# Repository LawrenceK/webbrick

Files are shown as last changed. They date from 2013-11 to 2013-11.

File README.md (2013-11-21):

webbrick
========

webbrick firmware - This will be the open sourced code for the webbrick. As part of the windup of
webbricksystems this code is being open souced under a 3 clause BSD licence, please see licence.txt.

You will need a copy of the FORED WIZC compiler.

You will need a copy of wizc (www.fored.co.uk) note this was built with V14.01 see readme in the PIXIE-diff folder.

You will need the netmedia sitelinker package for the siteplayer.
(http://netmedia.com/siteplayer/webserver/downloads.html)

The build environment also requires a number of unix tools, these can be accessed by installing the cygwin tool kit.
(http://www.cygwin.com/)

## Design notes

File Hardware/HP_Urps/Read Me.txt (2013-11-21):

PCB
PCB Layout in EasyPC V6.0 latest Version V12
http://www.numberone.com/easy_pc_v12.asp
epj file defines the Gerber output

Firmware
Firmware compiled using Oshonsoft PIC Basic IDE
http://www.oshonsoft.com/pic.html

Programmed using Microchip MPLab

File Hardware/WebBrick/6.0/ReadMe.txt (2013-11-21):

Part changes since 23rd April

Switch changes to OMRON device

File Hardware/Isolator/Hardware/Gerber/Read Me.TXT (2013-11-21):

Notes on pads for switches Sw1 and Sw2

Due to the limitations of the PCB CAD system, the pads are shown as an oval shape with 3 holes.  The pad should have a single slotted hole with the two outside holes denoting the limits of the slot.

Please arrange for the CNC router to complete the slots in these pads.

AS.

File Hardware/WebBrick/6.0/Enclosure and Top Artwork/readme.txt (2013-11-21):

.vcd visual cad

Visual Cad - Enclosure.vcd
Export - enclosure.plt
Export - Enclosure.dxf
Export via something - Enclosure.png
Export via something - Enclosure.EPS
Export via something - Enclosure.wmf
Export for freehand - Enclosure.FH10
Final result - Enclosure.doc

11 May 2007
6.4Enclosure supercedes Enclosure.vcd

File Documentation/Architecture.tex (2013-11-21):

\section{Architecture Description}
\index{Architecture Description}

\subsection{Hardware}
\index{Hardware Architecture}

The WebBrick V6 is based around the PIC 18F6x22 chip and a NetMedia SitePlayer \index{SitePlayer} to create 
both HTTP and UDP command channels. The base 8 digital outputs are buffered through a Open collector 
drivers that can handle 12V 500mA drive with reasonable protection.

Some provision is made for input protection from excessive voltage by a combination of a current limiting
resistor and the clamp on the PIC chip inputs, edge triggered inputs are de-bounced in software.

WebBrick uses several properties of the SitePlayer:

\begin{itemize}

\item

SitePlayer can send commands to the PIC ship from its own web interface.

\item

SitePlayer can send commands to the PIC chip received over HTTP and UDP.

\item

The WebBrick can get the SitePlayer to send a UDP packet, the contents of which are 
managed by the PIC chip.

\end{itemize}

\subsection{Software Architecture}
\index{Software Architecture}

The WebBrick is based around a configurable state machine, this is driven by a variety
of triggers. The triggers can be generated by digital inputs, analogue inputs, temperature sensors
and network command. These state machines are configured on what to do when they receive a trigger, this
can be as simple as switch an output on or may involve changing the current scene and sending a network
message to the home gateway.
Although there 
are direct output control commands, in general operation the user configures the inputs to perform 
{\em actions} on outputs.

{\em actions} can be activated by:

\begin{itemize}

\item

Physical input pins, for example taking digital input 0 low momentarily would set the actions configured for 
state engine 0 in motion.  There is a de-bounce time on these circuits.
\item

HTTP request. \index{HTTP GET}

\item

Analogue or temperature inputs above or below configured thresholds.

\item

UDP packet\index{UDP}
\item

Scheduled Event\index{Scheduled Event}

\end{itemize}

\subsection{WebBrick Indicator LEDs}
\index{Indicator LEDs}

	The WebBrick has three indicators, which can been seen through the top translucent window.  They are:
	
	\begin{itemize}
		\item{Red} This indicator shows that the power to the process control and web server chips is healthy.
		\item{Green} This indicator shows that the web server chip is seeing a network link
		\item{Blue} This is the WebBrick heartbeat, it blinks a lot, it has different blinks at start-up, but once
				a WebBrick is running it will settle to a 1 sec blink rate. \(see section below\)
	\end{itemize}

\subsection{WebBrick Start-Up}
\index{Start-up sequence}

When power is applied to the WebBrick, the SitePlayer chip and the PIC chip will start.

It is important that any WebBrick has deterministic behaviour, therefore there is a settling period
before the configuration details from the EEPROM are transferred to the SitePlayer and hence the outside world.

The sequence is:

\begin{itemize}
	\item Power applied to WebBrick
	\item Internal web server  boots
	\item PIC boots waits 1-2 seconds for web server to settle
	\item PIC starts to transfer configuration to web server, this takes about 3 seconds
	\item If the PIC contains an IP address definition, this is set into the web server.  
        	Just before this point the WebBrick will have the 
		default address of 10.100.100.100.
	\item Operational Status set to 'Normal Operation' Interrupts enabled
	\item One Wire Bus searched for temperature sensors
	\item At 30 seconds after power up the internal real time clock is read, it is checked once a minute thereafter.
	\item Schedules are evaluated to see if any actions need to be executed.  i.e. 
		if the WebBrick is started at 10 o'clock and there is a scheduled action at 9 o'clock 
		this action will be executed.  Therefore if a WebBrick was controlling a central heating
		system it would recover from a power failure and carry on where it left off.
\end{itemize}

\subsection{WebBrick Heartbeat}

A LED connected to the PIC chip is used as a Heartbeat to show that the system is working.
It switches on and off at approx 1 second intervals with an equal off and on time once the 
WebBrick has completed its startup.
This LED is driven from the main program loop in the PIC chip.

If it stops flashing then the software has encountered an error, this would be a very dire state and if you ever see it
you should let us know.  We've only ever seen this happen with very noisy power supplies. 

During start-up the Heartbeat will flash quickly.  If the factory reset \index{factory reset} button is held in
at power-up the Heartbeat will remain on for two seconds before starting the load defaults and normal start-up operations.

[Future functionality] If the web interface is logged in then the LED will flash 
faster spending more time on and less time off, if the web home page has its controls disabled it will flash
slower spending more time off than on. [Not yet implemented]

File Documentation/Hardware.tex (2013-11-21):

\section{Hardware Details}

Version 4.2 of the PCB uses the following parts list:

    \begin{description}
    \item [IC1] PIC18F452-I/P (see Gotchas for note on Silicon revision levels)
    \item [IC2] 7805 5V Reg
    \item [IC3] LM358 dual OP Amp, buffers and doubles PWM outputs to give 0-10V
    \item [IC4] 2803A output buffer for 12V 500mA outputs
    \item [Xtal] 20Mhz (could be 40Mhz later)
    \item [Pulse Transformer]
    \item [SitePlayer] See www.siteplayer.com for details
    \end{description}

The following connectors and connections are used:

  \index{Connections}

    \begin{description}
    \item [DIN] Push button inputs, note that the PIC's internal pull-ups are ENABLED
    \item [DOL] Digital Outputs TTL level
    \item [DOH] Digital Outputs 12V 500mA max
    \item [JP4] Rotary Encoder pin 1 'Up' or A, pin 2 'Down' or B.
    \item [JP1 1] Analogue Input 0-5V
    \item [JP1 2-5]  Monitor Input TTL Level     
    \item [JP1 7] One Wire Bus Data \(See Also OWB below\)
    \item [JP1 8] DMX Passthru out TTL Level \(needs MAX232 chip or direct connection to Milford Instruments board\)
    \item [X2 1] Gnd for Analogue output
    \item [X2 2,3] Analogue Outputs
    \item [OWB] One Wire Bus
    \item [V+] A useful source of +5V
    \end{description}

\begin{figure}[H]
\centering

\caption{WebBrick Connections}
\end{figure}

Note that since version 4.2 of the PCB, pull-ups for the rotary encoder are included.

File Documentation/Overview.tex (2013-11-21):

\section{Overview}
\index{Overview}

What is a WebBrick? It is a network connected control and automation product designed around the principle 
of 'local control - global intelligence'. This means that most of the time control is handled locally but a 
system as a whole can be made more intelligent through the use of some central control
(for example the WebBrick Gateway) that provides the global intelligence. i.e. Lights for a room are a local issue, 
but heating is more of an overall control issue. This also means that you are
not dependant on a single control system for the complete system, you can always switch on the lights 
in this room while someone is making changes to a global control system.

Control can be done through a WebBrick's web interface, through its physical inputs or using remote commands.

\begin{figure}[H]
\centering
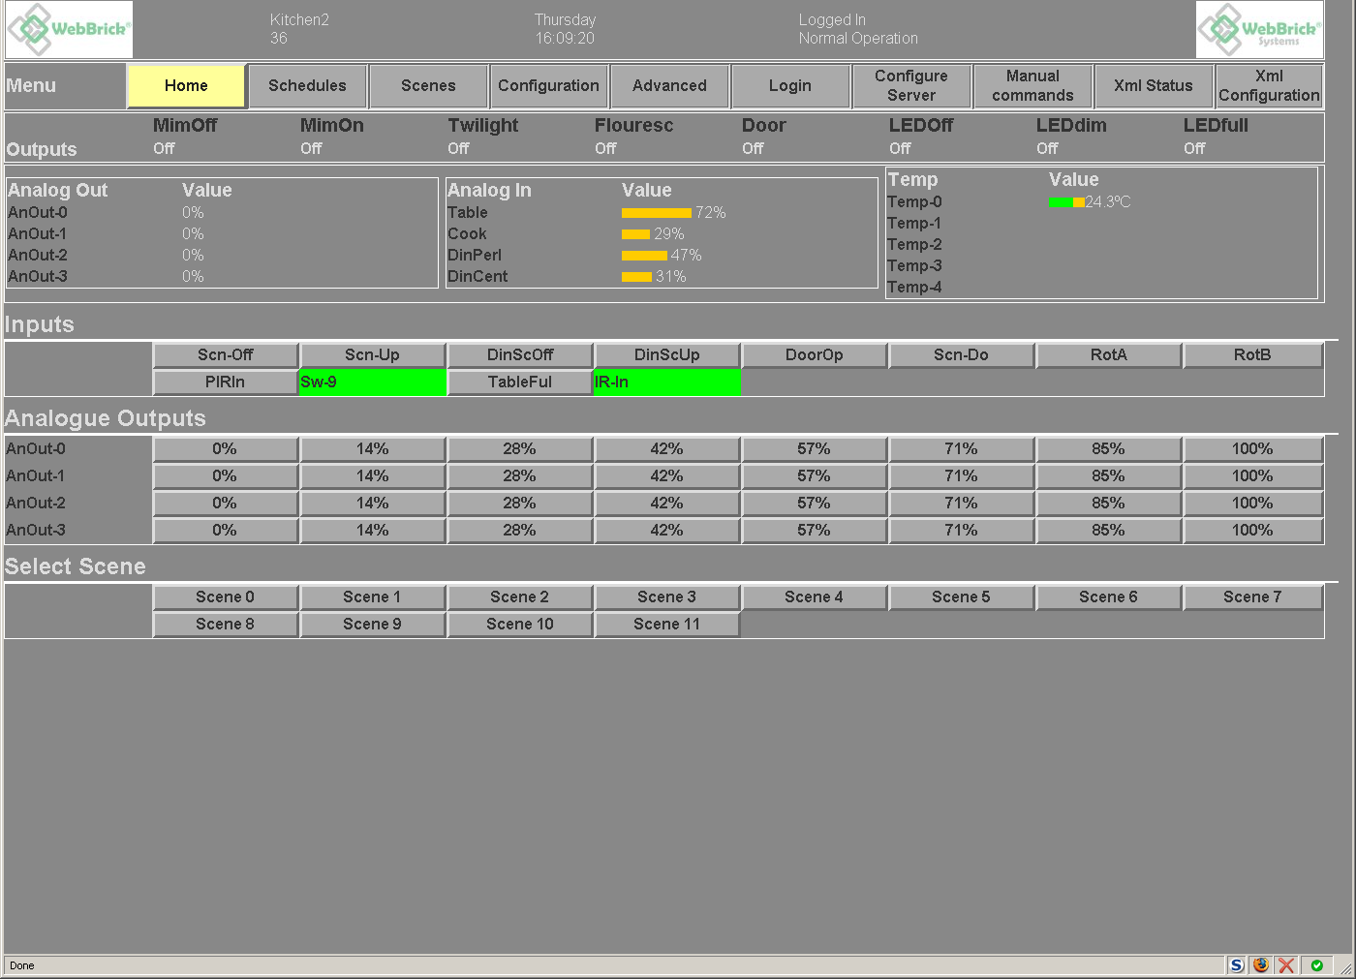
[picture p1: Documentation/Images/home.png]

\caption{Example of WebBrick Home Page}
\end{figure}
\subsection {History}

\index{History of WebBrick}

WebBrick started life as a bespoke project and in that incarnation there are 50-100 of them installed handling
tasks from building security to heating control, the largest setup uses 75+ WebBrick to manage a single house.
The latest incarnations (WebBrick6 and the WebBrick 7 Series) is a commercial project with added facilities.
The V6 WebBrick has an added IO board which provides screw terminals for all connections. It also has 4 Mains switching 
triacs and 2 Double pole changeover relays as well. We can also produce bespoke versions of the IO board
for specific uses.

\subsection {7 Series WebBrick}

The V6.4 WebBrick has the following connections:

\index{connections}

\begin{enumerate}

\item
8 Digital Outputs available as a combination of TTL and Open Collector drives.

In the default configuration 4 digital outputs are connected to mains triacs and can handle up to 500W 
per channel with a maximum of 1500W across all 4 channels. 2 of the Open collector outputs are connected to double pole 
changeover relays. 4 channels are available as TTL outputs.

The open collectors can sink to ground 3A, note that this was previously 500mA on the 6 Series

Digital Out 7 (TTL) can drive RC5 IR sequences to a suitable IR LED.

\item
8 Mimic outputs.  These are available at TTL and 12V levels are used to indicate the state of the WebBrick outputs.
The main functions of these mimics is to drive indicator LEDs found on push buttons. They are PWM modulated so that the
brightness can be modified for the on and off phases. The internal analogue and digital outputs can be configured to set 
the mimics to the on or off brightness(0..63) levels or they can be directly controlled from a system external to the WebBrick.

\item
12 Digital Trigger Inputs, TTL level - These can be treated as de-bounced push-buttons or toggle [MK] style inputs.  
The actual trigger point can be the rising edge, falling edge or both. When used in adjacent even/odd pairing Digital inputs will support 
rotary encoders.

All inputs have weak pullups so that switches can be connected with no further components involved.

Digital Input 11 can be configured to accept RC5 IR commands when connected to a suitable sensor.

\item
4 Analogue Outputs 0-10V. When the output level is changed, a new target value is set, these outputs 
adjust the output value over a time period (Fade Rate). Fade Rate is adjustable and can be as short as 200mS for full range 
change or as long as 50 Seconds.

\item
4 Analogue Inputs These are 0-5V input, high impedance - 47K, care must be taken not to exceed 5V on this pin, 
the web interface displays 0-100.

\item
One Wire Bus for up to 5 off Dallas DS18B20 temperature sensors.  On the 7 series the 5V supply and ground are specifically for temperature and humidity sensors.  The 5V supply is is specially decoupled and is limited to 10mA.  As a historical note this change was made to protect the WebBricks from shorts or excessive noise on sensors lines.

\item
RJ45 connection for 10Mb/s Ethernet.

\item
Serial output that can be configured for RS232, RS485 or DMX protocols.

\item
12V power connection

\end{enumerate}

\subsection {The Version 6.4 WebBrick}

The V6.4 WebBrick has the following connections:

\index{connections}

\begin{enumerate}

\item
8 Digital Outputs available as a combination of TTL and Open Collector drives, with an option for 8 more on bespoke 
developments. 
In the default configuration 4 digital outputs are connected to mains triacs and can handle up to 500W 
per channel with a maximum of 1500W across all 4 channels. 2 Of the Open collector outputs are connected to double pole 
changeover relays. 4 channels are available as TTL outputs.

\item
8 Mimic outputs.  These are available at TTL level are used to indicate the state of the WebBrick outputs.
The main functions of these mimics is to drive indicator LEDs found on push buttons. They are PWM modulated so that the
brightness can be modified for the on and off phases. The internal analogue and digital outputs can be configured to set 
the mimics to the on or off brightness(xx) levels or they can be directly controlled from a system external to the WebBrick.

\item
12 Digital Trigger Inputs, TTL level - These can be treated as de-bounced push-buttons or toggle [MK] style inputs.  
The actual trigger point can be the rising edge, falling edge or both. All inputs have weak pullups so that 
switches can be connected with no further components involved.

\item
4 Analogue Outputs 0-10V. When the output level is changed, a new target value is set, these outputs 
adjust the output value over a time period (Fade Rate). Fade Rate is adjustable and can be as short as 200mS for full range 
change or as long as 50 Seconds.

\item
4 Analogue Inputs This is a 0-5V input, high impedance, care must be taken not to exceed 5V on this pin, 
the web interface displays 0-100.

\item
One Wire Bus for up to 5 off Dallas DS18B20 temperature sensors.

\item
RJ45 connection for 10Mb/s Ethernet

\item
12V power connection

\end{enumerate}

Note that the Rotary Encoder connections from the pre 6.2 WebBrick have been incorporated into standard Digital Inputs, up to
6 rotary encoders can be supported.

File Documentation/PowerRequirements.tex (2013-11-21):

\section{Power Requirements}
\index{Power Requirements}

 This section deals with the power budget required to run a WebBrick.
 
 \subsection{Power Supply}
 \index{Power Supply}
 
    WebBricks should be run from a power supply that delivers 12.6V to 18V.  12.6V is a minimum to achieve a full 0-10V range on
    the analogue outputs.
    
    A quiescent WebBrick will consume 55-60mA at 12.6V, however the WebBrick in real use will be supplying power to a range of external items
    including:
 	
\begin{itemize}

\item{\bf LEDs} The WebBrick may drive up to 8 mimic LEDs, each consuming 5mA. {\it 40mA}

\item{\bf Relays} There are two relays, each using 30mA to hold the contacts closed. {\it 60mA}

\item{\bf Temperature Sensors} There may be up to 5 sensors, these are driven periodically. {\it 5mA peak}

\item{\bf Analogue Outputs} There are four buffered 0-10V outputs each capable of supplying 20mA. {\it 80mA}

\item{\bf General Output Drive} The digital outputs can each supply 5mA, although only four are presented as TTL.
if a rotary encoder is connected it will use 2mA.  Driving the triac and open collector gates requires 2mA each. {\it 40mA}

\end{itemize}

Total power budget, all outputs driven, all sensors connected 280mA.

\subsubsection{Back Feed}
\index{Back Feed}
 	
    Because the WebBrick consumes so little current, it is possible to inadvertently 
    power it through the coils of external relays connected to 
    the open collector outputs.  This only becomes an issue if one needs to fully power 
    down a WebBrick. To avoid this situation we suggest
    that the +ve side of relay coils are driven from the same power supply as drives the WebBricks.

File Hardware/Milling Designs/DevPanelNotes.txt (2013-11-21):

Notes for Milling Dev Panel
===========================

Holes -2.6 mm at 0.3mm increments.

Engraving -0.3 at 0.2mm increment

Home is at the very Left Hand Bottom Corner

Side Panel

Holes -1.9 mm at 0.3mm increments.

Home is where lines cross just on the inside of the screw columns

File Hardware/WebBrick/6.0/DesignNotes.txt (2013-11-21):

Use higher male connector.

Assembly

Download to SP on 192.168.1.250

Then Program PIC.

Make sure correct parts list to manufacturer.

Adjust position of screw holes in IO board, slightly too close together.

Factory test software. Test RTC.

Clock crytsla on bottom, case soldered. Add small cap as well.

Case drawings to subversion.

POE version.

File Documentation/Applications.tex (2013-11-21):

\section {Applications}

Here we provide some examples of use of the WebBrick. The great thing with the WebBrick is that a single device can
provide more than one activity. For example PIRs, can trigger video recording at all times. Can switch lights at night. 
Sound warning tones. In typical monitoring systems you need multiple devices because they do not interlink.

\subsection {Heating}

The notes in this section mostly consider that a WebBrick is taking the whole controller role.  Of course it's possible to
add extra global intelligence using a general purpose host computer, for example the WebBrick Gateway.

\subsubsection{Thresholds as set points}
\index{Thresholds}

	In the WeBrick architecture we use temperature sensors rather than thermostats.  We do this for a variety of reasons:
	
	\begin{itemize}
		\item{Controls} - there are no external controls for a temperature sensor.  This means that it can be sited
		where it both makes sense and is convenient.  For example under a kitchen worktop or directly bonded to a heated
		floor.
		\item{Accuracy and repeatability} - Old fashioned bi-metal strip thermostats close at one temperature and open at another.
		Adjusting the set-point is a mechanical operation.  Whereas the sensors we use have resolution to 0.1 deg C and an accuracy
		of 0.5 deg C.
		\item{Remote Control} - Using sensors to read the temperature means that the actions on thresholds are defined within the
		WebBrick.  Therefore the set points can be adjusted on a web page
	\end{itemize}

	With version 6.1 of the WebBrick it is now possible to control thresholds as an action.  Actions can be triggered from Digital Inputs
	and from Schedules.  We can also raise actions from multiple temperature sensors, so we can create zones and frost-stat functionality.
	
	Therefore if we build a heating control scheme using WebBricks we can schedule changes of set-points using thresholds.  We can also
	create {\em Boost} buttons that increase set-points.

\subsubsection{Modern Combi boiler, single Zone}

These generally have power applied all the time which is used to provide hot water and the central heating
is controlled by a mixture of a thermostat and timed events. In this case we would use scheduled events to
control the triacs and relays.  For example the output a triac feeding a relay that is controlled by one
of the temperature sensors using under and over thresholds. In effect the triac replaces the time switch
and the relay replaces the standard thermostat. The great benefits of this are:

	\begin{itemize}
		\item that the control can then be 
		overridden by local buttons for boost (e.g. Dwell 1 hour on boiler output)
		\item the use of a Home gateway system can use its calendar to switch heating off when home is empty. 
		\item a home gateway can access local weather feeds to adjust switch on times dependant on temperature forecasts.
		\item using the home gateway the home owner can control and make changes whilst away from the house, e.g. going home early.
	\end{itemize}

\subsubsection{Two zone heating system}
In this case we drive the boiler off a mains triac that is driven from a schedule entry. And drive two 
zone valves off the two relay outputs, these are triggered by high and low thresholds on two 
temperature sensors. Advantages are as for single Zone.

\subsubsection{Electric under floor heating}
These are great ways of heating floors for things like bathrooms but electricity is not the cheapest
heating source if over used.
So it would be nice for them to come on for timed periods and be able to boost at other times. 
In this case a single output can control the power to
the floor controller, this can be switched by timed events for getting up time and a push button to boost 
it at other times.

Note it is not always best to chain Triac based controllers so if the underfloor heating controller
uses a Triac we recommend using a Relay to power the floor from the WebBrick. Also underfloor heating 
can need power greater than the abilities of the onboard Triacs so an external relay is a good idea.

\subsubsection{Air conditioning}
Controlled by an external relay as the power consumption of these is higher than can be handled directly.
Control by a mix of time schedules and temperature thresholds.

\subsection{Outside lighting/Security Lighting}
This could be as simple as lighting that is timed to come on at dusk until dawn or it could be controlled
by PIR sensors that switch on all the lighting around a house. The PIR sensors may not necessarily be on the same 
WebBrick as the lights. For example on a big building there may be lights on all 4 sides of the building driven by 
different webBricks, on sensing movement on one side you may bring that side up to full brightness and all the other
sides to half brightness.

\subsection{Internal lighting}

\subsubsection{Night Lights}
Especially with the very young and very old it is great to have some low level lighting around a house at 
night, modern LEDs are very good for this drawing very little power. For one or two devices they can be 
switched directly from the digital outputs for heavier loads 3 in series with a resistor can be driven 
from a 12V supply and the open collector driver. If the power supply for a WebBrick is a sealed lead acid (SLA) battery
then this could also provide power for the LED lights so that they stay on during power cuts. With the low power
requirements the system could stay running off a 7 Amp Hour SLA battery for hours if not days.

Maplin (www.maplin.co.uk) 12V 7Ah battery (MG47B) £25, Charger (LL30H) £13.
TLC-direct (www.tlc-direct.co.uk) 12V 6AH battery £10+VAT

\subsubsection{Dimming lights}
For this: use dimmers that accept a 0-10V DC control voltage and wire these to the analogue outputs
from the WebBrick. For example the soundlab G018VA 4 channel dimmer can handle 4 channels of 5A each 
(Max 16A for the Unit).
(See also section on Outside World).

\subsection{Alarm Monitoring}
By connecting dry contacts from fire and burglar alarms to the WebBrick monitor inputs the WebBrick
in association can display the state of the alarm on a central display.The home gateway could then 
send SMS or email messages to alert the home owner. E.g. via www.textanywhere.com.

\subsubsection{Water sensors}
In the case of property in low lying areas water sensors could be installed in basements and under 
floor voids and configured to generate alarms.

\subsection{Household services}

\subsubsection{Water softener}
A sensor could be added to a water softener to detect low salt levels and alert the household through a central
display, especially useful when the device is installed in a basement where it is easily forgotten!

Capacitive sensors are particularly useful for sensing salt levels where the softener has GRP or plastic side walls.

\subsection{Home Cinema}
A home cinema setup can include more than just the audio and video equipment, you may 
also have (for example) roller screens and blackout curtains.

\subsection{Access control}

\subsubsection{Entry gates and doors}
With the use of RF remote systems connected to a WebbRick control of electric gates and garage doors can be handled
through a single system, the WebBrick. You can open gates and doors from the house before braving the elements to get 
access to your car and can then close them from the car as you leave the premises. When video is used as well you can 
open doors from work when your cleaner arrives as you will get a message when the door bell is pushed, you then check the 
camera system verify the identity and let release the front door.

\subsubsection{Camera systems}
A PIR trigger can be set up to start a camera system recording video images which are made available to you on a web interface.

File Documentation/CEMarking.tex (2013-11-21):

\section{CE Marking}

\index{CE Mark}

WebBrick WB10B60 is in conformity with the essential requirements of the directive 1999/5/EC. The product has been tested
 to the standard EN55022:1998 "EMC emmissions and immunity", using the limits described on EN55022 Class B CISPR22(B).

\subsubsection{General Description}

\subsubsection{Risk - High Temperatures}
\index{Risks ! High Temperatures}

The WebBrick has 4 triacs each rated at 2A with an overall rating of 6.3A.  If 6.3A of 240VAC is drawn through the WebBrick
the triacs will dissipate around 7W of heat.  There is sufficient heat sinking in the WebBrick to cope with this.  Internal temperatures
can rise to 85 Deg C.  It is important that the WebBrick is not housed in small totally enclosed areas.  Air circulation is best when the 
WebBrick is mounted in the vertical plane.

\subsubsection{Risk EMI}
\index{Risks ! EMI}

Since the WebBrick uses a number of microprocessors, it may be prone to electromagnetic emissions if it is not installed properly.  The current
standards are stringent and require that a typical installation radiates less that 2 nano watts of power in the RF range.

We recommend that CAT 5/5E/6/7 type cables are used and one core of each pair is connected to ground.

Further we suggest that you use a good quality clean 12V supply to the WebBrick to ensure that supply borne noise is radiated via the ground plane.

It is not a requirement to connect the mains ground to the electronic ground of a WebBrick.  However, please note that if you use the triacs for 
mains loads then the protective mains ground should be connected.  There is no internal connection between this protective ground and the 
electronic ground.

\subsubsection{Risk Software Failures}
\index{Risks ! Software}

The WebBrick contains about 40K assembler code, whilst this has been thoroughly tested, 
software errors cannot be ruled out.

\paragraph{WebBricks should not take the place of safety systems or override safety systems.}

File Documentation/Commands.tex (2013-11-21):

\section {Command Structure}
\index{command structure}

The WebBrick has a command interface that accepts command strings, these can be generated
by the Web interface and can also be sent to the WebBrick over the network. For network delivery
the commands can be sent using an HTTP URL with the command encoded in the parameters or a UDP transmission,
the HTTP use is preferable as you get an indication of whether the command was received at the WebBrick.

\subsection{General}
\index{Command Structure, General}
All commands start with a 2 character identifier, and are followed by any required parameters and terminated 
by a colon (':') character after the parameters, 
which means end-command. Each parameter to a command is terminated by a semi-colon (;). In this document 
items in \param{is a user parameter} 
and should be replaced with real world values. Items in [...] are optional parameters, therefore are not essential to replace. Generally the first character within the 2 character 
identifier identifies the command group and the second identifies the entity type. No extra blank spaces should
be inserted into the command as unexpected things may happen or the command be rejected.

These commands can be sent to the WebBrick in two ways:

\begin{enumerate}
	\item By encoding the parameters into 
	an HTTP URL and accessing that URL
	\item or by sending a UDP packet to the WebBrick with a 
	correct Siteplayer header on it for delivery to the PIC chip. 
\end{enumerate}

The embedded UI uses the 
HTTP URL approach and it is recommended that this approach is used for external systems. If you want
to use UDP packets look at the python code in wbUdp.py for details.

The HTTP URL to be used is http://\param{ip Address}/cfg.spi?com=\param{commandString}
Where \param{ip address} is the WebBricks IP address or host name.
and \param{commandString} is one of the command strings documented here. Note some commands will
need you logged in for them to be processed.

To make it easier to understand the command strings the first character is generally used as follows:

\subsubsection{command groups}
\begin{tabular}{l|p{12cm}}
1st Letter&Command Group\\
\hline
C&Configure\\
S&Set\\
N&Name\\
D&Digital\\
A&Analogue\\
I&Infra Red\\
T&Thresholds\\
\end{tabular}

And the second character generally identifies the target channel type, as follows:
\subsubsection{entity type}
\begin{tabular}{l|p{12cm}}
2nd Letter&entity type\\
\hline
D&Digital input\\
A&Analogue Output\\
I&Analogue input\\
O&Digital Output\\
T&Temperature\\
C&Scene\\
R&Serial comms or rotary encoder\\
\end{tabular}

\subsubsection{Trigger Configuration}
\index{Trigger!configuration sequence}
\index{Trigger sequence}
A lot of the commands take a sequence of parameters referred to as a Trigger sequence, this 
defines what is to happen when a trigger event occurs, for example a digital input or 
a temperature threshold being crossed. 

The sequence of parameters is:

\param{A\textbar{}D\textbar{}S\textbar{}T\textbar{}I}\param{targetChn}; \param{SetPointNr}; \param{actionType}; \param{DwellNr}; \param{UDPType}; \param{AssociatedValue} [; \param{OptValue}]:

Where:

\begin{tabular}{l|p{12cm}}
Parameter&Description\\
\hline
\param{A\textbar{}D\textbar{}S\textbar{}T\textbar{}I}&is a single character that identifies whether the target channel is an 
analogue output(A), a digital output (D), a Scene (S), a Temperature sensor (T), or Infra Red Send\\
\param{targetChn}&is the channel number or Scene being targeted\\
\param{actionType}&is one of the values from the Action table (range 0-15) In the case of a Scene this
is used as the action for all analogue channels that are not marked to be ignored and for digital 
channels marked for On in the scene configuration.\\
\param{DwellNr}&is a dwell number and is ignored if the actionType is not a dwell. Note for DT command dwell 
is passed in seconds and not as a dwell index.\\
\param{SetPointNr}&is a setpoint number and is ignored if the target channel is not analogue, Note a Scene is
not an analogue channel and the SetPoint is taken from the Scene.\\
\param{UDPDo}&identifies whether a UDP packet type is to be sent\\
\param{AssociatedValue}&is a number associated with the action.\\
\param{OptValue}&is an optional reserved value.\\
\end{tabular}

\subsubsection{Actions}
Each trigger can cause one of the following actions to be performed on an output channel.

\begin{tabular}{l|l|p{12cm}}
Nr&Action&Description\\
\hline

0&None&no action\\
1&Off&switch off\\
2&On&switch digital channels on or an analogue channel to a setpoint.\\
3&Momentary&Switch a channel on for a small time period circa 200mS.\\
4&Toggle&Turn an on channel off and an off channel on. For analogue channels if the current setting is greater than 0 it is deemed to be on.\\
5&Dwell Always&Always Switch a channel on for a configured time period, if lamp already on this will switch off after a time period.\\
6&Dwell-Cancel&If a channel is Off Switch the channel on for a configured time period. 
If the channel is already On then switch the channel Off immediately.\\
7&Next&Move a channel to its next higher state, for analogue channels this is to the next set point, for digital channels this is equivalent to a toggle. If the target is any Scene change the current scene at the web brick up by one.\\
8&Prev&Reverse of Next, Down Setpoint, Toggle, Previous Scene.\\
9&SetLowThreshold&Change the low threshold for one of the analogue input or temperature sensor\\
10&SetHighThreshold&Change the high threshold for one of the analogue input or temperature sensor\\
11&AdjustLowThreshold&Move the low threshold for one of the analogue input or temperature sensor\\
12&AdjustHighThreshold&Move the high threshold for one of the analogue input or temperature sensor\\
13&SendIR&Send a command over the Infra Red emitter, RC5 only, the target RC5 channel is the command code 
and associated value is the RC5 address.\\
14&Up&Take a channel up a step, generally used for analogue outputs.\\
15&Down&Take a channel down a step, generally used for analogue outputs.\\
16&Set Dmx&Set a DMX channel to a level.\\
17&Count&Sets the channel to count mode.\\
18&Dwell On&Switch a channel on for a configured time period if it is not already on.\\
19&Dwell Off&Switch a channel off after a configured time period.\\
\end{tabular}

Notes
\begin{itemize}
\item Toggle, On and Off actions all override a current Dwell command.
\item A Dwell command issued during a current Dwell period will reset the Dwell time.
\item A Dwell Cancel command issued during a current Dwell period will end the dwell. A Dwell Cancel issued 
outside a Dwell period will switch the output on for the Dwell time.
\item At the end of an analogue dwell the output will return to the level prior to the dwell, this 
is useful for setting lights
to a low level and bringing them high on some trigger, e.g. security PIR.
\item Channel numbers are zero based for the internal commands.
\item Scenes are in two banks, one bank of 8 and one bank of 4, when performing Next and Prev Scene the scene change 
stays within the bank that the trigger definition identifies by selecting one of the scenes within the chosen bank.
\item String parameters cannot contain any of the characters '\textless{}\textgreater{}\&
\item Analogue channels go up and down setpoints with Next/Prev and step the level the rotary step value with Up/Down \&
\item Some commands are meaningless with some outputs, where possible reasonable actions are chosen. i.e. for digital 
channels Next/Prev/Up/Down are treated as a toggle command\\
\end{itemize}

\subsection{Error Codes}
These may be displayed in the header of the webbpage and may appear in the xml status.

    \begin{tabular}{l|l}
    Value&Description\\
    \hline
    0&No Error.\\
	1&Bad Command.\\
	2&Bad Parameter.\\
	3&Not Logged In.\\
	4&Address Locked, attempt to change IP address on address locked webbrick.\\
	5&In Startup state.\\
	6&No Command yet issued, post startup state.\\
    \end{tabular}
	
\subsection{Command summary}

\subsubsection{Static configuration commands}

\begin{tabular}{l|p{12cm}}
Command&Function\\
\hline
ND&Name digital Input\\
NO&Name digital output\\
NI&Name analogue input\\
NA&Name analogue output\\
NT&Name temperature sensor\\
NN&Name node\\
CD&Configure digital input\\
CI&Configure analogue input\\
CT&Configure temperature input\\
CS&Configure set point\\
CW&Configure dwell\\
CR&Configure serial interface.\\
CE&Configure scheduled event\\
CC&Configure a scene\\
SN&Set node number\\
SF&Set fade rate\\
SM&Set mimic brightness levels for on and off signals, and fade rate\\
CM&Configure mimic channels for analogue and/or digital outputs\\
ST&Set Time\\
SD&Set Date\\
SR&Set rotary encoder step\\
SI&Set Internet address\\
SA&Set IP address with verified MAC address; the !WebBrick sets its IP address to the specified value only if its 48-bit MAC address matches that supplied.  This command can be used with UDP broadcasts to set IP addresses when several WebBricks on a network have the same initial IP address.\\
SP&Set password for indicated security level\\
SO&Set option on (1) or Off (0) (Use with care: currently deprecated, and not reflected in XML configuration)\\
IR&Enable infrared receive\\
IT&Enable infrared transmit\\
IA&Sets the RC5 Infrared address for receiving\\
% Private command.
%ZO&Security option setting (e.g. IP address locking)\\
\end{tabular}

\subsubsection{Dynamic status setting commands}

\begin{tabular}{l|p{12cm}}
Command&Function\\
\hline
DI&Trigger digital input\\
DO&Set digital output\\
DT&Invoke a trigger event action using the supplied parameters. The parameters are a full trigger definition as can
be attached a local event source, i.e. digital input, but are acted upon when received. Note dwell is passed in seconds and not as a dwell index.\\
DM&Set one or more mimic outputs to specified levels\\
DA&Requests web brick to send a small number of UDP attention packets within a few seconds (currently: one immediately, and one more within a second).  This is used for WebBrick discovery.  (cf. factory reset causes attention packets to be sent every few seconds for a minute.)\\
AA&Set analogue output to one of the setpoints or to an absolute level.\\
SC&Set scene\\
SS&Set operational state\\
TA&Modify dynamic threshold for analogue input\\
TT&Modify dynamic threshold for temperature sensor\\
\end{tabular}

\subsubsection{Miscellaneous WebBrick control commands}

\begin{tabular}{l|p{12cm}}
Command&Function\\
\hline
LG&Login to security level associated with password - also logout.\\
RT&Re scan 1-wire bus for new devices\\
RU&Refresh web user interface data\\
RS&Reboot Siteplayer, PIC chip delays a while and then rebuilds the UI data.\\
RB&Reboot PIC\\
RI&Set RS485 driver off, input mode\\
RO&Set RS485 driver on, output mode\\
RD&Send serial data\\
IS&Sends an RC5 infrared command (channel) over a configured infrared emitter\\
\end{tabular}

\subsection{Commands}

All command are listed here.

\subsubsection{AA - Analogue output control}
\index{Analogue output control}
\index{Analogue Output ! control sequence}
AA\param{chn};[S\param{nn}\textbar{}\param{nn}]  Set Analogue output setpoint or absolute

Set an analogue output to a specific level.
chn is the analogue output channel number. If the output value is S\param{nn} then \param{nn} is the setpoint,
otherwise \param{nn} is the output level as an absolute value of between 0-100\%. 

e.g.
AA1;S1:

\subsubsection{CC - Configure Scene}
\index{Configure Scene}
CC\param{nr};[NFI][NFI][NFI][NFI][NFI][NFI][NFI][NFI]; [I\textbar{}S\param{nn}]; [I\textbar{}S\param{nn}]; [I\textbar{}S\param{nn}]; [I\textbar{}S\param{nn}]:

Configure a scene. A scene consists of optional settings for all the digital and analogue channels. Any channel
may be marked as Ignore (do not change). Digital channels also be marked as On or Off, whilst analogue channels
can be given a set point. The first group [NFI] is for the digital channels and is repeated as many times 
as required to cover the digital channels where a change is required, i.e. if you only want to modify 
digital channels 0, 1, 2 then you only need list 3 entries. If you want to only affect channel 8 (or 16) then
you must send all the preceding ignore's (I). Similarly for the analogue channels where each later entry is
optional if you have already specified the required changes.

e.g.
CC0;NFNFNFNF;I;S1;S2;S3:
CC1;NF:
CC3;NF;S0;S1;S2;S3:

\subsubsection{CD - Configure Digital Input}
\index{Configure Digital Input}
CD\param{chn}; \param{A\textbar{}D\textbar{}S}\param{targetChn}; \param{sp}; \param{actionType}; \param{dwell}; \param{udpType}; \param{AssociatedValue} [; \param{OptValue} [; \param{Options}]]:

Configure one of the digital inputs.
chn is the digital input channel number from 0 to 7 (or more). Remaining parameters are a Trigger Sequence.
Options is a set of flags that controls the digital input event generation.

\index{Options, Digital Input}
\begin{tabular}{l|l|p{12cm}}
Bit&Value&Description\\
\hline
0&1&generate trigger event on rising edge, i.e. 0v to 5v transition.\\
1&2&generate trigger event on falling edge (Default) i.e. 5v to 0v transition, a normally open switch is pressed.\\
2&4&This input and the next is connected to a rotary encoder, when the rotary encoder is turned 'down' this trigger is actioned\\
3&8&\\
4&16&\\
5&32&\\
6&64&\\
7&128&\\
\end{tabular}

To create the option value add the required Value's from the above table together.
For example an option value of 3 (1+2) would set both rising and falling edge flags and this is useful if you have a latching switch of some sort, 
i.e. standard MK light switch.

e.g.
CD7;A1;2;2;0;1;1:
Configure Digital in 7 to target analogue output 1. setpoint 2, action On(2), dwell (0) ignored, UDP

\subsubsection{CE - Configure scheduled event}
\index{Configure scheduled event}
CE\param{chn}; \param{Days}; \param{hours}; \param{Min}; \param{A\textbar{}D\textbar{}S}\param{targetChn}; \param{sp}; \param{actionType}; \param{dwell}; \param{udpType}; \param{AssociatedValue}[; \param{OptValue}];

Configure scheduled event.
chn is event number, currently 16 scheduled events are catered for. Days is a set of day numbers 
from 0-6 to identify which days the event occurs on, e.g. "06" is Sunday and Saturday. hours (0-23) 
and min (0-59) identifies the time within the day when it occurs. 
The remaining parameters constitute a Trigger set as described else where,

e.g.
CE6;12345;12;30;A1;2;2;0;1;1:
Configure event 6, at 12:30 on Mon to Fri to target analogue output 1. setpoint 2, action On(2), dwell (0) ignored, UDP. 

\subsubsection{CI - Configure Analogue Input}
\index{Configure Analogue Input}
CI\param{chn}; \param{L\textbar{}H}; \param{Threshold}; \param{A\textbar{}D\textbar{}S}\param{targetChn}; \param{sp}; \param{actionType}; \param{dwell}; \param{udpType}; \param{AssociatedValue}[; \param{OptValue}];

Configure one of the analogue inputs.
L or H identify whether this is setting a High or Low threshold and Threshold is the analogue threshold
as a value from 0-100\%. The low level hardware is 0-5V but so as to avoid issues when some signal
conditioning is added the input is scaled.

e.g.
CI0;L;20;A1;2;2;0;1;1:

\subsubsection{CM - Configure Mimics}
\index{Configure Mimics}
CM\param{A\textbar{}D}\param{source}; \param{mimicChn}[...]:

Configure mimic channels for one or more analogue and/or digital outputs.

      A target indicates an analogue output number target for a which a mimic channel is specified

      D target indicates an digital output number target for a which a mimic channel is specified

      mimicChn indicates a mimic channel number that will be associated with the corresponding 
      analogue or digital output, to break the connection between a channel and a mimic use a mimic channel
      number of 15.

Pairs of outputs and corresponding mimic channels may be repeated for each association that is 
required to be specified. (Or, a separate command may be used for each.)

The default setting is that Digital outputs 0 to 7 are associated with mimic output 0-7. The off level and
on level can be reconfigured with the SM command.

e.g.
CMA0;0;A1;1;A2;2;A3;3:
target mimics 0 to 3 from analogue 0 to 3.

\subsubsection{CS - Configure Preset point}
\index{Configure Preset point}
CS\param{chn}; \param{val}

Configure one of the set points (Preset point) used for the analogue outputs.
chn is the setpoint number and val is the setpoint value in the range 0-100\%. The low level hardware 
generates 0-10V but this may be passed through some signal conditioning to suit the application.

\subsubsection{CT - Configure Temperature Sensor}
\index{Configure Temperature Sensor}
CT\param{chn}; \param{L\textbar{}H\textbar{}B}; \param{Threshold}; \param{A\textbar{}D}\param{targetChn}; \param{sp}; \param{actionType}; \param{dwell}; \param{udpType}; \param{AssociatedValue}[; \param{OptValue}];

Configure one of the temperature inputs.
L or H or B identify whether this is setting a High or Low or Both threshold(s) and Threshold is the temperature threshold
as a decimal temperature between -50 and +150 degrees Celsius

\subsubsection{CR - Configure Serial}
\index{Configure Serial}
CR\param{mode}; \param{baudIdx}:

The following modes exist:
\begin{tabular}{l|l|p{12cm}}
mode&Description\\
\hline
0&No mode change.\\
2&RS232.\\
4&RS485\\
3&DMX mode\\
\end{tabular}

The following baud rates exist:
\begin{tabular}{l|l|p{12cm}}
index&Speed\\
\hline
0&300\\
1&600\\
2&1200\\
3&2400\\
4&4800\\
5&9600\\
6&19200\\
7&38400\\
8&57600\\
9&115200\\
10&250000\\
11&9600\\
12&9600\\
13&9600\\
14&9600\\
15&9600\\
\end{tabular}

See commands RO, RI, RD

\subsubsection{CW - Configure Dwell}
\index{Configure Dwell}
CW{\it [0-3];DwellValue}:

There are 4 Dwell values that may be set, 0-3.
DwellValue is a number between 2 and 32767, it is measured in 'near seconds'.
Dwell is measured in more or less seconds.
Note that it is the transition between 1 and 0 that marks the end of a Dwell countdown, 
therefore a Dwell value of 10 really gives a Dwell of between 9 and 10 seconds, depending on
when it was started.
\index{Dwell!command sequence}

\subsubsection{DA - Do Attention}
\index{Attention}
DA

Request the WebBrick to send 1 or 2 attention packets, command is generally sent using UDP and broadcast
to all WebBricks on the network.

\subsubsection{DI - Trigger Digital input}
\index{Trigger Digital input}
DI\param{chn}

Trigger input, generates a trigger just as if digital input chn had been triggered.

\subsubsection{DM - Do Mimic}
\index{Do Mimic}
DM\param{mimicChn}; \param{mimicLevel}[; \param{mimicChn}; \param{mimicLevel}]

Set one or more mimic channels to a set level. The mimic channel and level can be repeated to send more than one
request in a single command. This overrides the values set by any recent output change targeted to the mimics
at the WebBricks. mimicLevel can be between 0 and 63.

\subsubsection{DO - Switch Digital output}
\index{Switch Digital output}
DO\param{chn};N\textbar{}F\textbar{}T\textbar{}D[; \param{dwell}]:

Set digital output. Sets the state of one of the digital outputs.
chn is the channel number to operate.

\begin{tabular}{l|p{12cm}}
Action&Description\\
\hline
N&On\\
F&Off\\
T&Toggle\\
D&Dwell\\
\end{tabular}

If Dwell is specified then this can either be a DwellNumber \param{0-7} or if greater than 7 is a dwell in seconds.  If you really want to issue a dwell you're much better
off considering the DT command, this gives you more control from the gateway since you need not worry if the dwell times have been reconfigured at the WebBrick.

\subsubsection{DT - Trigger from External}
\index{Trigger from External}
DT; \param{A\textbar{}D\textbar{}S}\param{targetChn}; \param{sp}; \param{actionType}; \param{dwell}; \param{udpType}; \param{associatedValue}; \param{optValue}[; \param{options}]]:

The packet contains trigger configuration which is actioned on receipt and not stored for later use. This
enables an external source to do what an internally generated event can do. 

{\em NOTES:}

\begin{tabular}{l|p{12cm}}
Parameter&Notes\\
\hline
dwell&This is set in seconds and not an index into the dwell table\\
udpType& this is either 0,None or 1,Send\\
associatedValue&If this is relevant to the action then this can be set\\
optValue&This is not used and should be left at 0\\
options&This is not used and should be left at 0\\
\end{tabular}

\subsubsection{FR - Factory Reset}
\index{Factory Reset}
FR  Configuration Factory reset.

FR1  Full Factory reset.

Perform a factory reset of the WebBrick, the base version only resets user configuration, the later version also resets 
all options and the IP address (Unless IP address locked at Factory).

\subsubsection{IA - InfraRed Address}
\index{InfraRed}
IA\param{address}:

Sets the RC5 infra red address to be recognised. The command values 1-8 are mapped to generating digital triggers, 
i.e. another soft key input.

\subsubsection{InfraRed On Off}
\index{InfraRed}
IR\param{N\textbar{}F}:

Switch on/off infra red reception, uses Digital input 11 and disables any other use for this connection.

\begin{tabular}{l|p{12cm}}
Action&Description\\
\hline
N&On\\
F&Off\\
\end{tabular}

\subsubsection{IS - InfraRed Send}
\index{InfraRed}
IS\param{address}; \param{channel}:

Sends the IR command using RC5 and the address (0-31) and channel (0-63) given. Allows a remote system
to send RC5 infra red commands.

\subsubsection{IT - InfraRed emitter}
\index{InfraRed}
IT\param{N\textbar{}F}:

Switch on/off infra red transmission. Uses DigOut 7 and disables any other use for this connection.

\begin{tabular}{l|p{12cm}}
Action&Description\\
\hline
N&On\\
F&Off\\
\end{tabular}

\subsubsection{LG - Login and Logout}
\index{Login}
LG; \param{password}  

Try to login to the WebBrick to enable the command interface. Up to 3 passwords may be set
Level 1 allows access to the Home page controls, its default is blank so the WebBrick
automatically enters this state.
Level 2 is for reconfiguration
Level 3 is full reconfiguration access for installers.
Note Login times out 5 minutes after the last valid configuration command (Level 3 is 1 Hour timeout). 

Entering an invalid password will logout the user interface.

\subsubsection{NA - Name Analogue Output}
\index{Name Analogue Output}
NA\param{chn}; \param{nameStr}:

Give a name to an analogue output, chn is the channel number from 0 to max analogue outputs-1.

\subsubsection{ND - Name Digital Input}
\index{Name Digital Input}
ND\param{chn}; \param{nameStr}:

Give a name to a digital input, chn is the channel number from 0 to max digital inputs-1.
The name string cannot contain any of the characters '\textless{}\textgreater{}\&

\subsubsection{NI - Name Analogue Input}
\index{Name Analogue Input}
NI\param{chn}; \param{nameStr}:

Give a name to an analogue input, chn is the channel number from 0 to max analogue inputs-1.
The name string cannot contain any of the characters '\textless{}\textgreater{}\&

\subsubsection{NN - Name Node}
\index{Name Node}
\index{NodeName}
NN\param{NodeName}:

Give a name to the WebBrick node.
NodeName is limited to 10 characters  
The name string cannot contain any of the characters '\textless{}\textgreater{}\&

\subsubsection{ND - Name Digital Output}
\index{Name Digital Output}
NO\param{chn}; \param{nameStr}:

Give a name to digital output, chn is the channel number from 0 to max digital outputs-1.
The name string cannot contain any of the characters '\textless{}\textgreater{}\&

\subsubsection{NT - Name Temperature sensor}
\index{Name Temperature sensor}
NT\param{chn}; \param{nameStr}:

Give a name to a temperature input, chn is the channel number from 0 to max temperature inputs-1.
The name string cannot contain any of the characters '\textless{}\textgreater{}\&

\subsubsection{RB - Reboot}
\index{Reboot}
RB  Reboot.

Hardware reboot/reset of the PIC chip and Siteplayer.

\subsubsection{RS - Reboot Siteplayer}
\index{Reboot}
RS  Reboot of Siteplayer.

Hardware reboot/reset of the Siteplayer.

\subsubsection{RT - Re scan 1 Wire}
\index{Re scan 1 Wire}
RT  Re scan 1 wire bus.

Scan the one wire bus for new sensors.

\subsubsection{RU - Refresh User Interface}
\index{Refresh User Interface}
RU  Refresh User Interface.

Resends all data from the PIC chip to the Siteplayer, for use if the PIC chip and Siteplayer are out of step.

\subsubsection{RI - RS485 driver off}
\index{RS485 driver off}
RI:
Set RS485 driver off, input mode

\subsubsection{RO - RS485 driver on}
\index{RS485 driver on}
RO:
Set RS485 driver on, output mode

\subsubsection{RD - Serial send data}
\index{Serial send data}
RD \param{databyte as Decimal ASCII}:
Send serial data, the databyte parameter can be repeated multiple times.

Example, send 'A' character - RD65:  

\subsubsection{SI - Set IP Address}
\index{IP Address}
Set Internet protocol address
SI\param{n}; \param{n}; \param{n}; \param{n}:

Where each \param{n} is an element of the IP address.

SA\param{m}; \param{m}; \param{m}; \param{m}; \param{m}; \param{m}; \param{n}; \param{n}; \param{n}; \param{n}:

Where each \param{m} is an element of the network MAC address.
Where each \param{n} is an element of the IP address.
This is to enable a bunch of WebBricks to be added to a network, identified and addresses set by a discovery process.

\subsubsection{SC - Set Scene}
\index{Set Scene}
SC\param{nr}:

Set the output channels to match a specific scene. The result is the equivalent of issuing On, Off or SetScene 
for any channel not marked as Ignore. NOTE there is a slight difference when a trigger is used to set a scene
in that instead of the ON action for digital channels marked as On and the analogue channels being sent 
the action from the trigger will be sent i.e. Dwell, some possible actions will not make sense.

\subsubsection{SD - Set Date}
\index{Date, Set}
SD\param{years}; \param{mon}; \param{date}  

Set Date for the WebBrick. Not currently implemented or used.
	
\subsubsection{SF - Set FadeRate}
\index{FadeRate, Set}
SF\param{rate}  Set Fade rate

Set the rate at which the analogue channels are adjusted to meet the desired output value. 
The smaller the number the quicker the analogue output channel swings.

With a setting of 1 the analogue will swing full range in approx 200mS, with a value of 255 the swing
full range will take circa 50 seconds.

\subsubsection{SM - Set Mimic}
\index{Mimic, Set}
SM\param{offLevel}; \param{onLevel}; \param{fadeRate}[;\param{0\textbar{}1}]:

Set Mimic high and low level and the fade rate between them. These high and low values are used
when connected as mimics for analogue and digital outputs, by use of an off level that is not quite off 
we have a seek light in the dark. onLevel and offLevel can be between 0 and 63. The fade rate controls the speed that the mimic shifts from one level to
the next, the next level could be selected by the DM command. The final optional parameter sets the mimic 
output to low voltage (approx 4V) or high voltage (approx 10.5V).

\subsubsection{SN - Set NodeNumber}
\index{NodeNumber, Set}
SN\param{NodeNumber}:

Set node number
NodeNumber should be between 1-254, 0 is reserved for 'new' WebBricks that will be configured by
a remote server before they go into production.
\index{NodeNumber}

\subsubsection{SO - Set options flag}
\index{Set options flag}
Set an option flag value, some are bit mapped and others just on/off.
SO\param{num}; \param{value}:

Options control some small bits of a WebBrick's operation.
Most options are not intended for general use and are undocumented.

\begin{tabular}{l|p{12cm}}
Option&Description\\
\hline
1&Manages UDP event transmission.\\
2&Manages Analogue input options.\\
3&Manages Analogue output options.\\
4&Manages Digital input options.\\
5&Manages Digital output options.\\
6&Manages Temperaure sensor options.\\
7&Manages Scene options.\\
\end{tabular}

UDP event transmission option.

\begin{tabular}{l|l|p{12cm}}
Bit&Value&Description\\
\hline
0&1&Enable sending temperature changes.\\
1&2&Enable analogue input changes.\\
2&4&Enable analogue output changes.\\
3&8&Enable Infra red reception UDP packets.\\
4&16&Enable RTC debug UDP packets.\\
5&32&Enable Digital output UDP packets.\\
\end{tabular}

Analogue input options.

\begin{tabular}{l|l|p{12cm}}
Bit&Value&Description\\
\hline
0&1&None.\\
\end{tabular}

Analogue output options.

\begin{tabular}{l|l|p{12cm}}
Bit&Value&Description\\
\hline
1&2&Update DMX channels with analogue output changes.\\
\end{tabular}

Digital input options.

\begin{tabular}{l|l|p{12cm}}
Bit&Value&Description\\
\hline
0&1&None.\\
\end{tabular}

Digital output options.

\begin{tabular}{l|l|p{12cm}}
Bit&Value&Description\\
\hline
0&1&None.\\
\end{tabular}

Temperature sensor options.

\begin{tabular}{l|l|p{12cm}}
Bit&Value&Description\\
\hline
0&1&None.\\
\end{tabular}

Scene options.

\begin{tabular}{l|l|p{12cm}}
Bit&Value&Description\\
\hline
0&1&Scenes setpoints target analogue outputs.\\
1&2&Scenes setpoints target DMX channels.\\
\end{tabular}

Note: scenes can target analogue outputs and/or dmx channels.

\subsubsection{SP - Set password}
\index{Set password}
Set a password.
SP\param{level}; \param{new password}:

level is the password level number 1-3. password is the new password to set. If the same password
is set at multiple levels then login using that password will set itself to the highest of the 
levels using that password string. If Level 1 password is blank the WebBrick will default to being
logged in at level 1 at start and after login timeout. This enables the Home page controls.

\subsubsection{SR - Rotary Encoder Step}
\index{Rotary Encoder Step}
Configure rotary encoder.
SR\param{chn};\param{Steps}:

Steps should be between 2-254, Analogue outputs are set in the raw range 0-1023, where 1023 is 5V, 
Steps controls how far the output is
indexed 'up' or 'down' for each step turn of the rotary encoder. 
The configuration value sets the step for all rotary encoders and chn should be 0. Older webbricks had dedicated pins
for rotary encoders and this only targetted analogue 0, Since 6.4 a rotary encoder may be connected to any even/odd pair of digital 
inputs and target any analogue output or what ever the trigger definition can target.
\index{Rotary Encoder!steps}

\subsubsection{SS - Set Operating Mode}
\index{Operating Mode, Set}
Set operational state
SS\param{ToD}:

ToD is a value between 0-255 that lets the WebBrick know a bit about its operating environment, 
the current recognised values are:

\begin{tabular}{l|p{12cm}}
Value&Description\\
\hline
0&This locks out any commands from the WebBrick holding any outputs at their current state (any Dwell in progress will complete).\\
1&Holiday state, digital inputs ignored.\\
2&This is normal operation.\\
\end{tabular}
\index{ToD}

\subsubsection{ST - Set Time}
\index{Time, Set}
ST\param{dd}; \param{hh}; \param{mm}  Set Time

Set the WebBrick clock. dd is day number from 0-6. hh and mm are the 24 hour time. The WebBrick will
send out starting packets until the clock is set.

\subsubsection{TA - Adjust Analogue Input Threshold}
\index{Adjust Analogue Input Threshold}
TA\param{chn}; \param{L\textbar{}H\textbar{}B}; \param{Threshold};

Configure the active threshold on one of the analogue inputs. This does not update the persistent configuration
only the active configuration.
L or H or B identify whether this is setting a High or Low or Both threshold and Threshold is the analogue threshold
as a value from 0-100\%. The low level hardware is 0-5V but so as to avoid issues when some signal
conditioning is added the input is scaled.

\subsubsection{TT - Adjust Temperature Sensor Threshold}
\index{Adjust Temperature Sensor Threshold}
TT\param{chn}; \param{l\textbar{}H\textbar{}B}; \param{Threshold};

Configure the active threshold on one of the temperature sensors. This does not update the persistent configuration
only the active configuration.
L or H or B identify whether this is setting a High or Low or Both threshold and Threshold is the temperature threshold
as a decimal temperature between -50 and +150 to 1 decimal place degrees Celsius. 
i.e. these are valid 50, 43.3, -43, -54.9. These are not valid 34.95, -43.12.

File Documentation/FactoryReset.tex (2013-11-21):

\subsection{Resetting a WebBrick to factory defaults}
\index{Factory Reset}

To perform a factory reset there is a small switch located internally above one of the 12 pin screw connectors, the top right one.
This resets the webrick to factory default, including the IP address. 
This should be pushed whilst the WebBrick is powered up (A credit card inserted horizontally above the connector should do well). 
Remove mains power to the device whilst doing this.

If you can connect to the webrick and login to it you can also go to Manual commands and enter FR and click Send.

You should see the HeartBeat LED flash very quickly, then after about 5 seconds settle to its normal blink rate.

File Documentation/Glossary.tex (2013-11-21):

\section{Glossary}
\index{Glossary}

\begin{tabular}{l|p{12cm}}
IP address&Internet Protocol Address, a 24 bit address used to identify a computer on the internet/intranet.
Normally displayed as 4 numbers separated by periods.\\
XML&\\
SMS&\\
XHTML&\\
HTML&\\
VOIP&\\

\end{tabular}

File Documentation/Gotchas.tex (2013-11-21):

\section{Gotchas, Futures}
\index{Gotchas}
\index{Futures}

Here we layout all the unimplemented features and current known bugs for versions 6.0 through 6.6 Releases of the firmware

\begin{description}

\item [Web Site] use http://community.webbricksystems.com/ for all WebBrick news.

\item [Split Scene Banks]

	On first power up, buttons that do a 'Next' from scene 8 onwards will actually do a next from scene 0
	until scene 8 is selected.  The simple workaround is to press any 'off' buttons just after WebBrick power up.

    This has been fixed in WebBrick firmware 6.6 onwards. 

\item[Analogue 0utputs Version 6.1 onwards]

From version 6.1 of the WebBrick we have included a diode to protect against reverse polarity at the supply rails. 
This effectively drops the internal 12v supply rail by 0.6V.  This means that for WebBricks that are supplied with 
12.0V or less, the top end of the analogue output drops to about 9.67V.  The simple solution is to ensure that the 
WebBrick are supplied with a little more than 12V.  12.6-18.0V is fine.  Note that 13.6-13.8V power supplies are 
particularly suitable for float charging sealed lead acid batteries.

\item[Configuring Digital Inputs]

In version 6.1 it is possible to configure things like a high threshold for a digital channel. 
This is a meaningless configuration. It does no harm, but conversely does nothing at all.

\item[udp Types]

  From 6.6 onwards there is only one UDP type for Digital Inputs, the 'Remote' and 'Alarm' types have been removed.

\end{description}

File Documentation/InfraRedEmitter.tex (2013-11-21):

\section{Infra Red Emitters}
\index{Infra Red Emitters}

\begin{figure}[H]
\centering
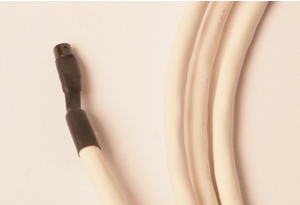
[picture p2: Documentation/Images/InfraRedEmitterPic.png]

\end{figure}

\subsection{WebBricks and Infra Red Emitters}

The webbrick can send RC5 infra red commands, this can be the result of a locally configured trigger or remotely 
on request from the WebBrick Gateway:

	\begin{itemize}
	  
	  \item{Cable:} Cat 5E cable is recommended for Infra Red connections. Webbrick Systems supply
	  		Infra Red Emitters with 2M Cat 5E pre-attached.
	  		
	  \item{Bus Length:}  We recommend a maximum bus length of 20M for an emitter.
	  			
	  \item{Unused cores:} We recommend that unused cores are connected to ground.  In particular the brown core
	  			should be connected to ground.
	  			
	\end{itemize}

\subsection{Connections}

The following connections should be made:

\begin{figure}[H]
\centering
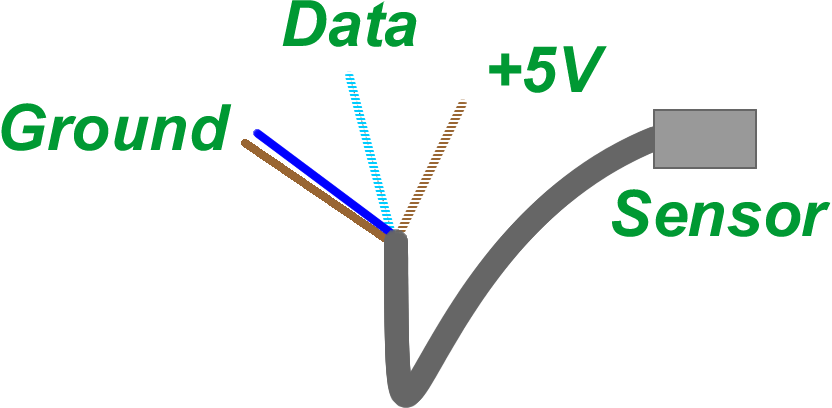
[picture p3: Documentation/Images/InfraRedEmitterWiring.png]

\end{figure}

	\begin{itemize}
	  
	  \item{Brown-White:} Connect to digital output 7, highest digital output.
	  		
	  \item{Brown:} Ground.
	  			
	\end{itemize}

If you wish to connect multiple emitters 2 can be connected in parallel to the single output, any more will require buffering.
    
\subsection{Configuration}

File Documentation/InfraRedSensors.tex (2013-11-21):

\section{Infra Red Sensor}
\index{Infra Red Sensor}

\begin{figure}[H]
\centering

\end{figure}

\subsection{WebBricks and Infra Red Sensors}

The webbrick can receive RC5 infra red signals, these signals can operate the webbrick directly and/or send events that a
WebBrick gateway can respond to. We also supply a simple 8 button remote control that actions sigital inputs 0 to 7. This can be used
for simple local control.

	\begin{itemize}
	  
	  \item{Cable:} Cat 5E cable is recommended for Infra Red sensor connections.  
                    Webbrick Systems supply
	  		Infra Red sensors with 2M Cat 5E pre-attached.
	  		
	  \item{Bus Length:}  We recommend a maximum cable length of 20M ??? for the sensor.
	  			
	  \item{Unused cores:} We recommend that unused cores are connected to ground.  In particular the brown core
	  			should be connected to ground.
	  			
	\end{itemize}

\subsection{Connections}

The following connections should be made:

\begin{figure}[H]
\centering

\end{figure}

	\begin{itemize}
	  
	  \item{Brown-White:} +5V
	  		
	  \item{Blue-White:} Data, this connects to digital input 11, the highest digital input.

	  \item{Blue:} Ground 

	  \item{Brown:} Ground, this core is not connected to the temperature sensor,
	  		grounding this core satisfies the EMC conditions of CE marking.
	  			
	\end{itemize}

Note that multiple Infra Red sensors cannot be connected.

\subsection{Configuration}

Login to the webbrick and access the advanced configuration page. The following page should appear.

\begin{figure}[H]
\centering
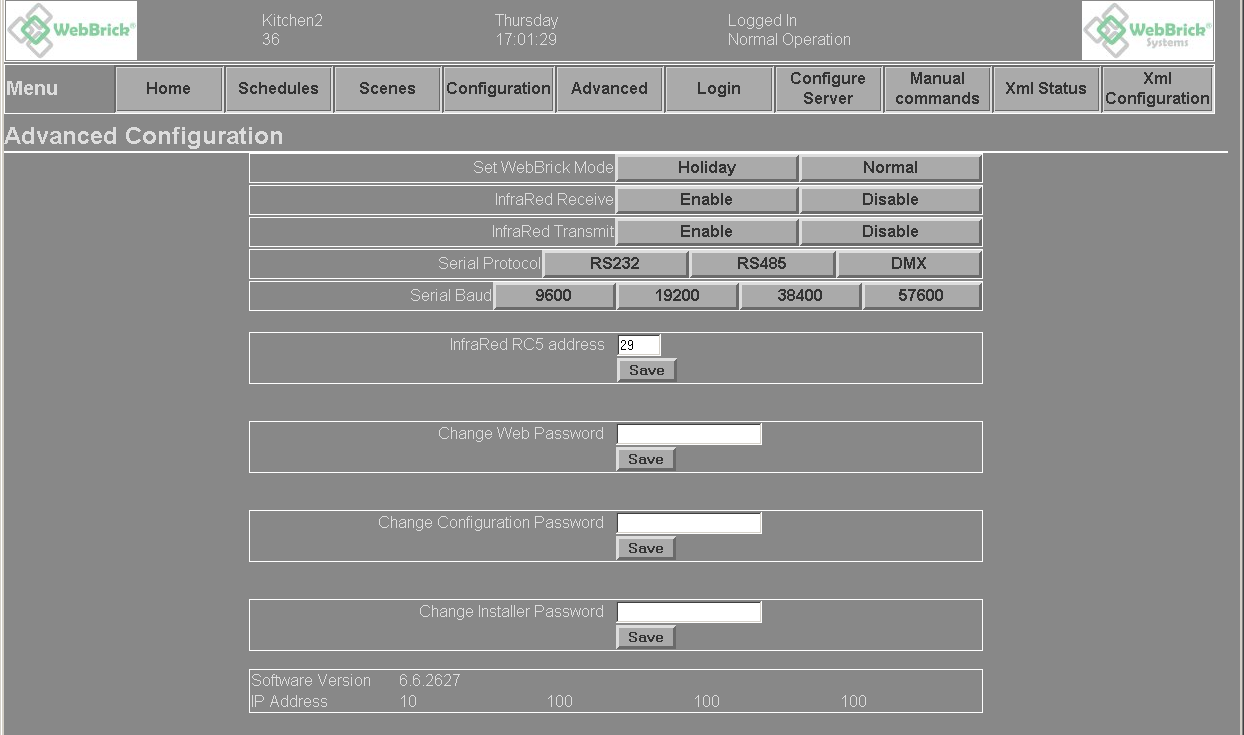
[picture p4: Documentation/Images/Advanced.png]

\end{figure}

Click on the Infra Red Receive Enable button. The webbrick will now map the RC5 commands 0-11 on address 29 to the 12 digital inputs. All other 
received RC5 IR commands are sent to the WebBrick Gateway for possible actions. Look in the WebBrick Gateway EventLog for events received.

If you have a different Infra Red controller that sends using a different address then the InfraRed RC5 address can be changed.

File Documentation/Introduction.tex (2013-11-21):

\section {Was is WebBrick?}

A WebBrick is a process control device with a network interface.  The process control is implemented by state engines that accept
triggers \index{trigger} from a variety of sources and control an output according to the state engine's configuration.

For example, an engine may accept a trigger from trigger input 0 and then hold digital output 7 high for 30 seconds.

This engine could also be triggered from at HTTP request via the embedded web site, or from a UDP packet.

The WebBrick has 8 trigger inputs, 1 analogue input, 1 temperature input, 1 rotary encoder input, 8 digital output and two analogue outputs.

\begin{figure}[H]
\centering

\end{figure}

\subsection{State engines}

\index{State engines}

    The state engines are what give the WebBrick its ability to do local control whilst allowing the interaction of global intelligence.  In essence one a Trigger is invoked it will carry out the actions specified until the actions are complete, or there is an intervention from another Trigger or remote command.
    
    \begin{figure}[H]
    \centering
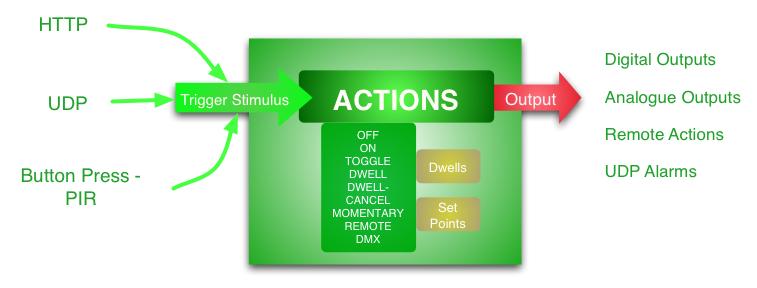
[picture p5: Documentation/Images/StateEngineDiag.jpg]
    
    \end{figure}
    
    More than one Trigger can action an output.  For example there might be conditions that say switch a light on, and some that turn it off.
    
\subsection{Using WebBrick}

    WebBricks can be valuable even in a non-networked environment.  This section shows how the WebBrick can be used:
    \begin{itemize}
    \item as a standalone device
    \item as part of a network with other WebBricks
    \item as part of a network with generic hosts providing some 'global intelligence'
    \end{itemize}
    
    In the following sections, some of the concepts of the WebBrick are introduced.  The full format of specific commands are documented
    later in this manual.

\subsubsection{As a standalone device}

\index{WebBrick as Standalone device}

Consider that you have an ensuite bathroom with dimmable halogen downlights, lights around a mirror, and a heated floor.

In this case the WebBrick would be temporarily connected to a PC to configure the state engines, the configuration might look like this:

\begin{description}
\item[Trigger 0]  This would be set to perform a \textbf {Dwell-Cancel} of 1 hour on the digital output connected to the heated floor.
\item[Trigger 1]  This would be set to perform a \textbf {Toggle} of the digital output connected to the mirror lights
\item[Trigger 2]  This would be set to perform a \textbf {Toggle to-from 25\% } of analogue output 0, which would control the halogen downlights
\item[RotStep]  This would be set to 8 so that a standard 16 indent rotary encoder could set analogue output 0 to 0-100\% in one rotation
\item[Temperature]  This would be set to perform a \textbf {Off} above 35degC ofthe digital output connected to the heated floor
\end{description}

Now the WebBrick can be taken to the location and connected:

\begin{description}
\item[Trigger 0 - Heated Floor]  To a push button with LED within the ensuite
\item[Trigger 1 - Mirror Lights] To a push button with LED within the ensuite
\item[Trigger 2 - Main Lights]  To a push button with LED within the bedroom (within reach of the bed)
\item[Digital Output 0 high] To a solid state relay (SSR) that powers the heated floor
\item[Digital Output 0 low] To the LED for the push button of Trigger 0
\item[Digital Output 1 high] To a SSR that powers the mirror lights
\item[Digital Output 1 low] To the LED for the push button of Trigger 1
\item[Rotary Encode]  To a rotary encoder within the ensuite
\item[Temperature]  To a Dallas 1821 'One Wire' temperature sensor that is bonded to the heated floor at a convienent point
\item[Analogue Output 0] To a 0-10V dimmer that controls the Halogen downlight. Also to the LED of push button within the bedroom
\end{description}

So what does this give the human users?  First they have convienent, safe low voltage controls for switching the lights and the heated floor.
Second from within the bedroom they have a way of switching the ensuite lighting either off from any level or, switching it on to a low level
enough to see by, but not to blind.  By adding a second push button in parallel with Trigger 0 they can both see and switch the state of the
heated floor within the ensuite.

Note that the \textbf{Dwell-Cancel} is used so that should the floor button be pressed, the floor will stay on for 1 hour, unless the button is pressed
again within the hour, in which case the 'dwell' will be cancelled and the heated floor switched off.  This is useful for people that might forget
to switch the floor off, and those that would like to switch the floor off as soon as they are done to save energy.

The configuration of the temperature sensor is used to provide a safety cut-out should the temperature of the heated floor get too high.

\subsubsection{More than one WebBrick on a network}

\index{Multiple WebBricks on a network}

Consider our bedroom and ensuite example from above and add the idea that we have another WebBrick in the kitchen and that the two are networked together.
imagine that the kitchen has a heated floor and that the people might like to control the floor from the bedroom.  They might like to do this so that the
floor is warm before they get to the kitchen.

The kitchen WebBrick would have a similar configuration, with a push button creating a \textbf{Dwell-Cancel} for 1 hour.  It would also use a second trigger
as a \textbf{Dwell} for the same digital output channel.  This second trigger would not be connected to any push button.

Using a push button connected to the ensuite WebBrick say Trigger 3, Trigger 3 would be configured to send a \textbf{remote UDP} command to the \textbf{Dwell}
trigger of the kitchen WebBrick.  Pressing this button would ensure that no matter what the current state of the kitchen heated floor, it would start a dwell of 1 hour.

The dwell created by the remote command can be cancelled with the local push button in the kitchen.

\subsubsection{Using the WebBricks with 'global intelligence'}

Lets take our ensuite/bedroom/kitchen example a little further.  Consider that a computer was available that could support a web server
and the PHP and Python langauges. In practice this means most commonly used systems, from linux on an X-Box to Windows 2003 Server on a PC.

Some sample XML configured web-sites and a series of {\em Public Domain} functions and examples are available in both PHP and Python.  These allow for configuration, operation and monitoring of WebBricks.

The host could use a combination of these functions to find out what was going on at the WebBrick and to send commands to them.

For example, regularly scheduled jobs could be used to switch the heated floor on before the occupants wake up.  Note that for the occupants
this is a convience, and all the physical push button controls still work and can always be used to override the remote commands.

Using simple web browsers, extra interfaces can be created that allow users to control their floors and lights.  By using SMS services from TextAnywhere we can extend the controls to the mobile phones that our users carry about.

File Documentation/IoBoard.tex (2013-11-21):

\section{IO Board}
\index{IO Board}
The V6 webbrick comes with an IO board that provides screw terminal access to all connections other than the 
network cable. It also provides 4 switched mains outputs and 2 double pole changeover relay outputs.

Layout diagram In here.

\subsection{Mains Switching}
\index{Mains Switching}
The mains outputs are digital channels 1 to 4 and can each switch up to 500W, with a maximum of 1500W for the four channels.
There is a 6.3 Amp fuse in the unit that will blow if you excede this loading. These are zero voltage switched and intended 
for simple on off actions. To handle dimming use the analogue outputs connected to external dimmers.

\subsection{Relays}
\index{Relays}
Digital channels 4 and 5 are connected to relays that provide a double pole changeover capability and are rated for 4A at 230V. 

\em{6 Series} Due to internal spacing these should not be used for low voltage applications if the mains switching capability is 
used on the Triacs.

\em{7 Series} The relays are now organised so that relay 5 is a double pole changeover and relay 4 is presented as single pole changeover.  
Internally the connections for relay 4 are paralleled.  This gives a current rating of 4A at 230V for relay 5 and 8A at 230V for relay 4.

The arrangement of the live side protective ground has been changed so that low voltages can be used on the relays whilst mains is present on the triacs. 

\subsection{Connections}
\index{Connections}

The IO board has a total of 6 connectors on it, 2 are 9 way and 4 are 12 way. The 9 way connectors are used for the 
mains outputs and the 12 way for inputs and low voltage outputs.

\begin{figure}[H]
\centering

\caption{WebBrick IO connectors}
\end{figure}

\begin{tabular}{l|p{5cm}}
Connector X1&Relay connections\\
\hline
Pin 1&Mains Triac 0\\
Pin 2&Mains Triac 1\\
Pin 3&Mains Triac 2\\
Pin 4&Mains Triac 3\\
Pin 5&Mains In\\
Pin 6&Relay1 NO1\\
Pin 7&Relay1 C1\\
Pin 8&Relay1 NC1\\
Pin 9&Mains Earth\\
\end{tabular}

\begin{tabular}{l|p{5cm}}
Connector X2&Triac/Mains and more Relay connections\\
\hline
Pin 1&Relay1 NO2\\
Pin 2&Relay1 C2\\
Pin 3&Relay1 NC2\\
Pin 4&Relay2 NO1\\
Pin 5&Relay2 C1\\
Pin 6&Relay2 NC1\\
Pin 7&Relay2 NO2\\
Pin 8&Relay2 C2\\
Pin 9&Relay2 NC2\\
\end{tabular}

\begin{tabular}{l|p{5cm}}
Connector U1&\\
\hline
Pin 1&0V-Digital Ground\\
Pin 2&0V-Digital Ground\\
Pin 3&0V-Digital Ground\\
Pin 4&0V-Digital Ground\\
Pin 5&Digital In 7\\
Pin 6&Digital In 6\\
Pin 7&Digital In 5\\
Pin 8&Digital In 4\\
Pin 9&Digital In 3\\
Pin 10&Digital In 2\\
Pin 11&Digital In 1\\
Pin 12&Digital In 0\\
\end{tabular}

\begin{tabular}{l|p{5cm}}
Connector U2&\\
\hline
Pin 1&Analogue In 0\\
Pin 2&Analogue In 1\\
Pin 3&Analogue In 2\\
Pin 4&Analogue In 3\\
Pin 5&Digital Input 8 - may be labelled Digital Monitor 1\\
Pin 6&Digital Input 9 - may be labelled Digital Monitor 2\\
Pin 7&Digital Input 10 - may be labelled Digital Monitor 3\\
Pin 8&Digital Input 11 - may be labelled Digital Monitor 4\& IR In\\
Pin 9&0V-Digital Ground\\
Pin 10&1 Wire data bus\\
Pin 11&1 Wire 5V Supply\\
Pin 12&0V-Digital Ground\\
\end{tabular}

\begin{tabular}{l|p{5cm}}
Connector U3&\\
\hline
Pin 1&Open Collector Digital 0\\
Pin 2&Open Collector Digital 1\\
Pin 3&Open Collector Digital 2\\
Pin 4&Open Collector Digital 3\\
Pin 5&Special Connection A\\
Pin 6&Special Connection B\\
Pin 7&0V-Digital Ground\\
Pin 8&12V Supply In\\
Pin 9&Digital 4\\
Pin 10&Digital 5\\
Pin 11&Digital 6\\
Pin 12&Digital 7 \& IR Out\\
\end{tabular}

\begin{tabular}{l|p{5cm}}
Connector U4&\\
\hline
Pin 1&Mimic 0\\
Pin 2&Mimic 1\\
Pin 3&Mimic 2\\
Pin 4&Mimic 3\\
Pin 5&Mimic 4\\
Pin 6&Mimic 5\\
Pin 7&Mimic 6\\
Pin 8&Mimic 7\\
Pin 9&Analogue Out 0\\
Pin 10&Analogue Out 1\\
Pin 11&Analogue Out 2\\
Pin 12&Analogue Out 3\\
\end{tabular}

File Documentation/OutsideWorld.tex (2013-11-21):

\section {Interfacing to the outside world}
\index {Interfacing to the outside world}

Here we deal with the basic principles of getting the WebBrick to control and listen to the outside world.

\subsection {Basics}

The WebBrick treats the Digital Inputs as push to make inputs.  There is a software option that can allow
the use on off switches.

To action, the push button should ground the input, pullups are enabled at the PIC chip.  
In out test applications we use CAT5e cable and have runs of up to 100m between the WebBrick 
and the switches, use a twisted pair for each input to reduce noise pickup.  We have seen 
pickup cause problems, in our case we grounded unused cores which cured the issues.

The outputs at Digital Output Low (DOL) are TTL and should be treated as such, they have enough current 
sourcing to drive two LEDs and a Solid State Relay.  In our test applications we drive 
one LED and an SSR simultaneously.

The outputs at Digital Output High (DOH) are open collector capable of sinking 500mA, this means 
the device being switched is connected to a supply rail and the outputs go low on activation to 
switch on the device. Do not use more than 12v as the supply to the device.

The monitor inputs have no pullups are very sensitive, so if not connected to anything or 
connected to a source that does not actively drive high or low tie down to 0V with a 4.7K resistor. 
Valid input range is 0-5V

The analogue outputs are buffered and provide a 0-10V output good enough to drive a pair of LEDs. 
The User interface is
calibrated as 0-100\% so 10\% corresponds to 1V unless some other signal conditioning is inserted.
Do NOT try to drive an LED and an opto isolator at the same time, the forward drop on the LED's will 
be different and the results not much fun (you could use separate resistors to drive each).

\subsection{Cabling}
\index{Cabling}

The webBrick has been designed to use standard CAT 5 networking or structured cabling. CAT 5 cable has consists of 
4 pairs of wires in a single sheath.
These are colour coded with the first colour being the main colour and the later being just narrow stripes:

    \begin{itemize}
			\item Brown with White and White with Brown. 
			\item Green with White and White with Green. 
			\item Orange with White and White with Orange. 
			\item Blue with White and White with Blue. 
    \end{itemize}

To reduce any possible interference the pairs should be used properly with a pair for each 
input or output. Even when multiple inputs are run on the same cable do not use a single ground wire and multiple
input wires, use a ground wire for each input wire. Similarly for outputs.

\subsection{Digital Inputs}

	\subsubsection{Digital Input Characteristics}
	\index{Digital Input Characteristics}
	
		Before looking at the components that can be connected to a WebBrick is useful to look at the timing and voltage characteristics
		of the Digital inputs:
		
		    \begin{figure}[H]
		    \centering
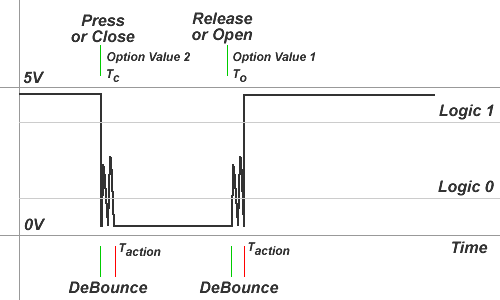
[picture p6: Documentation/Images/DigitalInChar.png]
		    
		    \end{figure}
		    
		The diagram shows an example of a simple pushbutton connected between a Digital Input and WebBrick Ground.
		
		Whilst the button is open, the voltage on the Digital Input will measure near 5V (typically 4.9). When the button
		is pressed this will fall to zero or near zero (anything below 0.6V is considered zero).
		
		Note that in the diagram we have represented some switch bounce. \index{Digital Input DeBounce} The WebBrick has internal
		debouncing of around 20mS.
		
		Because the WebBrick is designed to be used with a range of input devices, it has an option that sets when the state engine
		get triggered:
		
			\begin{description}
				\item[{\bf Rising Edge}] Option is set to 1
				\item[{\bf Falling Edge}] Option is set to 2 - this is the default behaviour
				\item[{\bf Both Edges}] Option is set to 3
			\end{description}
		
		    \begin{figure}[H]
		    \centering
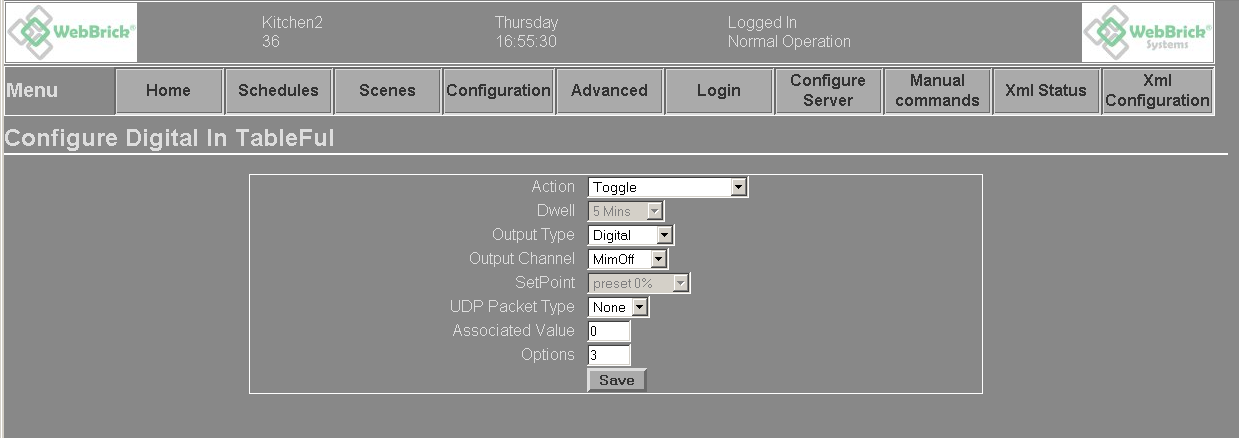
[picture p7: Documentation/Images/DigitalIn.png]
		    
		    \end{figure}

	\subsubsection{Switches}
	For real use, we've found that push buttons with integral LEDs not only look good, but can be very practical.

	A background glow is helpful for locating the button in the dark.

	We either use a 10K resistor to provide a 'background' glow for the 'Off' condition and a 330ohm or 1k resistor 
	from the corresponding digital output to confirm the 'On' condition.

	{\it Note} \index{using 'MK' style switches} It is quite possible to use simple toggle switches with the WebBrick.  However it
	is likely that you'll want to trigger the state engine on both the 'close' and 'open' action.  In this case the option value should
	be set to '3'.  See the section on Digital Input Characteristics for more detail.

	\subsubsection{PIR Passive Infra Red sensors}
	\index{PIR Passive Infra Red sensors}
	These typically have a dry contact that closes for a period of time on detection of movement and can be
	connected to a WebBrick input.

	\subsubsection{Light sensor}
	\index{Light sensor}
	These can also be connected to a digital input unless you have a type that provides a voltage dependant on
	the light level then it should be connected to an analogue input.

	\subsubsection{Security switches}
	\index{Security switches}
	Magnetic reed relays for door and window detection. These are typically used for burglar alarms but can just as easily be
	used to connect to WebBricks.

	\subsection{Digital Outputs}

	\subsubsection{Driving LEDs}
	\index{LEDs ! Driving}

	LEDs are now affordable for just about every kind of use and available in all sorts of colours and power.  
	Therefore its worth a section here describing how they can be used with the WebBrick.

	For simple indication purposes a 300R resistor in series with the TTL level digital outputs will give 
	sufficient current for a standard 3/5mm LED.  There is still sufficient drive to operate solid state 
	relays. \index{SSRs}

	\subsection{Open Collector Outputs}
	\index{Open Collector Outputs}
	
		These can sink up 500mA on a channel with a limit of 800mA across all 8 outputs at any one time.

		We have also found that modern high brightness white LEDs make very good night lighting that can be switched from
		a WebBrick using the Open collector driver.

	\subsubsection{Solid state relays}

	We've been using the Crydom EZ240D5 solid state relays to great effect.  These can be connected directly to 
	the Digital outputs with no other components.

	\subsection{Analogue Inputs}

		These can be used to interface anything that provides a 0-5V output or can be set to produce a 0-5V input. 
		You could also connect an ordinary potentiometer to this input. You should not exceed 5V but higher voltages 
		could be reduced using a two resistor potential divider.

	\subsection{Analogue Outputs}

	\subsubsection{Dimmers}
	\index{Dimmers}

	Any dimmer that accepts a 0-10V control signal can be connected to the analogue outputs.

	We have used the Velleman K8003 kits now replaced by the K8064.

	CPC have some 4 channel dimmers.
	\begin{verbatim}http://cpc.farnell.com/jsp/endecaSearch/partDetail.jsp?SKU=DP26289&N=411\end{verbatim}
	\begin{verbatim}http://cpc.farnell.com/jsp/endecaSearch/partDetail.jsp?SKU=DP27530&N=411\end{verbatim}

	\subsection{Mains Outputs}
	\index{Mains Outputs}

		These are zero voltage switched triacs and can handle loads up to 500W, with a total of 1500W across all 4. 
		They should be able to drive all types of load. Note that there is an internal 6.3A fuse. \index{Internal Fuse}

	\subsection{Relay Outputs}
	\index{Relay Outputs}
	
		These are double pole changeover relays. Particularly useful for curtain motors and other drapery controls. 

	\subsection{Rotary encoder}
	\index{Rotary encoder}

		This is a 3 wire device with a common connection and two signal wires. It is connected to an even/odd pair
of digital inputs with the even trigger definition controlling the action when turned one way and the odd trigger 
defintion the action when turned the other way, i.e. up/down. The target is typically one of the analogue output 
or next/prev scene. It is possible to configure some weird actions like one way is brighter and the other way is off.

	\subsection{Using Temperature Sensors}
	\subsection{Temperature Sensors}

	Here we deal with the basic principles of using the temperature sensors.

	\subsubsection{Hardware}

	The temperature sensors are accessed using the DALLAS one wire interface protocol with the master
	functionality handled by the PIC chip. The Webbrick6 supports up to 5 DS18B20 temperature sensors. 
	These sensors have a 64 bit address that 
	can be used to uniquely identify them and they can read to a resolution below 0.1 degrees C.

	\subsubsection{Software}

	Every second, an attempt is made to read the temperature from one of the sensors and update 
	the status and values. At start up and on command (RT manual command) the bus will be scanned for new devices. 
	When a new sensor is found it is read to see whether it has been tagged previously, if it 
	is untagged or the tag corresponds to a currently active sensor then a new tag number is 
	generated and stored within the sensor. When a web brick is switched on these tags 
	keep the sensors in the same order within the temperature table. The values are all 
	available in the status XML. [NOTE this will change now we have room to store the device
	addresses in the WebBrick]

	When a successful reading is taken it is recorded. Temperature sensor 1 will be tested 
	against the Low and High trigger threshold. If the value is outside these values then 
	the relevant triggers are processed, these are identical to the digital input trigger configuration.

	% COMMENTED OUT
	%\subsection {Practical Application}

	%In the real world, where you measure the temperature and where you action the results are 
	%often not the same place.

	%This is easy to achieve if you have two WebBricks.  You can arrange for one WebBrick to 
	%be near where you need to 
	%measure temperature and the second, say, in a boiler room.

	%The first WebBrick would be configured to trigger a Digital Input channel that was itself configured to generate 
	%a remote command.  This remote command would be directed at the second WebBrick.  The second WebBrick would then 
	%control the boiler.

	%This allows for a network of WebBricks that could all send commands to the 'Boiler WebBrick'.  This would then 
	%give a fine degree of control since each WebBrick could have its 'Context' changed to control behaviour, so 
	%individual zones could be configured by time to suppress requests to the Boiler WebBrick.  For 'vacation' 
	%mode, the Boiler WebBrick could have its 'Context' set to 'Commands Disabled' so that it would turn off 
	%the Boiler and not action any requests from the other WebBricks.

	\subsubsection{Installing}
	So as to get sensors to display in your desired order in the list of temperatures. You should connect them one at a time
	with the first sensor getting tagged to display in 1st row and each subsequent being in subsequent rows.
	After connecting a sensor issue manual command RT and wait for each it to register before adding the next sensor.

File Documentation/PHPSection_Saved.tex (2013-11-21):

\section{WebBrick and PHP}

\subsection{Introduction}

PHP is a web application langauge that allows you to mix business logic and user interface logic in a single file, this file
is processed on a web server to mix fixed and variable parts of the user interface. http://www.php.net

For the WebBrick we provide a number of PHP resources, these fall into the following catergories:

\begin{tabular}{l|p{12cm}}
    \hline
	Libraries&These allow the user to create programs that interact with WebBricks
				using routines that have been fully tested and debugged.  This allows
				the programmer to get on with building the user interface they desire rather
				than getting bogged down in the details of network protocols.\\
    \hline
	Example Code&This allows people to quickly build on some of the ideas we already had and
				implemented.\\
\end{tabular}

\subsection{Libraries}

\subsubsection{wb.php basic comms libray}
\index{wb.php}

This php module provides basic communication with the WebBrick and is mainly intended to be a building block.

To use this library use the following in your code:

\begin{verbatim} include("../API/wb.php") ;\end{verbatim}

From this point you can use this module to interact with WebBricks, for example
if you wanted to switch on a particular output channel you might use
somethine like

wbSendCmd( '10.100.100.100', 'DO3;N' )

\subsubsection{wb6.php the WebBrick 6 library}
\index{wb6.php}

This module provides basic commands that can be sent to a WebBrick.

To import this library use the following in your code:

\begin{verbatim} include("../API/wb6.php") ;\end{verbatim}

From this point you can use this module to interact with WebBricks, for example
if you wanted to switch on a particular output channel you might use
somethine like

wb6DigOn( '10.100.100.100', 3 )

\subsubsection{Functions implemented by wb6}

\begin{tabular}{l|p{12cm}}
    function&Description\\
    \hline
    \hline
    wb6Trigger(\param{adrs}, \param{chn})&Generate a digital trigger on a digital input\\
        \param{adrs}&is the Ip address/Dns Name of the WebBrick being targetted.\\
        \param{chn}&is the channel on the webBrick being targetted\\
        \hline
    wb6DigOn(\param{adrs}, \param{chn})&Set a digital On\\
        \param{adrs}&is the Ip address/Dns Name of the WebBrick being targetted.\\
        \param{chn}&is the channel on the webBrick being targetted\\
        \hline
    wb6DigOff(\param{adrs}, \param{chn})&Set a digital Off\\
        \param{adrs}&is the Ip address/Dns Name of the WebBrick being targetted.\\
        \param{chn}&is the channel on the webBrick being targetted\\
        \hline
    wb6DigToggle(\param{adrs},\param{chn})&Toggle a digital Off\\
        \param{adrs}&is the Ip address/Dns Name of the WebBrick being targetted.\\
        \param{chn}&is the channel on the webBrick being targetted\\
        \hline
    wb6DigDwell(\param{adrs},\param{chn},\param{DwellNr})&Set a digital channel on for Dwell Time\\
        \param{adrs}&is the Ip address/Dns Name of the WebBrick being targetted.\\
        \param{chn}&is the channel on the webBrick being targetted\\
        \param{DwellNr}&is the dwell number\\
        \hline
    wb6SetPoint(\param{adrs},\param{chn},\param{sp})&Set an analogue channel to preset sp.\\
        \param{adrs}&is the Ip address/Dns Name of the WebBrick being targetted.\\
        \param{chn}&is the channel on the webBrick being targetted\\
        \param{sp}&is the preset number\\
        \hline
    wb6AnOutValue(\param{adrs},\param{chn},\param{val})&Set an analogue channel to a specific per-cent level.\\
        \param{adrs}&is the Ip address/Dns Name of the WebBrick being targetted.\\
        \param{chn}&is the channel on the webBrick being targetted\\
        \param{val}&is a value 0-100 where 100 if 10V output\\
        \hline
    getStatusXml(\param{adrs})&Retrive the Xml blob that describes the current status of the addressed WebBrick\\
        \param{adrs}&is the Ip address/Dns Name of the WebBrick being targetted.\\
        \hline
    getConfigXml(\param{adrs})&Retrive the Xml blob that describes the current configuration of the addressed WebBrick\\
        \param{adrs}&is the Ip address/Dns Name of the WebBrick being targetted.\\
        \hline
\end{tabular}

\subsubsection{wb6Status.php}
\index{wb6Status.php}

This class retrieves a copy of the current WebBrick Status that can then be asked for specific details. Note
the object reads and caches the values, so you get a current snapshot. To get updated values use the load method.
There is no point retrieveing tha values at more a 1 second interval and it is recommended that you do as much as possible
with a single retrieved snapshot.

\begin{tabular}{l|p{12cm}}
    call&Description\\
    \hline
    wbStatus()&Construct a wbStatus object.\\
        \hline
    load(\param{adrs})&load a wbStatus object with a status snapshot.\\
        \param{adrs}&is the Ip address/Dns Name of the WebBrick from which the status should be retrieved.\\
        \hline
    getOneWireBus = getOneWireBus(\param{chn})&return current status of the one wire bus.\\
        \param{result}&Bit map showing which temperature sensors are available.\\
        \hline
    tempVal = getTemp(\param{chn})&return current setting of an analogue output channel.\\
        \param{chn}&the temperature sensor number.\\
        \param{result}&temperature.\\
        \hline
    digOutState = digOutState(\param{chn})&return current temperature.\\
        \param{chn}&the analogue output channel number.\\
        \param{result}&0-100 where 100 is an output of 10V\\
        \hline    
    anOutVal = getAnOut(\param{chn})&return current setting of an analogue output channel.\\
        \param{chn}&the analogue output channel number.\\
        \param{result}&0-100 where 100 is an output of 10V\\
        \hline
    anInVal = getAnIn(\param{chn})&return current level of an analogue input channel.\\
        \param{chn}&the analogue input channel number.\\
        \param{result}&0-100 where 100 is an input of 5V\\
        \hline
    digInState = getDigIn(\param{chn})&return current status of a digital input or monitor input (channels 8-11).\\
        \param{chn}&the digital input channel number.\\
        \param{result}&One of True or False for On or Off.\\
        \hline
    digOutState = getDigOut(\param{chn})&return current status of a digital output.\\
        \param{chn}&the digital output channel number.\\
        \param{result}&One of True or False for On or Off.\\
        \hline
    monitorInState = getMonitor(\param{chn})&return current status of a monitor input.\\
        \param{chn}&the monitor channel number.\\
        \param{result}&One of True or False for On or Off.\\
        \hline
    error = getCmdError()&return result of last command to webbrick.\\
        \param{result}&0 was no error.\\
        \hline
    state = getOperationalState()&return operational state of webBrick.\\
        \param{result}&See comnmand section for values.\\
        \hline
    state = getLoginState()&return login level at webBrick.\\
        \param{result}&0-3.\\
        \hline
    date = getWbDate()&return current date at webBrick.\\
        \param{result}&The date as a formatted string, not yet implemented at webbrick.\\
        \hline
    getTime = getTime()&return current time at webBrick.\\
        \param{result}&The time as a formatted string.\\
        \hline
    getDay = getDay()&return current day at webBrick.\\
        \param{result}&The day as a number 0-6 for Sunday through to Saturday.\\
        \hline
\end{tabular}

\subsubsection{wb6Cfg.php}
\index{wb6Cfg.php}
This class retrieves a copy of the current WebBrick configuration that can then be asked for specific details.

\begin{tabular}{l|p{12cm}}
    function&Description\\
    \hline
    wbConfig()&Construct a wbConfig object\\
        \hline
    load(\param{adrs})&load a wbCfg object\\
        \param{adrs}&is the Ip address/Dns Name of the WebBrick from which the configuration should be retrieved.\\
        \hline
    NodeName = getNodeName()&Retrive node name\\
        \param{result}&is the node name.\\
        \hline
    NodeNumber = getNodeNumber()&Retrive node number\\
        \param{result}&is the node number.\\
        \hline
    fadeRate = getFadeRate()&Retrive fade rate\\
        \param{result}&is the fade rate.\\
        \hline
    ipAddress = getIpAddress()&Retrive IP address\\
        \param{result}&is the IP address.\\
        \hline
    macAddress = getMacAddress()&Retrive ethernet MAC address\\
        \param{result}&is the ethernet MAC address.\\
        \hline
    rotaryStep = getRotary( chan )&Retrieve rotary step value\\
        \param{chan}&rotary channel number.\\
        \param{result}&is the step value.\\
        \hline
    dwell = getDwell( idx )&Retrieve dwell value\\
        \param{idx}&dwell number.\\
        \param{result}&dwell in seconds.\\
        \hline
    dwellStr = getDwellStr( idx )&Retrieve dwell value\\
        \param{idx}&dwell number.\\
        \param{result}&dwell as a display string.\\
        \hline
    sp = getSetPoint( idx )&Retrieve set point value\\
        \param{idx}&set point number.\\
        \param{result}&setpoint 0-100\%.\\
        \hline
    nameStr = getDigOutName( chan )&Retrieve name for digital output\\
        \param{chan}&output number.\\
        \param{result}&name string.\\
        \hline
    nameStr = getMonitorName( chan )&Retrieve name for monitor input\\
        \param{chan}&monitor number.\\
        \param{result}&name string.\\
        \hline
    nameStr = getAnalogueOutName( chan )&Retrieve name for analogue output\\
        \param{chan}&analogue number.\\
        \param{result}&name string.\\
        \hline
    array = getDigInTrigger( chan )&Retrieve values for digital trigger\\
        \param{chan}&digital in number.\\
        \param{result}&associative array.\\
        \hline
    array = getTempTriggerLow( chan )&Retrieve values for low temperature trigger\\
        \param{chan}&temperature number.\\
        \param{result}&associative array.\\
        \hline
    array = getTempTriggerHigh( chan )&Retrieve values for high temperature trigger\\
        \param{chan}&temperature number.\\
        \param{result}&associative array.\\
        \hline
    array = getAnalogueTriggerLow( chan )&Retrieve values for low analogue trigger\\
        \param{chan}&analogue in number.\\
        \param{result}&associative array.\\
        \hline
    array = getAnalogueTriggerHigh( chan )&Retrieve values for high analogue trigger\\
        \param{chan}&analogue in number.\\
        \param{result}&associative array.\\
        \hline
    array = getScheduledEvent( chan )&Retrieve values for a scheduled event trigger\\
        \param{chan}&analogue in number.\\
        \param{result}&associative array.\\
        \hline
    array = getScene( chan )&Retrieve values for a scene\\
        \param{chan}&scene number.\\
        \param{result}&associative array.\\
        \hline
\end{tabular}

Trigger results are returned as an asociative array with some of the following parameters in it, refer to commands 
section for details on these values.

\begin{tabular}{l|p{12cm}}
    attribute name&Description\\
    \hline
    Name&channel name\\
    Value&threshold value\\
    Hours&scheduled time\\
    Minutes&scheduled time\\
    Days&scheduled days\\
    actionNr&action type number\\
    action&action type string\\
    dwell&dwell number\\
    UDPRemNr&UDP packet type number\\
    UDPRem&UDP packet type string\\
    RemNode&target remote node.\\
    typeNr&channel type number\\
    type&channel type string\\
    setPoint&setpoint number\\
    pairChn&target channel number\\
\end{tabular}

Scene results are returned as an asociative array with the following parameters in it.

\begin{tabular}{l|p{12cm}}
    attribute name&Description\\
    \hline
    Digital\param{nn}&Ignore|On|Off\\
    Analogue\param{nn}&Ignore|SetPoint\param{mm}\\
\end{tabular}
where \param{nn} is a channel number and \param{mm} is a setpoint number.

\subsection{PHP Examples}

There is a PHP example that you can modify to produce your own central user interface.  

\subsubsection{PanelLib.php}
\index{PanelLib.php}

This provides a library of code for a user interface panel that is capable of displaying details from one or more 
webBricks and issuing commands to them. This uses an Xml file standard.xml to define a user interface that consists 
of a number of columns that contain status information and/or commands.

The xml file has a top level element called status with a single attribute cols that specifies the number of columns on the
display. There are then a set of elements called item. Each item has a Type element and typically a channel number and an
IP address to identify the webbrick and the data to access from it. Each entry may also contain a Trig element that is used to
specify a command to be issued.

item Type may be one of:

\begin{tabular}{l|p{12cm}}
    type&Description\\
    \hline
    Header&generates a text of Cols width.\\
    Temp&displays a temperature.\\
    inAnalogue&displays an analogue input value.\\
    Analogue&displays an analogue output.\\
    Switch&displays a digital output state.\\
    Monitor&displays a monitor state.\\
\end{tabular}

\subsubsection{standard.php}
\index{standard.php}

This is the start page for the standard panel.

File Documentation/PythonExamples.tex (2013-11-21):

\subsection{Python Examples}

There are some Python examples that you can use to generate the UDP packets that WebBricks will respond to.  
Please note that in most cases you will need at least version 2.0 of Python for these programs.  This is 
because earlier versions did not like sending broadcast packets on all platforms. If you are an Apple Mac 
user you'll need OSX and Python 2.2 or 2.3, note that 2.3 is bundled with the Panther release of OSX, and 
very nice it is too.

\begin{description}

\item[DigitalOut.py]
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

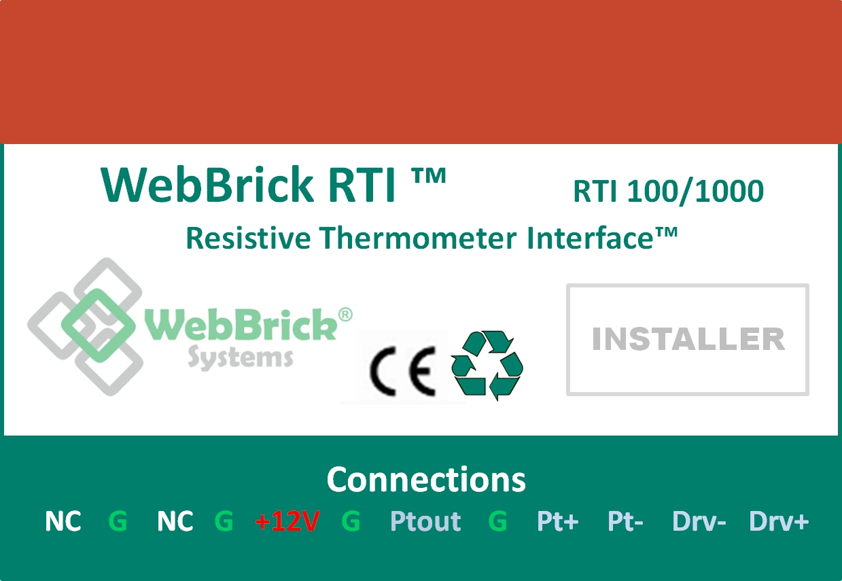
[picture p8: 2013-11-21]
Hardware/RTI/Docs/HSE Label2.jpg

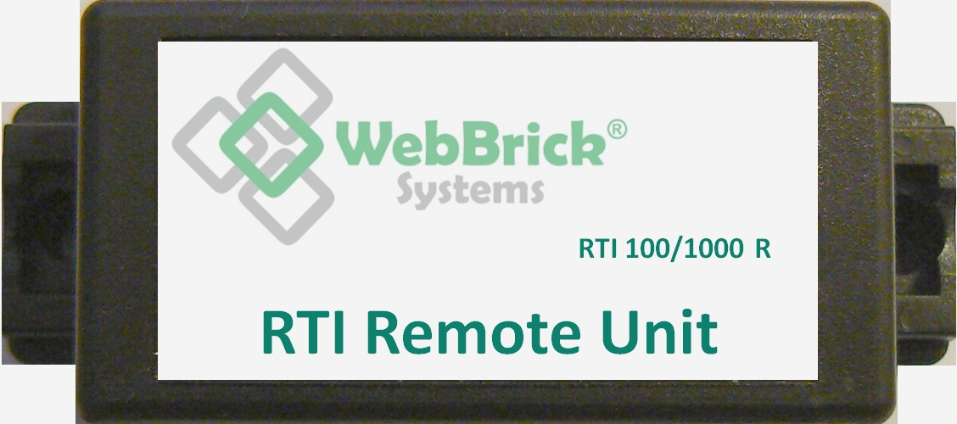
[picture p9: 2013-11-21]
Hardware/RTI/Docs/RULabelPicture.jpg

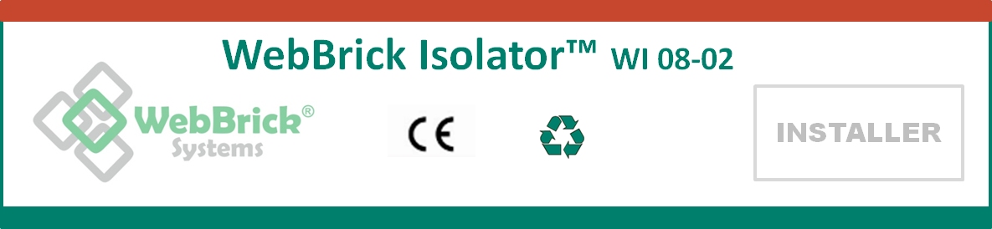
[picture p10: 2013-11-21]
Hardware/Isolator/Docs/Label.jpg

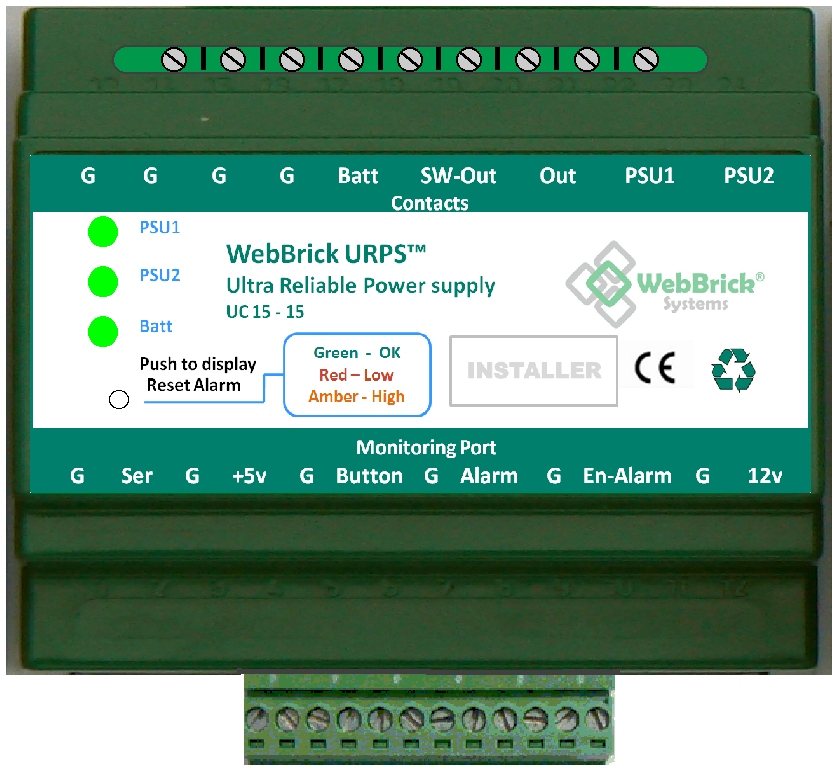
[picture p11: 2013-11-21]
Hardware/HP_Urps/Docs/URPSNewLabel.jpg

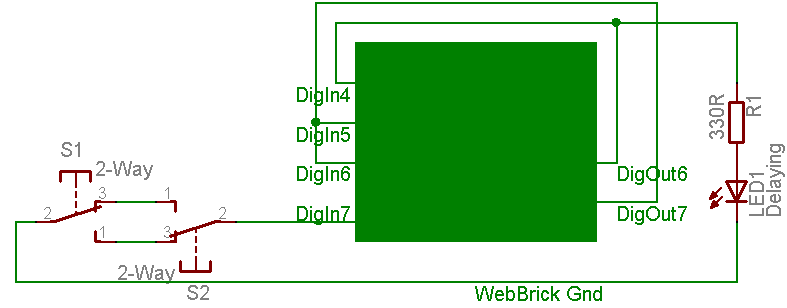
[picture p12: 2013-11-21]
Hardware/Webbrick Interfaces/Example CCT Diagrams/Inputs/ConventionalOn-Off.png

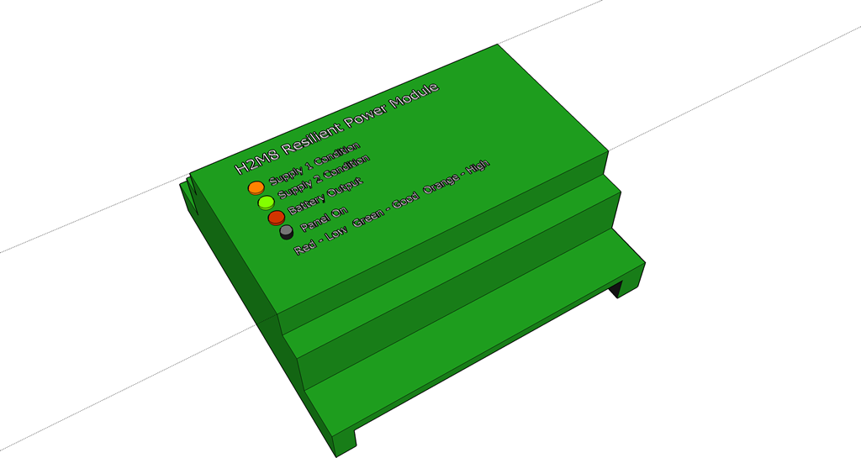
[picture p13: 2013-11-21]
Hardware/PowerSupply/Resilient.png

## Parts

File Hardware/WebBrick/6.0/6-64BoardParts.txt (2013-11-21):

Partlist

Exported from WebBrick6-0-64.sch at 02/05/2007 16:23:42 

EAGLE Version 4.13 Copyright (c) 1988-2004 CadSoft

Part     Value          Device                Package             Library         Sheet

C1       22pF           C-EUC1206             C1206               rcl             1
C2       22pF           C-EUC1206             C1206               rcl             1
C3       10nF           C-EUC1206             C1206               rcl             1
C4       100pF          C-EUC1206             C1206               rcl             1
C5       10nF           C-EUC1206             C1206               rcl             1
C6       100pF          C-EUC1206             C1206               rcl             1
C7       100uf          CPOL-EUF              PANASONIC_F         rcl             1
C8       1uf            CPOL-EUA/3216-18W     A/3216-18W          rcl             1
C9       1uf            CPOL-EUA/3216-18W     A/3216-18W          rcl             1
C10      1uF            CPOL-EUA/3216-18W     A/3216-18W          rcl             1
C11      1uF            CPOL-EUA/3216-18W     A/3216-18W          rcl             1
C12      1F             CP-SUPERCAPHORIZONTAL SUPERCAP-HORIZONTAL cap-master      1
C13      100uf          CPOL-EUF              PANASONIC_F         rcl             1
C14      10nF           C-EUC1206             C1206               rcl             1
C15      10nF           C-EUC1206             C1206               rcl             1
C16      10nF           C-EUC1206             C1206               rcl             1
C17      10nF           C-EUC1206K            C1206K              rcl             1
C18      10nF           C-EUC1206K            C1206K              rcl             1
C19      10nF           C-EUC1206K            C1206K              rcl             1
C20      10nF           C-EUC1206K            C1206K              rcl             1
C21      10uF - Low ESR C-EUC3216             C3216               rcl             1
D1       40V            SCHOTTKY-DIODE        SOD123              diode           1
D2       40V            SCHOTTKY-DIODE        SOD123              diode           1
DC-IN    Leave          PINHD-1X2             1X02                pinhead         1
HB       Blue           LEDSMT1206            1206                led             1
IC1      MC3403D        MC34004D              SO14                linear          1
IC2                     ULN2803ASO18W         SO18W               uln-udn         1
IC3      PFC8563        PFC8563SO8            SO8                 micro-philips   1
IC5      18F6622        PIC18F6720-I/PT       TQFP64-10X10        pic18fxx20-fxx8 1
ICSP     90 Degree Long PINHD-1X6             1X06                pinhead         1
L1       100uH          L-EUL5650M            L5650M              rcl             1
LINK     Green          LEDSMT1206            1206                led             1
PWR      Red            LEDSMT1206            1206                led             1
Q1       10MHz          CRYTALHC49U-V         HC49U-V             crystal         1
Q3       32.768 Khz     CRYTALTC26V           TC26V               crystal         1
R1       1K             R-EU_R1206            R1206               rcl             1
R2       10K            R-EU_M1206            M1206               rcl             1
R3       10K            R-EU_M1206            M1206               rcl             1
R4       10K            R-EU_M1206            M1206               rcl             1
R5       10K            R-EU_M1206            M1206               rcl             1
R6       10K            R-EU_M1206            M1206               rcl             1
R7       10K            R-EU_M1206            M1206               rcl             1
R8       10K            R-EU_M1206            M1206               rcl             1
R9       1K             R-EU_R1206            R1206               rcl             1
R10      10K            R-EU_M1206            M1206               rcl             1
R12      10K            R-EU_M1206            M1206               rcl             1
R13      10K            R-EU_M1206            M1206               rcl             1
R14      10K            R-EU_M1206            M1206               rcl             1
R15      10K            R-EU_M1206            M1206               rcl             1
R16      1K             R-EU_M1206            M1206               rcl             1
R17      10k            R-EU_M1206            M1206               rcl             1
R18      10K            R-EU_M1206            M1206               rcl             1
R19      1K             R-EU_R1206            R1206               rcl             1
R20      4K7            R-EU_R1206            R1206               rcl             1
R21      4K7            R-EU_R1206            R1206               rcl             1
R22      1K             R-EU_R1206            R1206               rcl             1
S1                      31-XX                 B3F-31XX            switch-omron    1
SR2      USART2-Leave   PINHD-1X2             1X02                pinhead         1
SV1      2x20 Long Pin  MA20-2                MA20-2              con-lstb        1
SV2      2x20 Long Pin  MA20-2                MA20-2              con-lstb        1
U$1      2off 1x9 PH    SP                    SITEPLAYER          siteplayer      1
U$2      PCA EPJ9372    PULSETRANSFORMER      PULSETRANSFORMER    PulseTrans      1
U$3      LM2674-5       LM2674-5              SO08                LM2674          1

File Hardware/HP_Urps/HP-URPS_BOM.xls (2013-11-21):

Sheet: HiPowerURPS c
Bill of Materials
High Power URPS
2008-08-05
 |  |  |  |  |  |  |  |  |  |  |  |  |  |  |  | Import | Import
Reference | Quant | Type | Package | Manufacturer | Mfr. Part No | Value | Supplier | Supplier No. | Data | Sourced By | Comments | Catalogue | Extended | Catalogue | Extended | Catalogue | Extended
 |  |  |  |  |  |  |  |  |  |  |  | Price Lo Q | price Lo Q | Price 10 off | price 10 off
C1 | 1 | Tant | Case A 10V | AVX | TPSA106K010R1800 | 10u | Farnell | 1135105 (http://uk.farnell.com/jsp/Passive+Components/Capacitors/AVX/TPSA106K010R1800/displayProduct.jsp?sku=1135105) |  |  |  | 0.200 | 0.20 | 0.182 | 0.18 |  | 0.00
C2, C3, C4, C6, C7, C8, C15, C16, C17, C18, C19 | 11 | MLC | 0603 | Kemet | C0603C104K5RAC | 0.1u | Farnell | 1288255 (http://uk.farnell.com/jsp/Passive+Components/Capacitors/KEMET/C0603C104K5RAC/displayProduct.jsp?sku=1288255) |  |  |  | 0.013 | 0.14 | 0.013 | 0.14 |  | 0.00
C5 | 1 | Tant | Case D 35V | AVX | TPSD476K016R0080 | 47uF | Farnell | 1135205 (http://uk.farnell.com/jsp/Passive+Components/Capacitors/AVX/TPSD476K016R0080/displayProduct.jsp?sku=1135205) |  |  |  | 0.740 | 0.74 | 0.680 | 0.68 |  | 0.00
C9, C10, C11, C12, C13, C14, | 6 | MLC | 0805 |  |  | 0.1u
R1 | 1 | Wire Wound | 6W | Welwyn | RWM 6X22 18R 5% AM250 E1 | 18R | Farnell | 1109311 (http://uk.farnell.com/jsp/Passive+Components/Resistors,+Thermistors+&+Potentiometers/VISHAY+SFERNICE/RWM+6X22+18R+5++AM250+E1/displayProduct.jsp?sku=1109311) |  |  |  | 0.540 | 0.54 | 0.540 | 0.54 |  | 0.00
R2, R3, R4, R5 | 4 | 0.10% | 0603 | Welwyn | PCF0603R 24K3BI.T1 | 24.3k | Farnell | 1160377 (http://uk.farnell.com/jsp/Passive+Components/Resistors,+Thermistors+&+Potentiometers/WELWYN/PCF0603R+24K3BI.T1/displayProduct.jsp?sku=1160377) |  |  |  | 0.430 | 1.72 | 0.340 | 1.36 |  | 0.00
R6 | 1 | 1% | 0603 | Multicomp | MC 0.063W 0603 1% 22K | 22k | Farnell | 9330828 (http://uk.farnell.com/jsp/Passive+Components/Resistors,+Thermistors+&+Potentiometers/MULTICOMP/MC+0.063W+0603+1++22K/displayProduct.jsp?sku=9330828) |  |  |  | 0.021 | 0.02 | 0.021 | 0.02 |  | 0.00
R7, R8, R9, R10, R16, R17, R33 | 7 | 1% | 0603 | Multicomp | MC 0.063W 0603 1% 330R | 330R | Farnell | 9331018 (http://uk.farnell.com/jsp/Passive+Components/Resistors,+Thermistors+&+Potentiometers/MULTICOMP/MC+0.063W+0603+1++330R/displayProduct.jsp?sku=9331018) |  |  |  | 0.021 | 0.15 | 0.021 | 0.15 |  | 0.00
R11, R14, R15, R24 | 4 | 0.10% | 0603 | Welwyn | PCF0603R-4K87BT1 | 4k87 | Farnell | 1353176 (http://uk.farnell.com/jsp/Passive+Components/Resistors,+Thermistors+&+Potentiometers/WELWYN/PCF0603R-4K87BT1/displayProduct.jsp?sku=1353176) |  |  |  | 0.430 | 1.72 | 0.340 | 1.36 |  | 0.00
R12, R22, R29. R32, R41 | 5 | 1% | 0603 | Multocomp | MC 0.063W 0603 1% 47K | 47k | Farnell | 9331255 (http://uk.farnell.com/jsp/Passive+Components/Resistors,+Thermistors+&+Potentiometers/MULTICOMP/MC+0.063W+0603+1++47K/displayProduct.jsp?sku=9331255) |  |  |  | 0.045 | 0.22 | 0.034 | 0.17 |  | 0.00
R13 | 1 | 1% | 1206 | Phycomp | 232272466808 | 6.8R | Farnell | 9236627 (http://uk.farnell.com/jsp/Passive+Components/Resistors,+Thermistors+&+Potentiometers/PHYCOMP/232272466808/displayProduct.jsp?sku=9236627) |  |  |  | 0.023 | 0.02 | 0.023 | 0.02 |  | 0.00
R18, R20, R23, | 3 | 1% | 0603 | Multicomp | MC 0.063W 0603 1% 390R | 390R | Farnell | 9331131 (http://uk.farnell.com/jsp/Passive+Components/Resistors,+Thermistors+&+Potentiometers/MULTICOMP/MC+0.063W+0603+1++390R/displayProduct.jsp?sku=9331131) |  |  |  | 0.021 | 0.06 | 0.021 | 0.06 |  | 0.00
R19, R21 | 2 | 1% | 0603 | Phycomp[ | 232270464702 | 4k7 | Farnell | 9238565 (http://uk.farnell.com/jsp/Passive+Components/Resistors,+Thermistors+&+Potentiometers/PHYCOMP/232270464702/displayProduct.jsp?sku=9238565) |  |  |  |  |  |  |  |  | 0.00
R30, R31 | 2 | 1% | 0603 | Muticomp | MC 0.063W 0603 1% 10K | 10k | Farnell | 9330399 (http://uk.farnell.com/jsp/Passive+Components/Resistors,+Thermistors+&+Potentiometers/MULTICOMP/MC+0.063W+0603+1++10K/displayProduct.jsp?sku=9330399) |  |  |  | 0.021 | 0.04 | 0.021 | 0.04 |  | 0.00
R43 | 1 | 1% | 0603 | Multicomp | MC 0.063W 0603 1% 100K | 100k | Farnell | 9330402 (http://uk.farnell.com/jsp/Passive+Components/Resistors,+Thermistors+&+Potentiometers/MULTICOMP/MC+0.063W+0603+1++100K/displayProduct.jsp?sku=9330402) |  |  |  | 0.021 | 0.02 | 0.021 | 0.02 |  | 0.00
IC1 | 1 | Microcontroller | SOIC 20W | Microchip | PIC16F690-I/SO |  | Farnell | 1292261 (http://uk.farnell.com/jsp/Semiconductors/Microprocessors+/+Microcontrollers+&+peripherals/MICROCHIP/PIC16F690-I/SO/displayProduct.jsp?sku=1292261) |  |  |  | 1.310 | 1.31 | 0.990 | 0.99 |  | 0.00
IC2 | 1 | Vreg | SOT223 | TI | UA78M05CDCYG3 | 5V | Farnell | 1236598 (http://uk.farnell.com/jsp/Semiconductors/power+control/TEXAS+INSTRUMENTS/UA78M05CDCYG3/displayProduct.jsp?sku=1236598) |  |  |  | 0.280 | 0.28 | 0.185 | 0.18 |  | 0.00
IC3 | 1 | RS232 | SOIC16N | TI | MAX3232CD |  | Farnell | 1470457 (http://uk.farnell.com/jsp/Semiconductors/Drivers+&+Receivers/TEXAS+INSTRUMENTS/MAX3232CD/displayProduct.jsp?sku=1470457) |  |  |  | 0.830 | 0.83 | 0.660 | 0.66 | 0.660 | 0.66
Bz1 | 1 | Buzzer | Unbranded | Projects Ulimited | ABI-009-RC | 4-8V | Farnell | 1022397 (http://uk.farnell.com/jsp/Electrical/Transducers/UNBRANDED/ABI-009-RC/displayProduct.jsp?sku=1022397) |  |  |  | 1.120 | 1.120 | 0.910 | 0.910 | 0.910 | 0.91
D1 | 1 | V Ref | SOT23 | TI | LM4040C25IDBZTG4 | 2.5V | Farnell | 1053839 (http://uk.farnell.com/jsp/Semiconductors/Diodes/TEXAS+INSTRUMENTS/LM4040C25IDBZTG4/displayProduct.jsp?sku=1053839) | Data (http://www.datasheets.org.uk/search.php?q=lm4040) |  |  | 0.320 | 0.32 | 0.220 | 0.22 | 0.220 | 0.22
D2, D3 | 2 | Diode | Dpak | Vishay | 12CWQ03FNTRPBF |  | Farnell | 1298441 (http://uk.farnell.com/jsp/Semiconductors/Diodes/VISHAY-FORMERLY+INTERNATIONAL+RECTIFIER/12CWQ03FNTRPBF/displayProduct.jsp?sku=1298441) |  |  |  | 1.580 | 3.16 | 1.580 | 3.16 | 1.580 | 3.16
D4, D5 | 2 | Schottky | DO220 | Vishay | 20L15TPBF | 20A | Farnell | 8647852 (http://uk.farnell.com/jsp/Semiconductors/Diodes/VISHAY-FORMERLY+INTERNATIONAL+RECTIFIER/20L15TPBF/displayProduct.jsp?sku=8647852) |  |  |  | 3.300 | 6.60 | 2.010 | 4.02 | 2.010 | 4.02
Reg1 | 1 | Module | IL Series DIL |  | IE0512D | 12V | Farnell | 8727708 (http://uk.farnell.com/jsp/Electrical/Power+Supplies+&+Converters/XP+POWER/IE0512D/displayProduct.jsp?sku=8727708) |  |  |  | 3.030 | 3.03 | 2.850 | 2.85 | 2.850 | 2.85
FS1, FS2 | 1 | Fuse Holder | FK1 | Pudenz | 178.6764.0001. |  | Farnell | 310487 (http://uk.farnell.com/jsp/Electrical/Fuse+Holders+&+Accessories/PUDENZ/178.6764.0001./displayProduct.jsp?sku=310487) |  |  |  | 0.540 | 0.540 | 0.510 | 0.51 | 0.510 | 0.51
FS1B | 1 | Fuse | FK1 | Littlefuse | 0297030.WXN | 30A | Farnell | 9943900 (http://uk.farnell.com/jsp/Electrical/Fuses+&+Circuit+Breakers/LITTELFUSE/0297030.WXN/displayProduct.jsp?sku=9943900) |  |  | Not fitted During assembly | 0.410 | 0.410 | 0.270 | 0.27 | 0.270 | 0.27
FS2B | 1 | Fuse | FK1 | Pudenz | 168.6785.5157. | 15A | Farnell | 308341 (http://uk.farnell.com/jsp/Electrical/Fuses+&+Circuit+Breakers/PUDENZ/168.6785.5157./displayProduct.jsp?sku=308341) |  |  | Not fitted During assembly | 0.410 | 0.410 | 0.270 | 0.27 | 0.270 | 0.27
 |  |  |  |  |  |  | Farnell
T1, T2, T4 | 3 | MOSFET | TO220 | Fairchild | FDP8860 |  | Farnell | 1324804 (http://uk.farnell.com/jsp/Semiconductors/Transistors/FAIRCHILD+SEMICONDUCTOR/FDP8860/displayProduct.jsp?sku=1324804) |  |  |  | 2.210 | 6.63 | 1.630 | 4.89 | 1.630 | 4.89
T3, T10 | 2 | MOSFET | SOT223 | Fairchild | NDT2955 | 2.5A | Farnell | 9846271 (http://uk.farnell.com/jsp/Semiconductors/Transistors/FAIRCHILD+SEMICONDUCTOR/NDT2955/displayProduct.jsp?sku=9846271) |  |  |  | 0.450 | 0.90 | 0.450 | 0.90 | 0.450 | 0.90
T6 | 1 | MOSFET | SOT23 | Vishay | 2N7002 |  | Farnell | 1021754 (http://uk.farnell.com/jsp/Semiconductors/Transistors/VISHAY+SILICONIX/2N7002/displayProduct.jsp?sku=1021754) |  |  |  | 0.087 | 0.09 | 0.610 | 0.61 | 0.610 | 0.61
T9 | 1 | PNP | SOT23 | Philips | BC857 |  | Farnell | 1081244 (http://uk.farnell.com/jsp/Semiconductors/Transistors/PHILIPS/BC857/displayProduct.jsp?sku=1081244) | Data (http://www.datasheetarchive.com/pdf/832298.pdf) |  |  | 0.030 | 0.03 | 0.030 | 0.03 | 0.030 | 0.03
TH1 | 1 | Thermostat | DO220 | Airpax | 67L070 | 70°C | Farnell | 1524711 (http://uk.farnell.com/jsp/Industrial+Controls+&+Automation/Thermal+Sensing+&+Thermostats/AIRPAX/67L070/displayProduct.jsp?sku=1524711) |  |  |  | 4.240 | 4.24 | 4.240 | 4.24 | 4.240 | 4.24
Conn1 | 1 | Connector |  | Camden | CTB93HD/12 | 12 Pin | Camden |  | Data |  |  | 0.430 | 0.43 | 0.430 | 0.43 | 0.430 | 0.43
Conn2A, Conn2B, Conn2C | 3 | Connector | 3Way screw | Camden | CTB0118/3 | 3 Pin | Farnell | 3882603 (http://uk.farnell.com/jsp/Connectors/Multipole/CAMDEN+ELECTRONICS/CTB0118/3/displayProduct.jsp?sku=3882603) |  |  |  | 0.430 | 1.29 | 0.430 | 1.29 | 0.430 | 1.29
Conn3 | 1 | Connector | 8way Socket | FCI | 76341-308LF | 8Way | Farnell | 1098038 (http://uk.farnell.com/jsp/Connectors/PCB/FCI/76341-308LF/displayProduct.jsp?sku=1098038) |  |  |  | 0.890 | 0.89 | 0.890 | 0.89 | 0.890 | 0.89
Conn4 | 1 | Connector | 6way header | Harwin | M20-9990645 | 6Way | Farnell | 1022254 (http://uk.farnell.com/jsp/Connectors/Multipole/HARWIN/M20-9990645/displayProduct.jsp?sku=1022254) |  |  |  | 0.280 | 0.28 | 0.280 | 0.28 | 0.280 | 0.28
OC1, OC2, OC3, | 3 | OptoCoupler | SO4 | Avago | HCPL-181-00BE |  | Farnell | 1244527 (http://uk.farnell.com/jsp/Optoelectronics/Optocouplers/AVAGO+TECHNOLOGIES/HCPL-181-00BE/displayProduct.jsp?sku=1244527) |  |  |  | 0.270 | 0.81 | 0.270 | 0.81 | 0.270 | 0.81
HS1 | 1 | Heatsink | 50mm | ABL | PPC50P | 5°C/W | ABL | PPC50P (http://www.heatsinksonline.co.uk/Products/BoardMounting/page14.htm) |  |  |  | 2.000 | 2.00 | 2.000 | 2.00 | 2.000 | 2.00
PCB | 1 | Double sided |  |  |  |  | PCB Train |  |  |  | 2Oz Copper | 45.000 | 45.00 | 16.000 | 16.00 | 16.000 | 16.00
 |  |  |  |  |  |  |  |  |  |  |  |  | 86.20 |  | 51.17 |  | 45.24

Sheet: Display
Bill of Materials
H2M8
Display Board
Part | Quantity | Type | Package | Manufacturer | Manufacturer Part No | Value | Supplier | Supplier No | Data | Sourced By | Comments | Catalogue | Extended | Newbury | Digikey
Ref. |  |  |  |  |  |  |  |  |  |  |  | Price | price | Electronics
D1, D2, D3 | 3 | Bi colour LED | 5mm | Avago | HLMP-4000 | Red/Green | Farnell | 1003244 (http://uk.farnell.com/jsp/Optoelectronics/LEDs/AVAGO+TECHNOLOGIES/HLMP-4000/displayProduct.jsp?sku=1003244) |  |  |  | 0.23 | 0.69
Sw1 | 1 | Switch | 6mm | Tyco | 9-1437565-3 |  | Farnell | 3801275 (http://uk.farnell.com/jsp/Electrical/Switches+&+Accessories/TYCO+ELECTRONICS/9-1437565-3/displayProduct.jsp?sku=3801275) |  |  |  | 0.08 | 0.08
Conn1 | 1 | 90° pin-H | 0.1" | Tyco | 826947-8 |  | Farnell | 1248174 (http://uk.farnell.com/jsp/Connectors/Multipole/TYCO+ELECTRONICS/826947-8/displayProduct.jsp?sku=1248174) |  |  |  | 0.25 | 0.25
PCB | 1 |  |  | PCB Train |  |  |  |  |  |  |  | 4.44 | 4.44
 |  |  |  |  |  |  |  |  |  |  | Total |  | 5.46

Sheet: Assembly
Quantity | Type | Package | Manufacturer | Manufacturer Part No |  | Supplier | Supplier No | Data |  |  | Extended
 |  |  |  |  |  |  |  |  |  | Price ea. | price
1 | Assembly | Controller |  |  |  |  |  |  |  | 51.19 | 51.19
1 | Assembly | Display |  |  |  |  |  |  |  | 5.46 | 5.46
1 | Case |  | OKW | B6503115 |  |  |  |  |  | 7.00 | 7.00
 |  |  |  |  |  |  |  |  | URPS Controller Total Parts Cost |  | 63.65
Full Assembly
0.5 | Din Rail | 500mm |  |  |  | Farnell | 103727 |  |  | 2.24 | 1.12
Power Supplies
2 |  |  |  | QS10.121 | Option | Pulse 15A |  |  |  | 133.88 | 267.76 | 332.53 | 15A Option
2 |  |  |  | P30-15 | Option | Watt Power |  |  |  | 28.13 | 56.26 | 121.03 | 1.75A Option
Not including assembly. Assembly to be done in house on first batches

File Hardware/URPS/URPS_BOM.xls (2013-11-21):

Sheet: Main
Bill of Materials
H2M8
Ultra Reliable Power Supply - Controller
07/0707
Part | Quantity | Type | Package | Manufacturer | Manufacturer Part No | Value | Supplier | Supplier No | Data | Sourced By | Comments | Catalogue | Extended | Catalogue | Extended | Newbury | Digikey
Ref. |  |  |  |  |  |  |  |  |  |  |  | Price Lo Q | price Lo Q | Price 10 off | price 10 off | Electronics
Bz1 | 1 | Buzzer | 13.8mm | Projects Ulimited | AI-175. | 3-16V | Farnell | 5002989 (http://uk.farnell.com/jsp/Electrical/Transducers/PROJECTS+UNLIMITED/AI-175./displayProduct.jsp?sku=5002989) |  |  |  | 1.020 | 1.020 | 0.410 | 0.410
C1 | 1 | Tantalum | Case A | AVX | TPSA106K010R1800 | 10uF | Farnell | 1135105 (http://uk.farnell.com/jsp/Passive+Components/Capacitors/AVX/TPSA106K010R1800/displayProduct.jsp?sku=1135105) |  |  |  | 0.200 | 0.200 | 0.182 | 0.182
C2, C3, C4, C5, C6, C7 | 6 | Ceramic Capacitor | 0805 | AVX | U0805R104KCT | 0.1uF | Farnell | 9406387 (http://uk.farnell.com/jsp/Passive+Components/Capacitors/MULTICOMP/U0805R104KCT/displayProduct.jsp?sku=9406387) |  |  |  | 0.045 | 0.270 | 0.045 | 0.270
D1 | 1 | V Ref | SOT23 | TI | LM4040C25IDBZTG4 | 2.5V | Farnell | 1053839 (http://uk.farnell.com/jsp/Semiconductors/Diodes/TEXAS+INSTRUMENTS/LM4040C25IDBZTG4/displayProduct.jsp?sku=1053839) | Data (http://www.datasheetarchive.com/search.php?q=LM4040&sType=part&ExactDS=Starts) |  |  | 0.300 | 0.300 | 0.210 | 0.210
D2, D3 | 2 | Diode | DO-201AD | On | 1N5401RL | 3A | Farnell | 9556125 (http://uk.farnell.com/jsp/Semiconductors/Diodes/ON+SEMICONDUCTOR/1N5401RL/displayProduct.jsp?sku=9556125) |  |  |  | 0.111 | 0.222 | 0.064 | 0.128
D4 | 1 | Diode | SOT23 | On | BAS16TT1G |  | Farnell | 1150367 (http://uk.farnell.com/jsp/Semiconductors/Diodes/ON+SEMICONDUCTOR/BAS16TT1G/displayProduct.jsp?sku=1150367) |  |  |  | 0.020 | 0.020 | 0.020 | 0.020
D5 | 1 | Diode | Dpak | Vishay | 12CWQ03FNTRPBF |  | Farnell | 1298441 (http://uk.farnell.com/jsp/Semiconductors/Diodes/VISHAY-FORMERLY+INTERNATIONAL+RECTIFIER/12CWQ03FNTRPBF/displayProduct.jsp?sku=1298441) | Data (http://www.datasheetarchive.com/search.php?q=12CWQ03&sType=part&ExactDS=Starts) |  |  | 1.580 | 1.580 | 1.580 | 1.580
IC1 | 1 | Microcontroller | SOIC 20W | Microchip | PIC16F687-I/SS |  | Farnell | 1103402 (http://uk.farnell.com/jsp/Semiconductors/Microprocessors+/+Microcontrollers+&+peripherals/MICROCHIP/PIC16F687-I/SS/displayProduct.jsp?sku=1103402) |  |  |  | 1.310 | 1.310 | 0.990 | 0.990
IC2 | 1 | V Reg | SOT223 | TI | UA78M05CDCYG3 | 5V | Farnell | 1236598 (http://uk.farnell.com/jsp/Semiconductors/power+control/TEXAS+INSTRUMENTS/UA78M05CDCYG3/displayProduct.jsp?sku=1236598) |  |  |  | 0.270 | 0.270 | 0.176 | 0.176
T1, T4 | 2 | MOSFET | DPAK | IR | SUD50P04-15 | 15mOhm | Farnell | 9551549 (http://uk.farnell.com/jsp/Semiconductors/Transistors/VISHAY+SILICONIX/SUD50P04-15/displayProduct.jsp?sku=9551549) | Data (http://www.datasheetarchive.com/search.php?q=SUD50P04-15&sType=part&ExactDS=Starts) |  |  | 1.460 | 2.920 | 0.880 | 1.760
T2, T5, T6 | 3 | MOSFET | SOT23 | Vishay | 2N7002 |  | Farnell | 1021754 (http://uk.farnell.com/jsp/Semiconductors/Transistors/VISHAY+SILICONIX/2N7002/displayProduct.jsp?sku=1021754) |  |  |  | 0.087 | 0.261 | 0.610 | 1.830
T3 | 1 | MOSFET | SOT223 | Fairchild | NDT2955 | 2.5A | Farnell | 9846271 (http://uk.farnell.com/jsp/Semiconductors/Transistors/FAIRCHILD+SEMICONDUCTOR/NDT2955/displayProduct.jsp?sku=9846271) |  |  |  | 0.450 | 0.450 | 0.450 | 0.450
R1 | 1 | Resistor | Axial | Multicomp | MF50 47R | 47R | Farnell | 9340653 (http://uk.farnell.com/jsp/Passive+Components/Resistors,+Thermistors+&+Potentiometers/MULTICOMP/MF50+47R/displayProduct.jsp?sku=9340653) |  |  |  | 0.023 | 0.023 | 0.023 | 0.023
R2, R3, R4, R5 | 4 | Resistor | 0805 | Welwyn | PCF0603R-20KBI. | 20k | Farnell | 1160374 (http://uk.farnell.com/jsp/Passive+Components/Resistors,+Thermistors+&+Potentiometers/WELWYN/PCF0603R+20KBI.T1/displayProduct.jsp?sku=1160374) |  |  |  | 0.440 | 1.760 | 0.340 | 1.360
R6 | 1 | Resistor | 0805 | Phycomp | 232270260223 | 22k | Farnell | 9233547 (http://uk.farnell.com/jsp/Passive+Components/Resistors,+Thermistors+&+Potentiometers/PHYCOMP/232270260223/displayProduct.jsp?sku=9233547) |  |  |  | 0.048 | 0.048 | 0.048 | 0.048
R7, R8, R9, R10, R16, R17, | 6 | Resistor | 0805 | Phycomp | 232270260331 | 330R | Farnell | 9233318 (http://uk.farnell.com/jsp/Passive+Components/Resistors,+Thermistors+&+Potentiometers/PHYCOMP/232270260331/displayProduct.jsp?sku=9233318) |  |  |  | 0.048 | 0.288 | 0.048 | 0.288
R11, R14, R15, R24 | 4 | Resistor | 0805 | Welwyn |  | 10k | Farnell | 1160203 (http://uk.farnell.com/jsp/Passive+Components/Resistors,+Thermistors+&+Potentiometers/WELWYN/PCF0805R+10KBI.T1/displayProduct.jsp?sku=1160203) |  |  |  | 0.450 | 1.800 | 0.450 | 1.800
R12, R13, R18, R20, R21 ,R22 R23, R29, R32 | 9 | Resistor | 0805 | Phycomp | 232270260473 | 47k | Farnell | 9233580 (http://uk.farnell.com/jsp/Passive+Components/Resistors,+Thermistors+&+Potentiometers/PHYCOMP/232270260473/displayProduct.jsp?sku=9233580) |  |  |  | 0.048 | 0.432 | 0.048 | 0.432
R19 | 1 | Resistor | 0805 | Phycomp | 232270260333 | 33k | Farnell | 9233563 (http://uk.farnell.com/jsp/Passive+Components/Resistors,+Thermistors+&+Potentiometers/PHYCOMP/232270260333/displayProduct.jsp?sku=9233563) |  |  |  | 0.048 | 0.048 | 0.048 | 0.048
R25, R26, R27, R28 | 4 | Resistor | 0806 | Tyco | RN73C2A93K1BTG | 93.1k | Farnell | 1141015 (http://uk.farnell.com/jsp/Passive+Components/Resistors,+Thermistors+&+Potentiometers/TYCO+ELECTRONICS/RN73C2A93K1BTG/displayProduct.jsp?sku=1141015) |  |  |  | 0.880 | 3.520 | 0.680 | 2.720
R30, R31, R33 | 3 | Resistor | 0805 | Phycomp | 232270260103 | 10k | Farnell | 9233504 (http://uk.farnell.com/jsp/Passive+Components/Resistors,+Thermistors+&+Potentiometers/PHYCOMP/232270260103/displayProduct.jsp?sku=9233504) |  |  |  | 0.048 | 0.144 | 0.048 | 0.144
Conn1 | 1 | Connector | 12way signal | Camden | CTB93HD/12 | 12way | Camden (http://www.camdenelec.com/) | CTB93HD/12 | Data |  |  | 0.460 | 0.460 | 0.460 | 0.460
Conn1A | 1 | Mating Connector | 12way signal | Camden | CTB92HD/12 | 12way | Camden (http://www.camdenelec.com/) | CTB92HD/12 | Data |  | Not fitted at PCB assembly | 1.060 | 1.060 | 1.060 | 1.060
Conn2 | 1 | Connector | 9Way power | Camden | CTB9358/9 | 9Way | Camden (http://www.camdenelec.com/) | CTB9358/9 | Data (http://www.camdenelec.com/pdf/CTB9208-CTB9358.pdf) |  |  | 0.230 | 0.230 | 0.230 | 0.230
Conn2A | 1 | Mating Connector | 9Way power | Camden | CTB9208/9 | 9Way | Camden (http://www.camdenelec.com/) | CTB9208/9 | Data (http://www.camdenelec.com/pdf/CTB9208-CTB9358.pdf) |  | Not fitted at PCB assembly | 0.650 | 0.650 | 0.650 | 0.600
Conn3 | 1 | Connector | 8way Socket | FCI | 76341-308LF | 8Way | Farnell | 1098038 (http://uk.farnell.com/jsp/Connectors/PCB/FCI/76341-308LF/displayProduct.jsp?sku=1098038) |  |  |  | 0.890 | 0.890 | 0.890 | 0.890
Conn4 | 1 | Connector | 6way header | Harwin | M20-9990645 | 6Way | Farnell | 1022254 (http://uk.farnell.com/jsp/Connectors/Multipole/HARWIN/M20-9990645/displayProduct.jsp?sku=1022254) |  |  |  | 0.280 | 0.280 | 0.280 | 0.280
F1 | 1 | Fuse Holder | SHK20L | Multicomp | MCHTC-15M | 20 x 5mm | Farnell | 146123 (http://uk.farnell.com/jsp/Electrical/Fuse+Holders+&+Accessories/MULTICOMP/MCHTC-15M/displayProduct.jsp?sku=146123) |  |  |  | 0.10 | 0.103 | 0.1 | 0.100
Fuse for above | 1 | Fuse | 20mm | Schurter | 0034.5627.11 | 10A Slow | Farnell | 4448182 (http://uk.farnell.com/jsp/Electrical/Fuses+&+Circuit+Breakers/SCHURTER/0034.5627.11/displayProduct.jsp?sku=4448182) |  |  |  | 0.29 | 0.290 | 0.29 | 0.290
PCB | 1 | PCB |  |  |  |  | PCB Train |  |  |  |  | 37.500 | 37.500 | 13.500 | 13.500
 |  |  |  |  |  |  |  |  |  |  |  | Total/ PCB | 58.349 |  | 32.279
 |  |  |  |  |  |  |  |  |  | Newbury Electronics Quote for components |  |  | 0.000
 |  |  |  |  |  |  |  |  |  | Set-up Tooling
 |  |  |  |  |  |  |  | Not including Case, Label |  |  | Total Electronic components +assy | 200 Batch | 0.000 |  |  | 0.00 | Each

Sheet: Display
Bill of Materials
H2M8
Display Board
Part | Quantity | Type | Package | Manufacturer | Manufacturer Part No | Value | Supplier | Supplier No | Data | Sourced By | Comments | Catalogue | Extended | Newbury | Digikey
Ref. |  |  |  |  |  |  |  |  |  |  |  | Price | price | Electronics
D1, D2, D3 | 3 | Bi colour LED | 5mm | Avago | HLMP-4000 | Red/Green | Farnell | 1003244 (http://uk.farnell.com/jsp/Optoelectronics/LEDs/AVAGO+TECHNOLOGIES/HLMP-4000/displayProduct.jsp?sku=1003244) |  |  |  | 0.23 | 0.69
Sw1 | 1 | Switch | 6mm | Tyco | 9-1437565-3 |  | Farnell | 3801275 (http://uk.farnell.com/jsp/Electrical/Switches+&+Accessories/TYCO+ELECTRONICS/9-1437565-3/displayProduct.jsp?sku=3801275) |  |  |  | 0.08 | 0.08
Conn1 | 1 | 90° pin-H | 0.1" | Tyco | 826947-8 |  | Farnell | 1248174 (http://uk.farnell.com/jsp/Connectors/Multipole/TYCO+ELECTRONICS/826947-8/displayProduct.jsp?sku=1248174) |  |  |  | 0.25 | 0.25
PCB | 1 |  |  | PCB Train |  |  |  |  |  |  | 9 off 10 days |  | 5.55
 |  |  |  |  |  |  |  |  |  |  | Total |  | 6.57

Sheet: Sheet3
Part | Quantity | Type | Package | Manufacturer | Manufacturer Part No | Value | Supplier | Supplier No | Data | Sourced By | Comments | Catalogue | Extended
Ref. |  |  |  |  |  |  |  |  |  |  |  | Price | price
Screws | 2 |  |  |  |  |  |  |  |  |  |  |  | 0.00
Case | 1

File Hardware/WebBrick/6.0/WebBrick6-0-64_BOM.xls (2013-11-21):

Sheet: Sheet1
Bill of Materials
H2M8
WebBrick6-64 (Processor Board)
Original NE Quote ref. |  | E2401
09/05/2007-3
Part | Quantity | Type | Package | Manufacturer | Manufacturer Part No | Value | Supplier | Supplier No | Sourced By | Comments | Catalogue | Extended | Newbury | Digikey
Ref. |  |  |  |  |  |  |  |  |  |  | 200 Price | price | Electronics
C1, C2 | 2 | Capacitor | 1206 | Generic |  | 22pF |  |  | Newbury Electronics | 25 V working Min. |  |  | 0.1050
C3, C5, C14, C15, C16, C17, C18, C19, C20 | 9 | Capacitor | 1206 | Generic |  | 10nF |  |  | Newbury Electronics | 25 V working Min. |  |  | 0.0130
C4, C6 | 2 | Capacitor | 1206 | Generic |  | 100pF |  |  | Newbury Electronics | 25 V working Min. |  |  | 0.0429
C7, C13 | 2 | Capacitor | Case H | Multicomp | MCESL50V107M8X10.5 | 100uF | Farnell | 9265775 | Newbury Electronics | 50V working |  | 0.00 | 0.4030
C8, C9, C10, C11 | 4 | Capacitor | 1206 | Generic |  | 1uF |  |  | Newbury Electronics | 25 V working Min. |  |  | 0.0286
C12 | 1 | Capacitor | Supercap Horizontal | Panasonic | EECS5R5H105 | 1F | Farnell | 9697497 | H2M8 | Mounted underneath | 2.46 | 2.46
C21 | 1 | Capacitor | Case A | AVX | TPSA106K010R1800 | 10uF | Farnell | 1135105 | H2M8 | Low ESR Tant. | 0.16 | 0.16
R1, R9, R16, R19, R22 | 5 | Resistor | 1206 | Generic |  | 1K |  |  | Newbury Electronics |  |  |  | 0.0000
R2, R3, R4, R5, R6, R7, R8, R10, R12 ,R13, R14, R14, R17, R18 | 14 | Resistor | 1206 | Generic |  | 10K |  |  | Newbury Electronics |  |  |  | 0.0000
R20, R21 | 2 | Resistor | 1206 | Generic |  | 4K7 |  |  | Newbury Electronics |  |  |  | 0.0000
D1 | 1 | Diode | SOD123 | On Semi | MBR0540T1G |  | Farnell | 9556923 | Newbury Electronics |  |  | 0.00 | ?
D2 | 1 | Diode | SOD123 | On Semi | MMSD4148T1G |  | Farnell | 9556079 (http://uk.farnell.com/jsp/Semiconductors/Diodes/FAIRCHILD+SEMICONDUCTOR/MMSD914/displayProduct.jsp?sku=4545310) | Newbury Electronics |  |  | 0.00 | ?
IC1 | 1 | IC | SO14 | On Semi. | MC3403D |  | Farnell | 9664408 | H2M8 |  | 0.31 | 0.31 | 0.4030
IC2 | 1 | IC | SO18W | Toshiba | ULN2803AFWG |  | Farnell | 1042086 | H2M8 |  | 0.26 | 0.26 | 0.3380 | 0.25
IC3 | 1 | IC | SO8 | Philips | PFC8563 |  | Farnell | 8906130 | H2M8 |  | 0.95 | 0.95 | 1.2350
U$3 | 1 | IC | SO08 | Nat Semi | LM2674-5 |  | Farnell | 9489754 | H2M8 |  | 1.57 | 1.57 | 2.0410 | 1.53
IC5 | 1 | IC | TQFP64 | MicroChip | 18F6722 |  | Farnell | 8752966 | H2M8 | 8752966 | 4.38 | 4.38 | 6.9680 | 3.93
L1 | 1 | Inductor | L5650M | Panasonic | ELL6RH101M | 100uH | Farnell | 1198604 | H2M8 |  | 0.83 | 0.83 | 1.3130
HB | 1 | LED | 1206 | Generic |  | Blue | Farnell | 8529957 | Newbury Electronics | Std. brightness |  |  | 0.3900
LINK | 1 | LED | 1206 | Generic |  | Green | Farnell | 8530033 | Newbury Electronics | Std. brightness |  |  | 0.0780
PWR | 1 | LED | 1206 | Generic |  | Red | Farnell | 8530025 | Newbury Electronics | Std. brightness |  |  | 0.1580
Q1 | 1 | Crystal | HC49/4H | CMAC | LF A143G | 10MHz | Farnell | 9713328 | Newbury Electronics |  |  | 0.00 | 0.2340
Q3 | 1 | Crystal | TC26V | CMAC | LF A103C | 32.768kHz | Farnell | 9712887 | Newbury Electronics | Bottom mount |  | 0.00 | 0.0299
SV1, SV2 | 2 | Connector | Pin Header |  | FTHD-20-R 185/130/030 | 2x20 | Toby |  | Newbury Electronics |  |  |  | ?
U$1 | 2 | Connector | Pin Headers |  | FTHS-09-R-085/035/025 | 2 separate 9x1 Pin headers | Toby |  | Newbury Electronics | This connector consists of two 9 pin headers |  |  | ?
U$2 | 1 | Connector | Pulse transformer/connector |  | EPJ9372A |  | PCA |  | H2M8 |  | 1.44 | 1.44
ICSP | 1 | Connector | Pin | Right Angle | TSW-106-08-G-S--RA | ICSP | PCA |  | Newbury Electronics | 12.25 OA length 8.2mm mating length |  |  | ?
S1 | 1 | Switch |  | Omron | B3F-3100 |  | Farnell | 959704 | H2M8 | Bottom mount | 0.42 | 0.42
 | 1 | Siteplayer |  |  |  |  |  |  | Not fitted at assembly | Fitted by H2M8
 | 1 | PCB |  |  |  |  | PCB Train @ NE |  | From PCB order by H2M8 | PCB Train @ NE
SR2 |  | Connector | Omit |  |  | Omit |  |  |  | Omit |  | 0.00
DC-IN |  | Connector | Omit |  |  | Omit |  |  |  | Omit |  | 0.00
 |  |  |  |  |  |  |  |  |  |  | Total/ PCB | 12.78
 |  |  |  |  |  |  |  |  |  |  | 200 PCBs | 2556.00
 |  |  |  |  |  |  |  |  | Newbury Electronics Quote for components |  | 18.25 | 3650.00
 |  |  |  |  |  |  |  |  | Set-up Tooling |  |  | 145.00
 |  |  |  |  |  |  |  | Not including Case, Label |  | Total Electronic components +assy | 200 Batch | 6351.00 | 31.75 | Each

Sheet: Sheet2
Bill of Materials |  |  |  |  |  | For H2M8 use only
H2M8
WebBrick6-64 (Processor Board)
Original NE Quote ref. |  |  | E2401
09/05/2007-3
Part | Order Status | Quantity | Type | Package | Manufacturer | Manufacturer Part No | Value | Supplier | Stock No | Sourced By | Comments | Catalogue | Extended | Newbury | Digikey
Ref. |  |  |  |  |  |  |  |  |  |  |  | 200 Price | price | Electronics
C12 |  | 1 | Capacitor | Supercap Horizontal | Panasonic | EECS5R5H105 | 1F | Farnell | 9697497 | H2M8 | Mounted underneath | 2.46 | 2.46
C21 |  | 1 | Capacitor | Case A | AVX | TPSA106K010R1800 | 10uF | Farnell | 1135105 | H2M8 | Low ESR Tant. | 0.16 | 0.16
IC1 |  | 1 | IC | SO14 | On Semi. | MC3403D |  | Farnell | 9664408 | H2M8 |  | 0.31 | 0.31 | 0.4030
IC2 |  | 1 | IC | SO18W | Toshiba | ULN2803AFWG |  | Farnell | 1042086 | H2M8 |  | 0.26 | 0.26 | 0.3380 | 0.25
IC3 |  | 1 | IC | SO8 | Philips | PFC8563 |  | Farnell | 8906130 | H2M8 |  | 0.95 | 0.95 | 1.2350
U$3 |  | 1 | IC | SO08 | Nat Semi | LM2674-5 |  | Farnell | 9489754 | H2M8 |  | 1.57 | 1.57 | 2.0410 | 1.53
IC5 |  | 1 | IC | TQFP64 | MicroChip | 18F6722 |  | Farnell | 8752966 | H2M8 | 8752966 | 4.38 | 4.38 | 6.9680 | 3.93
L1 |  | 1 | Inductor | L5650M | Panasonic | ELL6RH101M | 100uH | Farnell | 1198604 | H2M8 |  | 0.83 | 0.83 | 1.3130
U$2 | Ordered by JG | 1 | Connector | Pulse transformer/connector |  | EPJ9372A |  | PCA |  | H2M8 |  | 1.28 | 1.28
S1 |  | 1 | Switch |  | Omron | B3F-3100 |  | Farnell | 959704 | H2M8 | Bottom mount | 0.42 | 0.42
 | 100 ordered by JG | 1 | Siteplayer |  |  |  |  |  |  | Not fitted at assembly | Fitted by H2M8
 | 200 ordered by JG | 1 | PCB |  |  |  |  | PCB Train @ NE |  | From PCB order by H2M8 | PCB Train @ NE
SR2 |  |  | Connector | Omit |  |  | Omit |  |  |  | Omit |  | 0.00
DC-IN |  |  | Connector | Omit |  |  | Omit |  |  |  | Omit |  | 0.00
 |  |  |  |  |  |  |  |  |  |  |  | Total/ PCB | 12.62
 |  |  |  |  |  |  |  |  |  |  |  | 200 PCBs | 2524.00

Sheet: Sheet3
 |  |  |  | Connectors | Total Quant of | Complete | Total Quant | £ | loose less | Loose Inc | Cost /WB
 | per100 | Each | 250 Box | per WB | Conns Req | Boxes | In boxes | Boxed cost | Handling | 10% handling
CTB92HD/12 | 106.16 | 1.062 | 265.40 | 4 | 800 | 4 | 1000 | 1061.60 | 849.28 | 934.208 | 4.2464
CTB93HD/12 | 46 | 0.460 | 115.00 | 4 | 800 | 4 | 1000 | 460.00 | 368.00 | 404.8 | 1.84
CTB9208/9 | 65.025 | 0.650 | 162.56 | 2 | 400 | 2 | 500 | 325.13 | 260.10 | 286.11 | 1.3005
CTB9308/9 | 22.56 | 0.226 | 56.40 | 2 | 400 | 2 | 500 | 112.80 | 90.24 | 99.264 | 0.4512
 |  |  |  |  |  |  |  | 1959.52 | 1567.62 | 1724.382 | 7.8381
WB Batch size | 200 |  |  |  |  |  |  |  | Difference | 235.14
Purchase Batch size |  | 250.000

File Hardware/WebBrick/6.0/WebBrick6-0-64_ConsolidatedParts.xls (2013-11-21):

Type | Manufacturer |  | Value | Quantity | Supplier | Part Nr | 100+ Cost | Cost | Comment | Alternate
pcb | NE |  |  | 1
Assembly | NE |  |  | 1
Resistor | Generic |  | 1K | 5 | Farnell | 3457497 | £0.01 | £0.05
 | Generic |  | 10K | 14 | Farnell | 3457618 | £0.01 | £0.14
 | Generic |  | 4K7 | 2 | Farnell | 3457576 | £0.02 | £0.04
Capacitor | Generic |  | 22pF | 2 | Farnell | 3449208 | £0.03 | £0.06
 | Generic |  | 10nf | 9 | Farnell | 3449336 | £0.03 | £0.27
 | Generic |  | 100pf | 2
 | Generic |  | 1uF | 4 | Farnell | 9227873 | £0.06 | £0.24
 | MultiComp | MCESL50V107M8X10.5 | 100uF/25V | 2 | Farnell | 9265775 | £0.35 | £0.70
 | Panasonic | EECS5R5H105 | 1F | 1 | Farnell | 9697497 | £2.46 | £2.46
 | AVX | TPSA106K010R1800 | 10uF | 1 | Farnell | 1135105 | £0.16 | £0.16 | LOW ESR
Diode | Zetex | ZLLS400 |  | 2 | Farnell | 9525661 | £0.14 | £0.28
Connector |  |  | 6 Pin | 1 | Farnell | 1022264 | £0.24 | £0.24 | ICSP
 |  |  | 2*20 | 2 |  |  |  |  | Provide interboard gap of 13.5 to 14mm. Approx 5m above standard socket on IO board
 |  |  | 9 way | 2 | Farnell |  |  |  | Standard PIN header
LED | Generic |  | blue | 1 | Farnell | 8529957 | £0.37 | £0.37
 | Generic |  | Red | 1 | Farnell | 8530025 | £0.06 | £0.06
 | Generic |  | Green | 1 | Farnell | 8530033 | £0.06 | £0.06
Inductor | Panasonic | L5650M | 100uH | 1 | Farnell | 1198604 | £0.80 | £0.80
Xtal | CMAC | LF A143G | 10Mhz | 1 | Farnell | 9713328 | £0.30 | £0.30
 | CMAC | LF A103C | 32.768Khz | 1 | Farnell | 9712887 | £0.28 | £0.28
IC | Microchip | PIC18F6627 |  | 1 | Farnell | 8752974 | £4.03 | £4.03 | Any of 6722, 6627 6622
 | ON Semi. | MC3403DG |  | 1 | Farnell | 9664408 | £0.30 | £0.30 | OpAmp
 | Toshiba | ULN2803AFW |  | 1 | Farnell | 1042086 | £0.25 | £0.25 | O/C
 | Philips | PCF8563 |  | 1 | Farnell | 8906130 | £0.92 | £0.92 | RTC
 | Nat Semi | LM2674M-5.0 |  | 1 | Farnell | 9489754 | £1.46 | £1.46 | PS
Misc |  |  | Siteplayer | 1 | NetMedia |  | £18.00 | £18.00 | h2m8 to fit
 |  |  | PulseTrans | 1 | PCA EPJ9372A |  |  |  | Free issue
 |  |  | ResetSwitch | 1 | Farnell | 959704 | £0.42 | £0.42 | Or 959704,959716,3096038,3096040,3096051
 |  |  |  |  |  |  |  | £0.00
 |  |  |  |  |  |  |  | £31.89
 |  |  |  | 65

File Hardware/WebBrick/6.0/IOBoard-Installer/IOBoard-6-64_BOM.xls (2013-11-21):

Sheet: Sheet1
Bill of Materials
H2M8
I/O Board
Original NE Quote ref | E2400
17/05/2007-1
Part Ref. | Quant | Type | Package | Manufacturer | Manufacturer Part No | Value | Supplier | Supplier No | Sourced By | Comments | Catalogue 200 price | Extended Price | Newbury Electronics | Digikey | Rapid | CPC | Newark
R1, R2, R3, R4, R5, R6, R7, R8, R9, R10, R11, R12, R13, R14, R15, R16, R17, R18, R19, R20, R29, R30, R31, R32 | 24 | Resistor | 1206 | Generic |  | 330R |  |  | Newbury Electronics |  | 0.00 | 0.00 | 0.0000
R23, R37,R38 | 3 | Resistor | 1206 | Generic |  | 10K |  |  | Newbury Electronics |  | 0.00 | 0.00 | 0.0000
R24 | 1 | Resistor | 1206 | Generic |  | 100R |  |  | Newbury Electronics |  | 0.00 | 0.00 | 0.0000
R25, R26, R27, R28, R33, R34, R35, R36, R39, R40 | 10 | Resistor | 1206 | Generic |  | 47K |  |  | Newbury Electronics |  | 0.00 | 0.00 | 0.0000
C1, C2, C3, C4, C5, C6, C7, C8, C11, C12, C13, C14, C15, C16, C17, C18, C19, C20, C21, C22, C23, C24, C25, C26, C27, C28, C29, C30, C31, C32, C33, C34 | 32 | Capacitor | 1206 | Generic |  | 1nF |  |  | Newbury Electronics | 25V working Min. | 0.00 | 0.00 | 0.0065
C9, C10 | 2 | Capacitor | 1206 | Generic |  | 10nF |  |  | Newbury Electronics | 25V working Min. | 0.00 | 0.00 | 0.0156
C37, C39. C40, C41, C42, C43 | 6 | Capacitor | 1206 | Generic |  | 100nF |  |  | Newbury Electronics | 25V working Min. | 0.00 | 0.00 | 0.0065
C38 | 1 | Capacitor | 3216 | AVX | TPSA106K010R1800 | 10uF | Farnell | 1135105 | H2M8 | Low Esr | 0.16 | 0.16
D1 | 1 | Diode | DO214AC | Multicomp | S1A |  | Farnell | 7277920 | Newbury Electronics |  |  | 0.00 | ?
D2 | 1 | Diode | SOD123 | On Semi | MBR0540T1G |  | Farnell | 9556923 | Newbury Electronics |  |  | 0.00 | ?
DRV1, DRV2, DRV3, DRV4 | 4 | OptoCoupler | DIL06 | Fairchild | MOC3043 |  | Farnell | 1021371 | Newbury Electronics |  |  | 0.00 | 0.3510 | 0.33
IC1 | 1 | IC | SOICW | Allegro | A2982SLW-T |  | Digikey | 620-1033-ND | H2M8 |  | 0.89 | 0.89 | 1.1570 | 0.61 |  |  | $1.41
IC2 | 1 | IC | SO08 | Analog Devices | ADM485JRZ |  | Farnell | 9426264 | H2M8 |  | 0.65 | 0.65 | 1.7290
IC3 | 1 | IC | TSSOP16 | Texas | MAX3221CPWE4 |  | Farnell | 1053614 | H2M8 |  | 0.43 | 0.43 | 1.7810
K1, K2 | 2 | Relay | G2R2 | IMO | SRRHN-2CN-SL-12VDC |  | Farnell | 1094016 | H2M8 |  | 1.90 | 3.80 | 3.5880
Q1 | 1 | Transistor | SOT223 | Zetex | FZT690B |  | Farnell | 9525203 | Newbury Electronics |  |  | 0.00 | 0.7020
T1, T2 | 2 | Transistor | SOT23 | Philips | BCW60B |  | Farnell | 1081266 | Newbury Electronics |  |  | 0.00 | 0.0390
 |  |  |  |  |  |  |  |  |  |  |  | 0.00
U$3, U$4, U$5, U$6 | 4 | Triac | TO220AV | ST Micro. | BTA08-600CWRG |  | Farnell | 1057270 | Newbury Electronics |  |  | 0.00 | 0.8190
SV1, SV2 | 2 | Connector | MA20-2 | Toby | 309AE-40-SGBSKA3 | 2x20 | Samtec | 7992033 | Newbury Electronics |  |  | 0.00 | ? |  |  | 1.07
U$1, U$2, u$7, u$8 | 4 | Connector | MC123.5PITCH | Camden | CTB93HD/12 | Male | Camden | CTB93HD/12 | H2M8 | 3.5mm Horizontal | 0.43 | 1.72 | 0.7774
X1, X2 | 2 | Connector | 9-G-5,08 | Camden | CTB9358/9 | Male | Camden | CTB9358/9 | H2M8 | 5.08mm Horizontal | 0.23 | 0.45 | 0.3120
F1 | 1 | Fuse Holder | SHK20L | Multicomp | MCHTC-15M |  | Farnell | 146123 | Newbury Electronics |  |  | 0.00 | 0.0884
HS1 | 1 | Heatsink |  | ABL | PPC50 Black Anodised |  | ABL |  | H2M8 | 50mm Clipon heatsink | 2.00 | 2.00
To be fitted after PCB assembly
F2 | 1 | Fuse | 20 x 5mm | Generic | 6.3A 20mm Slow-Blow | 6.3 Amp Slow Blow |  |  | Newbury Electronics | Can be fitted to holder before soldering if method allows |  | 0.00 | 0.0520
 | 4 | Connector |  | Camden | CTB92HD/12 | Female | Camden | CTB92HD/12 | H2M8 | Mating connectors for U$1 etc. | 1.06 | 4.25
 | 2 | Connector |  | Camden | CTB9208/9 | Female | Camden | CTB9208/9 | H2M8 | Mating Connectors for X1,X2 | 0.65 | 1.30
 |  |  |  |  |  |  |  |  |  |  | Total/PCB | 15.65
 |  |  |  |  |  |  |  |  |  |  | 200 PCBs | 3129.62
 |  |  |  |  |  |  |  |  | Newbury Electronics Quote for components |  | 28.92 | 5784.00
 |  |  |  |  |  |  |  |  | Set-up Tooling |  |  | 145.00
 |  |  |  |  |  |  |  | Not including Case Label |  | Total Electronic components + assy. | 200 Batch | 9058.62 | 45.29 | Each

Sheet: Sheet2
Bill of Materials
H2M8
I/O Board
Original NE Quote ref |  | E2400 |  | For H2M8 use only
09/05/2007-3
Part Ref. | Order Status | Quant | Type | Package | Manufacturer | Manufacturer Part No | Value | Supplier | Supplier No | Sourced By | Comments | Catalogue 200 price | Extended Price | Newbury Electronics | Digikey | Rapid | CPC | Newark
C38 |  | 1 | Capacitor | 3216 | AVX | TPSA106K010R1800 | 10uF | Farnell | 1135105 | H2M8 | Low Esr | 0.16 | 0.16
IC1 | In stock | 1 | IC | SOICW | Allegro | A2982SLW-T |  | Digikey | 620-1033-ND | H2M8 |  | 0.89 | 0.89 | 1.1570 | 0.61 |  |  | $1.41
IC2 |  | 1 | IC | SO08 | Analog Devices | ADM485JRZ |  | Farnell | 9426264 | H2M8 |  | 0.65 | 0.65 | 1.7290
IC3 |  | 1 | IC | TSSOP16 | Texas | MAX3221CPWE4 |  | Farnell | 1053614 | H2M8 |  | 0.43 | 0.43 | 1.7810
K1, K2 |  | 2 | Relay | G2R2 | IMO | SRRHN-2CN-SL-12VDC |  | Farnell | 1094016 | H2M8 |  | 1.90 | 3.80 | 3.5880
U$1, U$2, u$7, u$8 |  | 4 | Connector | MC123.5PITCH | Camden | CTB93HD/12 | Male | Camden | CTB93HD/12 | H2M8 | 3.5mm Horizontal | 0.43 | 1.72 | 0.7774
X1, X2 |  | 2 | Connector | 9-G-5,08 | Camden | CTB9358/9 | Male | Camden | CTB9358/9 | H2M8 | 5.08mm Horizontal | 0.23 | 0.45 | 0.3120
HS1 | 2007-06-06 | 1 | Heatsink |  | ABL | PPC50 Black Anodised |  | ABL |  | H2M8 | 50mm Clipon heatsink | 1.33 | 1.33
To be fitted after PCB assembly
 |  | 4 | Connector |  | Camden | CTB92HD/12 | Female | Camden | CTB92HD/12 | H2M8 | Mating connectors for U$1 etc. | 1.06 | 4.25
 |  | 2 | Connector |  | Camden | CTB9208/9 | Female | Camden | CTB9208/9 | H2M8 | Mating Connectors for X1,X2 | 0.65 | 1.30
 |  |  |  |  |  |  |  |  |  |  |  | Total/PCB | 14.98
 |  |  |  |  |  |  |  |  |  |  |  | 200 PCBs | 2995.62

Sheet: Sheet3
WebBrick Top level BoM
Order Status | Quant | Type | Manufacturer | Manufacturer Part No | Supplier | Supplier No | Sourced By | Comments | Catalogue 200 price | Extended Price
 | 1 | I/O PCB |  |  |  |  |  |  | 45.29 | 9058.00
 | 1 | Processor PCB |  |  |  |  |  |  | 31.76 | 6352.00
2007-06-22 | 1 | Enclosure |  |  |  |  |  |  | 17.35 | 3470.00
100 in stock | 1 | Siteplayer |  |  |  |  |  |  | 10.00 | 2000.00
Graphics | 1 | Label |  |  |  |  |  |  | 3.00 | 600.00
 |  | Screws |  |  |  |  |  |  |  | 0.00
 |  |  |  |  |  |  |  | Total | 107.40 | 21480.00

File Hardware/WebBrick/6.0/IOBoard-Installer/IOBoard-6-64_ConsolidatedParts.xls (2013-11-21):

Type | Package | Manufacturer | PartNr | Value | Quantity | Supplier | Farnell Part Nr | 100+ Price |  | Comment | CPC | Digikey | Rapid | RS
PCB |  |  |  |  | 1 | NE
Resistors | 1206 | Generic |  | 100 | 1 |  |  | £0.02 | £0.02
 | 1206 | Generic |  | 330 | 24 |  |  | £0.02 | £0.48
 | 1206 | Generic |  | 10K | 3 |  |  | £0.02 | £0.06
 | 1206 | Generic |  | 47K | 10 |  |  | £0.02 | £0.20
 |  |  |  |  |  |  |  |  | £0.00
Capacitor | 1206 | Generic |  | 10nf | 2 |  |  | £0.03 | £0.06
 | 1206 | Generic |  | 1nf | 32 |  |  | £0.06 | £1.92
 | 1206 | Generic |  | 100nf | 6 |  |  | £0.03 | £0.18
 | 3216 | AVX | TPSA106K010R1800 | 10uf | 1 |  | 1135105 | £0.16 | £0.16 | Low ESR
 |  |  |  |  |  |  |  |  | £0.00
OptoTriac |  |  | MOC3042 |  | 4 | Farnell | 1021368 | £0.35 | £1.40 | Low stock |  | 0.33
 |  |  |  |  |  |  |  |  | £0.00
Triac |  |  |  |  | 4 | Farnell | 1057270 | £0.63 | £2.52
 |  |  |  |  |  |  |  |  | £0.00
Diode |  | Zetex | ZLLS400 |  | 1 | Farnell | 9525661 | £0.14 | £0.14
Diode |  | Multicomp | S1A |  | 1 | Farnell | 7277920 | £0.05 | £0.05
 |  |  |  |  |  |  |  |  | £0.00
IC |  | Allegro | A2982SLW-T |  | 1 | Farnell | 1329620 | £0.89 | £0.89 | Awaiting delivery |  | 0.61
IC | SO08 | Analog Devices | ADM485JRZ |  | 1 | Farnell | 9426264 | £0.65 | £0.65 |  |  | 0.48
IC | TSSOP16 | Texaas | MAX3221CPWE4 |  | 1 | Farnell | 1053614 | £0.43 | £0.43 | MAX3221CPWR |  | 0.43
 |  |  |  |  |  |  |  |  | £0.00
Transistor | SOT223 | Zetex | FZT690B |  | 1 | Farnell | 9525203 |  | £0.00
Transistor | SOT23 | Philips | BCW60B |  | 2 | Farnell | 1081266 |  | £0.00
 |  |  |  |  |  |  |  |  | £0.00
 |  |  |  |  |  |  |  |  | £0.00
 |  |  |  |  |  |  |  |  | £0.00
Connector |  | Harwin | 2*20 |  | 2 | Farnell | 7992033 | £2.11 | £4.22 | Pin header | 1.07
 |  | Camden | 9 RA Way pcb |  | 2 | Camden |  | £0.50 | £1.00 | Horizontal
 |  | Camden | 9 screwdown |  | 2 |  |  | £0.65 | £1.30
 |  | Camden | 12 RA way pcb |  | 4 | Camden |  | £1.50 | £6.00 | 3.5mm Horizontal
 |  | Camden | 12 screwdown |  | 4 |  |  | £1.06 | £4.24
 |  |  |  |  |  |  |  |  | £0.00
Fuse Holder |  |  |  |  | 1 | Farnell | 146123 | £0.07 | £0.07 | What about 976120
Fuse |  |  |  | 6.3T | 1
Relay |  | IMO | SRRHN-2CN-SL-12VDC |  | 2 | Farnell | 1094016 | £1.90 | £3.80
HeatSink |  |  |  |  | 1 |  |  | £2.00 | £2.00 | h2m8 supply
 |  |  |  |  |  |  |  |  | £0.00
 |  |  |  |  | 113 |  |  |  | £31.79

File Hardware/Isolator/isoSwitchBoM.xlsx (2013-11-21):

WebBrick 7.0
BoM
Ref | Qty | Value | Name | Description | Package | Mrf Pt No | Supplier | Supplier Pt No. | Price Each | Price per | Price
 |  |  |  |  |  |  |  |  | Lo Q | unit | 200 off
C1 | 1 | 0.1uF | 1206CAP |  | 1206
Conn1 | 1 | PIN | CTB9358- |  | TH |  | Camden | 3704853 (http://uk.farnell.com/3704853/connectors/product.us0?sku=phoenix-contact-1843648)
Conn1A |  |  |  |  |  |  |  | 5088999 (http://uk.farnell.com/5088999/connectors/product.us0?sku=phoenix-contact-mc-1-5-6-st-3-5)
Conn2 | 1 | PIN |  |  |  |  |  | 3705274 (http://uk.farnell.com/3705274/connectors/product.us0?sku=phoenix-contact-1755749)
Conn2A |  |  |  |  |  |  |  | 3705547 (http://uk.farnell.com/3705547/connectors/product.us0?sku=phoenix-contact-1792760)
Conn3 | 1 | PIN | CTB93HD- |  | TH |  | Camden | 3705286 (http://uk.farnell.com/3705286/connectors/product.us0?sku=phoenix-contact-1755752)
onn3A |  |  |  |  |  |  |  | 3705559 (http://uk.farnell.com/3705559/connectors/product.us0?sku=phoenix-contact-1792773)
FS1 | 1 |  | 20mmFuse Holder |  | DSC |  |  | 146123 (http://uk.farnell.com/jsp/Electrical/Fuse+Holders+&+Accessories/MULTICOMP/MCHTC-15M/displayProduct.jsp?sku=146123) | 0.11 | 0.108
FS2 | 1 |  | 20mm 8A fuse |  |  |  |  |  |  | 0
FS3 | 1 |  | Plastic cover
Neo | 3 |  | 4mm neon |  |  |  |  | 1139245 (http://uk.farnell.com/1139245/optoelectronics/product.us0?sku=multicomp-mc08020000) | 0.11 | 0.336
LED1 | 2 | Green | 5mm led |  | 5mm |  |  | 1003214 (http://uk.farnell.com/1003214/optoelectronics/product.us0?sku=avago-technologies-hlmp-3507) | 0.09 | 0.18
RL1, RL2 | 6 |  | Relay |  | DSC |  |  | 1094016 (http://uk.farnell.com/jsp/Electrical/Relays+&+Solenoids/IMO/SRRHN-2CN-SL-12VDC/displayProduct.jsp?sku=1094016) | 2.43 | 14.58
Cons Unit | 1 |  |  |  |  |  | Screwfix | 46968 (http://www.screwfix.com/prods/46968/Electrical/Consumer-Units/Wylex-Consumer-Units/Wylex-2W-63A-DP-Isolator-Sw-Consumer-Unit) | 11.23 | 11.23
R1 | 1 |  |  |  |  |  |  |  |  | 0
Sw1, Sw2 | 2 |  | 10A Mains Switch |  |  |  |  | 140626 (http://uk.farnell.com/140626/electrical-circuit-protection/product.us0?sku=arcolectric-switches-c1710hoaab) | 1.43 | 2.86
Sw3 | 1 |  | LV Toggle Switch |  |  |  |  | 9473378 (http://uk.farnell.com/9473378/electrical-circuit-protection/product.us0?sku=multicomp-1ms1t1b5m1qe) | 0.80 | 0.8
Screws |  |  |  |  |  |  |  |  |  | 0
PCB | 1 |  |  |  |  |  |  |  | 21.00 | 21
 |  |  |  |  |  |  |  |  | 37.20 | 51.094

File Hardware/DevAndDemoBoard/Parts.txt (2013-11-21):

Partlist

Exported from WebBrick6-0-64.sch at 23/01/2006 17:06:51 

EAGLE Version 4.13 Copyright (c) 1988-2004 CadSoft

Part     Value           Device            Package          Library                 Sheet

C1       22pF            C-EUC1206         C1206            rcl                     1
C2       22pF            C-EUC1206         C1206            rcl                     1
C3       0.01uF          C-EUC1206         C1206            rcl                     1
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

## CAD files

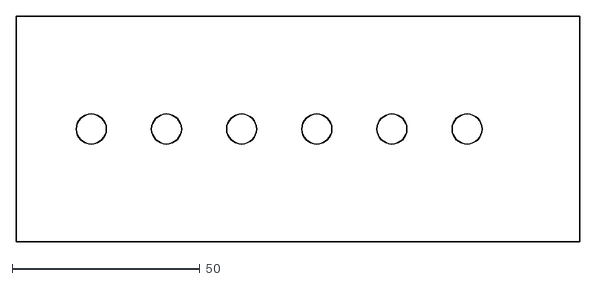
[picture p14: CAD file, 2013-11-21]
Hardware/Milling Designs/19Front.dxf
150.0 x 60.0

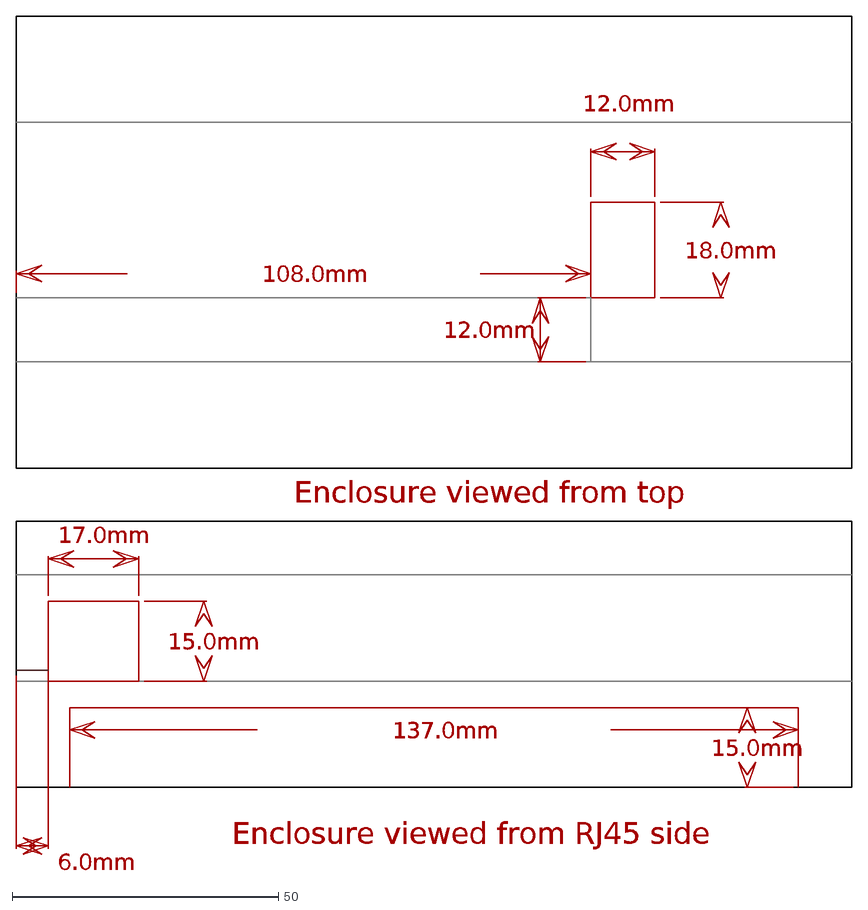
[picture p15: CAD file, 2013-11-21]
Hardware/WebBrick/6.0/Enclosure and Top Artwork/Enclosure.dxf
15.0mm
137.0mm
6.0mm
17.0mm
Enclosure viewed from RJ45 side
12.0mm
18.0mm
108.0mm
Enclosure viewed from top

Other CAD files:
Hardware/Milling Designs/19Front.dwg
Hardware/PowerSupply/Resilient.skp
Hardware/SwitchPlates/Hamilton.skp
Hardware/SwitchPlates/HamiltonSingle.skp
Hardware/SwitchPlates/TouchSwitch/FrontPlate.skp
Hardware/SwitchPlates/TouchSwitch/RoughSketch.skp
Hardware/WebBrick/6.0/Enclosure and Top Artwork/6.4 Enclosure.skp

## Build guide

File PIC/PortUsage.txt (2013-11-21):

Webbrick 6/18F6722 family

AH some updates
LPK notes added 23/4/2007. A4 is still free.

Port A
------
0 | Analogue In 0
1 | Analogue In 1
2 | Analogue In 2
3 | Analogue In 3
4 | NU
5 | Digital In 8 (Monitor)
6 | XTAL
7 | XTAL

Port B
------
Digital inputs 0-7

Port C
------
0 | Unused?
1 | An Out/PWM 1
2 | An Out/PWM 0
3 | I2C - RTC
4 | I2C - RTC
5 | 12V mimic enable.
6 | EUSART 1 Rx - Siteplayer
7 | EUSART 1 Tx - Siteplayer

Port D
------
Digital outputs 0-7
0-3 | Triacs + OC?
4-7 | 2 Relays + Digital Logic Out

Port E
------
Mimics 0-7

Port F
------
0 | Digital In 9 (Monitor)
1 | Digital In 10 (Monitor)
2 | Digital In 11 (Monitor)
3 | Dallas 1 Wire
4 | Unused - was resrved for 1 Wire FET driver.
5 | Heartbeat
6 | (xRotary) ---  RS232/RS485 selection
7 | (xRotary) ---  RS485 TX Enable

Port G
------
0 | An Out/PWM 2
1 | EUSART 2 Tx
2 | EUSART 2 Rx
3 | An Out/PWM 3
4 | Factory Reset Button
5 | MCLR - programming control PIN.

=========================================================================================================
					WebBrick 5/18F4525 family
=========================================================================================================

PORT A
------
0 | 4.7K Analogue 0 input.
1 | Digital In 8 (Monitor)
2 | Digital In 9 (Monitor)
3 | Digital In 10 (Monitor)
4 | Digital In 11 (Monitor)
5 | Edge
6 | XTal
7 | XTal

PORT B
------
Digital inputs 0-7

PORT C
------
0 | ICD, unused
1 | An Out/PWM 1
2 | An Out/PWM 0
3 | unused
4 | 4.7K pullup Rotary encoder
5 | 4.7K pullup Rotary encoder
6 | EUSART 1 Rx - Siteplayer
7 | EUSART 1 Tx - Siteplayer

PORT D
------
Digital outputs 0-7

PORT E
------
0 | Dallas 1 Wire
1 | DMX out ???
2 | Heartbeat

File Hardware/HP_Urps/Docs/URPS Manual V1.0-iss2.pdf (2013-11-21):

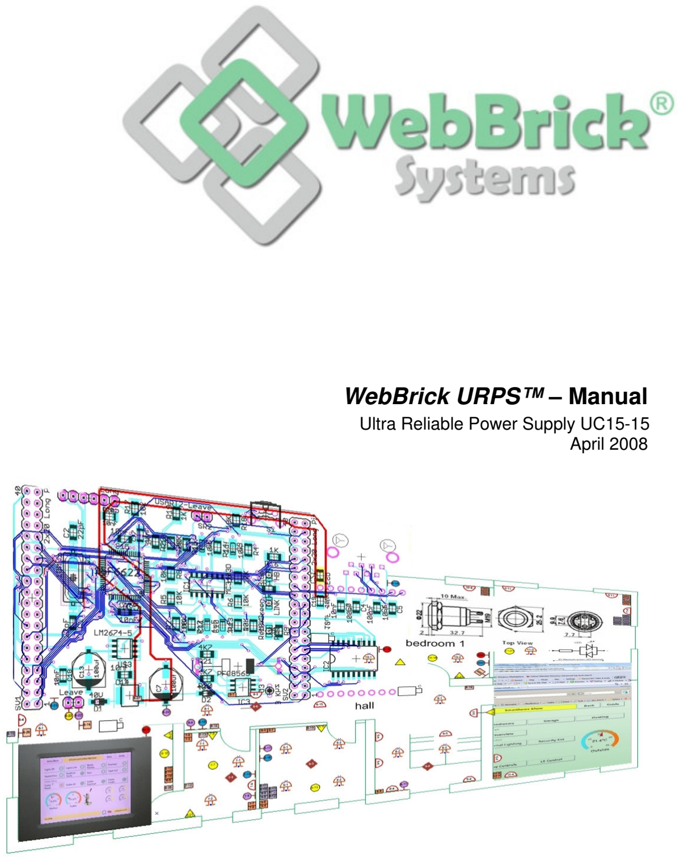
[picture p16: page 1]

## WebBrick URPS™ – Manual

### Ultra Reliable Power Supply UC15-15 April 2008

### Features

| Multiple redundant power supply; Two mains power supplies plus one battery
| Battery charge management to protect against over-discharge, for maintenance of performance, and over-charge, for safety
| Load shedding output, for extending battery discharge time to essential services
| Status and alarm communication via serial port to WebBrick Controller™ or WebBrick Gateway™
| Charge voltage adjustment indication for precision setting of float voltage
| Visual alarm indication on all power inputs
| Visual “heart-beat” indication during normal operation
| Audible alarm when urgent attention is required, battery <11V or mains supplies under- volts
| Low quiescent current
| Press button to enable display for power saving and alarm cancelling
| 105mm wide DIN rail housing with rising clamp connectors

### Background

In a home automation system where continuous uninterrupted operation of the local control is a must, to prevent brown-outs and maintain a certain level of service during mains power-outage, a battery back-up system is essential. User information about the power supply condition is available directly from the front panel or by remote monitoring through the WebBrick Controller™ and WebBrick Gateway™. This information allows the user to take appropriate action which may be overlooked in a dumb system. Battery maintenance is also a crucial factor and to this end, the WebBrick URPS™ will prevent abuse of the battery by switching charge and discharge current to prevent damaging voltage excursions. Ultra reliability is provided by combining the input from two AC mains to DC power supplies and one rechargeable battery. The WebBrick URPS is a device custom-designed for use in an environment that requires little maintenance and will give the user confidence and peace of mind.

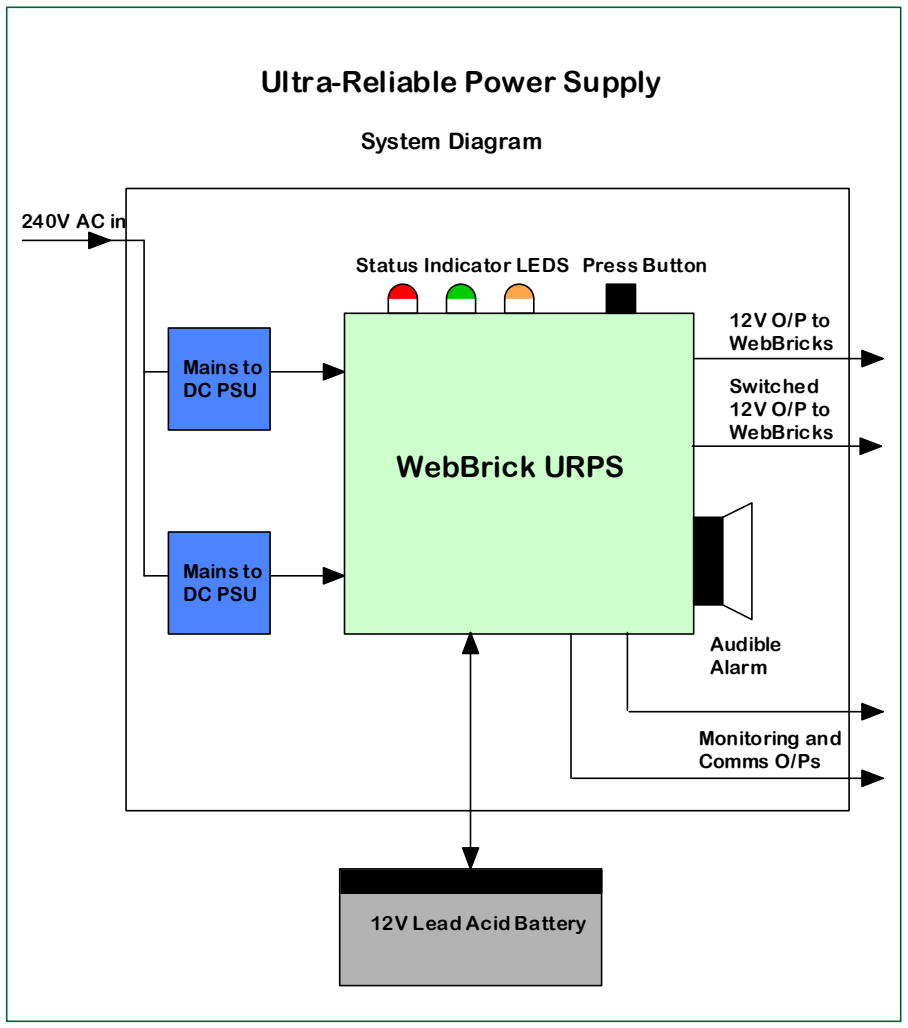
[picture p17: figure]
Mains to DC PSU; WebBrick URPS; 12V Lead Acid Battery; Status Indicator LEDS Press Button; Audible Alarm; 12V O/P to WebBricks; Ultra-Reliable Power Supply; System Diagram; Monitoring and Comms O/Ps; Switched 12V O/P to WebBricks

Fig1. Layout of a WebBrick URPS with 2 PSUs & battery

### General Description

The WebBrick URPS is most often deployed with 3 other components, a 12V lead acid battery and two mains to 12V (nominal) DC power supplies (PSUs), they are laid out as in Fig1.

It is a triple-redundant power source to provide ultra-reliable supply for WebBrick installations.

The specification of the PSUs and 12V lead-acid battery must be determined by the installer. Batteries are to be sourced independently of WebBrick Systems.

### Power Supply and Battery Selection

Battery
First of all, the capacity of the battery selected will be dependent on the run time as discussed below. Once the battery capacity is established, suitable power supplies can be selected. Getting a good balance between the power supply and the battery is essential to ensure against excessive charge current to the battery or overloading the power supplies. As a rule of thumb, the total charge current in Amps available from both power supplies added together should not be less than the 1/10 of the battery capacity expressed in Amp.hours and should not be greater than ½ of the battery capacity expressed in Amp.hours. For example when using a 60Ah battery, the combined power supply currents should add up to between 6A and 30A. It is important that the battery selected is capable of taking a full charge current which can be as much as the rating of both the PSUs added together. For example, when using two 15A PSUs, the battery must be capable of charging at 30A otherwise cycle life and more importantly safety will be compromised. Always verify the technical specification of the battery before connecting it to the system. Use only batteries designed for deep-discharge as actual “car batteries” rarely fulfil this criterion.

Warning:
Large capacity lead acid batteries can give extremely high current if short circuited and the correct handling procedures must be observed as per the battery manufacturers guide lines. Be sure to site vented lead acid batteries in appropriate locations.

Run-time
The capacity of the battery will depend on the load normally applied to the WebBrick URPS output under mains failure conditions and the length of time required to keep the system live. The load during a power-outage must take into account devices not normally used in day to day operation such as emergency lighting.

E.g. Total load including emergency lighting plus WebBrick overhead etc. = 15A, using a battery of 150Ah (assuming it’s fully charged and in good condition) it will give…

150/15 = 10 hours

When using the switched, load-dumping output from the WebBrick URPS which closes down at approximately 50% remaining charge, this will need to be factored into any calculation of run-time.

One should bear in mind that batteries degrade over time and it may well be worth over-rating the capacity so a certain amount of reduction is acceptable on the runtime of the system with age.

Charging time is a little more complex to estimate due to the effects of thermal management when charging from fully discharged and the effects of current taper near full charge. A test to determine the charge time should be run if it is critical.

Power supply units (PSUs)
One option is to use the WebBrick URPS with the low power 1.25A PSUs commonly supplied by WebBrick Systems, in this case the maximum recommended battery capacity is no greater than 25Ah.

It is important that the power supplies selected can cope with battery charging duty. The worst case is where the battery is at 10V and the power supply is set to 13.8V. A current limit is essential within the power supply that doesn’t prevent it operating under such conditions. WebBrick Systems doesn’t recommend the use of actual battery chargers to double as power supplies because of the output voltage ripple. Some dedicated chargers are set to change voltage under certain conditions of charge current which could confuse the alarm sensing function of the WebBrick URPS.
Use only high quality power supplies in order to take advantage of the system reliability the
WebBrick URPS offers.

### Installation

The WebBrick URPS and its associated adjustable PSUs should be fitted to a suitable DIN rail and the battery located as close as possible while observing the warnings.
Once the WebBrick URPS is in position between its two mains to DC power supply units (PSUs), an example is shown in Fig2, connect the DC supplies to the WebBrick URPS, but do not connect the battery at this stage.

At switch-on, the WebBrick URPS will go through its start-up routine to test the LEDs and audible alarm (if enabled). Press the display enable button and the LEDs will give a full status read-out for about 2 minutes before going into power-save mode. Press the button again for more display time. Ignore any audible or flashing LEDs at this stage until the controller has been fully set up. To attain the correct output from the WebBrick URPS for float charging the battery, press and hold the display button for the duration of the adjustment procedure. Switch on the power supplies in-turn and adjust the outputs of each of the two mains PSUs until the top two LEDS show pure green. The LEDs will show pure red when the voltage is too low and a mix of the two colours to show orange when the voltage is too high. The top LED indicates the voltage of PSU1 and the centre LED indicates the voltage of PSU2. Careful adjustment will bring the voltages into the centre of the acceptable range. The button can be released at this time and the indicator LEDS will now show the normal running status on the PSUs. Once adjusted, the battery float-charge voltage will be close to 13.8V (at the battery) which is the standard for almost all lead acid batteries work to. Checking the actual output voltage of the PSUs will reveal a level of close to 14V, the difference is due to the voltage drop in the diodes in the WebBrick URPS.

It is now time to connect the battery. The battery input has a fuse which will blow if a battery is connected with reversed polarity so care is needed at this stage. A healthy battery should be above 11.0V when connected, if it is lower, the bottom LED will show red (in display mode) until the battery has charged to above 11.0V, the PSU1 and PSU2 indicator LEDs may show red, this is normal, it indicates that the mains power supplies are working at their maximum output. Use cable of the appropriate gauge to connect the battery to keep the resistance low and charging time down. Once the battery is near fully charged the top two LEDs will show constantly green (in display mode), indicating the charge current to the battery has dropped significantly.

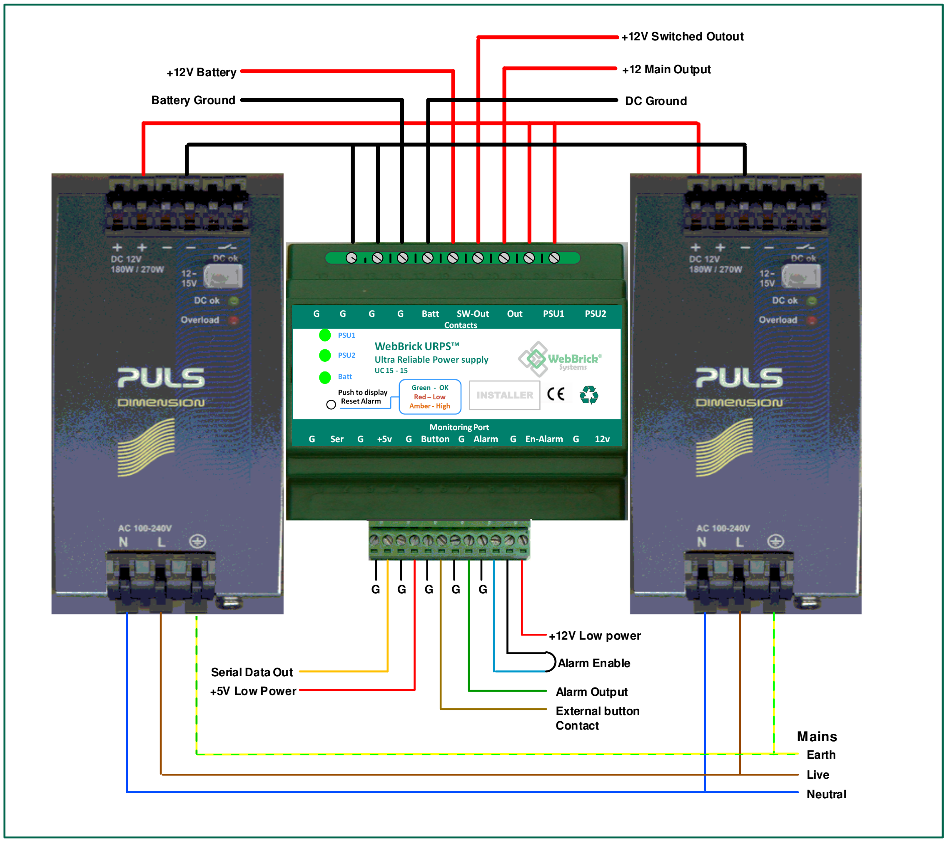
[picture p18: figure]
Ser; Button; Alarm; En-Alarm; Monitoring port; +12V Low power; Alarm Enable; Serial Data Out; +5V Low Power; +12V Switched Outout; +12 Main Output; DC Ground; +12V Battery; Battery Ground; Alarm Output; Mains; Earth; Live; Neutral; External button Contact

Fig.2

If at any time the a red heart-beat flash is seen, the display button should be pressed to show the full status of the inputs to the WebBrick URPS, action should then be taken if necessary to prevent any fault condition from persisting, see the diagnostic chart in table 2
If it is suspected that the mains power supply voltage has drifted outside the normally tight limits required for battery charging it will be necessary to disconnect the battery before readjusting the power supplies. This is necessary because the battery may cause a slight load which effects the voltage measured within the WebBrick URPS. The home automation system connected to the WebBrick URPS should function quite happily providing at least one power supply stays live and provided it is sufficient to supply the total load, see Operation section.

Monitoring via WebBrick Controller or WebBrick Gateway is optional but recommended as the WebBrick URPS will most likely be housed in an area which would normally be out of sight of day to day activities.
Since the battery charging voltage is standardised at 13.8V nominal float-charge voltage, it will increase battery life to ensure the back-up battery chosen for the installation is compatible with this value. Do not attempt to connect any other type or other voltage battery to the system.

### Operation

The normal operation mode of the controller is with the display in power-save mode. In this mode only a visual “heart-beat” indication is given where the centre LED flashes at low duty cycle in order to confirm operation. When all the power inputs are within normal operating limits, the flash is green but should there be an abnormal voltage the LED will flash red, this can include when the battery is charging at high current.

If the battery is called upon to supply power in the event of a mains failure, it will do so down to 10V at which point the controller will switch it off the output to prevent damage to the battery by over– discharge. When the battery has discharged to a voltage of 11.8V (approximately 50% charge), the secondary (Switched) power output is switched off to release load for the more essential services which are required to work until the battery is exhausted. At a discharge voltage of 11V, the audible alarm will sound (if enabled) until either the voltage of the battery recovers above the 11V limit or the display enable button is pressed. Pressing the button cancels the audible part of the alarm until such time as the battery voltage has recovered to above 11V at which time the alarm is re-enabled for the next low voltage warning.

As discussed above, during discharge of the battery there are 3 stages of low voltage battery warning. Load dumping is the first is at 11.8V, then at 11 Volts when the audible alarm sounds there is an amount of charge remaining which should be enough to allow an ordered power-down of the live devices. Below 10 Volts the battery is automatically disconnected so it can no longer discharge. There is very little energy left in the battery at this voltage and little point in trying to use it because to do so would damage the battery’s ability to store charge in the future. The battery can still be charged below 10 volts but only on the trickle regime, regulated internally by the WebBrick URPS, to prevent overloading the mains power supplies. Once the battery charges to above 10V, full charge current is automatically restored so the battery can charge as fast as the mains power supplies will allow although there is a thermal limitation within the WebBrick URPS that will switch in and out of charge to prevent overheating when at full charge current which can be as high as 30A depending on the battery size, connecting cable and its depth of discharge.

If the battery is below 5V it is considered “dead”. It is very unlikely, once a 12V lead acid battery reaches this voltage, that it will be recoverable. In this instance all charge and discharge is inhibited by the WebBrick URPS. The audible alarm will sound in power-save mode and can be cancelled when the button is pressed at which time the display will show a red bottom LED to indicate a dead or missing battery.

Once the PSU adjustment procedure has been completed, the normal under-voltage warning point of the mains PSUs is automatically reduced to 13.4V in order to reduce unnecessary alarms due to noise on the PSU lines.

The WebBrick URPS’s output is fused at 15A so no attempt should be made draw more than this amount of current as a blown fuse will result, see fuse replacement section below. A maximum allowable current rating for the output is equal to one of the mains PSUs, this is an essential element of redundancy in the system. To be in-line with the philosophy of ultra-reliability, failure of any one of the two mains power supplies should not bring the whole system down, there should be enough available from one to keep the system going indefinitely whilst mains power is available.

### WebBrick URPS Technical Specification

Part Number UC15-15

- External connections
- Two mains derived DC 12 to 15V (adjustable for battery float-charging)
- 12V lead-acid battery connection (charge output/discharge input)
- DC output to supply WebBricks and other low voltage utilities including lighting etc.
- Secondary load–dumping output for non-essential services
- Serial output for monitoring of critical voltages and alarm flags
2400 Baud 8N1
- Low power 5V output 50 mA maximum short-circuit protected
- Audible alarm output (0/5V, 25mA when internal alarm disabled, 10mA enabled)
- Internal alarm enable input (0/5V)
- Alarm reset button input, voltage free contact to ground
- Low current 12V output <=1A
- Operating parameters
- 15A maximum current input from each of the mains derived DC inputs
- 15A maximum output to all 12V service loads
- 30A maximum battery charge current (actual maximum charge regulated by heatsink temperature limited by the mains derived DC inputs 15A each supply maximum)
- Battery capacity range: <= 300Ah
- Battery charge voltage adjustment indication 13.6V to 14.0V (13.8V Nominal)
- Load shedding output set to 11.8V (approx 50% capacity)
- Battery under-voltage protection, discharge ends at <10V
- Battery over-voltage protection, charge prevented >14V
- Battery trickle-charge function for deeply discharged batteries (prevents brown-outs in the event of low voltage battery being connected during WebBrick controller operation)
- Battery trickle-charge within voltage >5V,<10V
- Battery charge lock-out, recognises and disables a dead-battery at a voltage <5V

### WebBrick URPS Connections

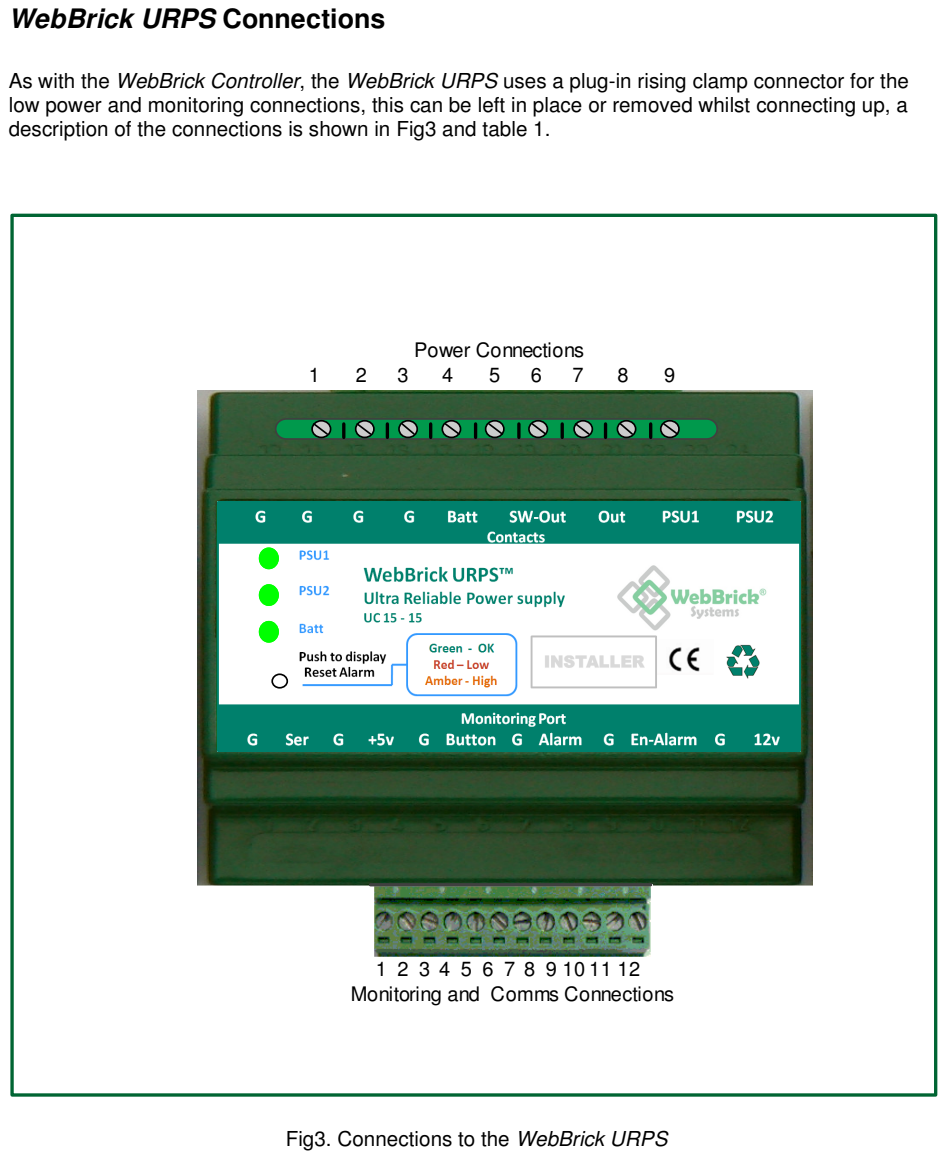
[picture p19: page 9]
Power Connections; PSU1; PSU2; Batt; Green - OK Red - l ow Amber - High; Sw-Out; Out; Ser; Button; Alarm; En-Alarm

As with the WebBrick Controller, the WebBrick URPS uses a plug-in rising clamp connector for the
low power and monitoring connections, this can be left in place or removed whilst connecting up, a
description of the connections is shown in Fig3 and table 1.

Ultra Reliable Power Supply

W ebBr ick URP S

Push to Displ ay
Reset Alarm

Moni tori ng port

Monitoring and Comms Connections

Fig3. Connections to the WebBrick URPS

Power Connector (Top) | Description

1 Ground
2 Ground
3 Ground
4 Ground
5 12V Lead Acid Battery Positive Connection
6 12V Positive Switched Output to WebBricks Etc. 7 12V Positive Output to WebBricks Etc.
8 PSU1 Positive input
9 PSU2 Positive Input
Monitoring Connector (Bottom)

1 Signal Ground, electrically the same connection as power ground
2 Serial Output, monitoring of voltages in serial string, 2400,8 n 1
3 Signal Ground, electrically the same connection as power ground
4 +5V Output, low current, support for low current external equipment,50mA max 5 Signal Ground, electrically the same connection as power ground
6 External Press Button connection (return from button to ground, push to make)
7 Signal Ground, electrically the same connection as power ground
8 External Alarm Positive connection maximum current 10mA at 5V, return to ground 9 Signal Ground, electrically the same connection as power ground
10 Internal Alarm Enable, connect to ground to enable internal audible alarm
11 Signal Ground, electrically the same connection as power ground
12 12V Positive Output to WebBricks Controllers Etc., Electrically connected to pin 8

Table 1.

### WebBrick URPS Operational diagnostic chart

Indication | Meaning | Action to be taken
Centre Green LED Flashing | System running Normally No faults | None
Centre Red LED flashing | Possible Battery or PSU fault | Press display button to enable display and observe LEDs
Audible alarm sounding | Possible Battery or PSU fault | Press display button to enable display and observe LEDs
Top LED showing red | PSU1 low volts | If battery has been discharged recently then wait and check again later should symptom persist, disconnect battery and re-adjust PSU1 voltage
Centre LED showing red | PSU2 low volts | If battery has been discharged recently then wait and check again later should symptom persist, disconnect battery and re-adjust PSU2 voltage
Bottom LED showing red | Battery voltage below 11Volts | If battery has not been discharged recently, check battery off-line and replace if necessary
Bottom LED flashing red | Unrecoverable or disconnected battery | Check and re-make battery connections or replace battery
Top LED showing orange | PSU1 high volts | Readjust PSU1 as necessary
Centre LED showing orange | PSU2 high volts | Readjust PSU2 as necessary
Bottom LED showing orange | Battery high volts* | Readjust the PSU(s) as necessary

Table 2.

*This is a situation which is prevented in practice buy the WebBrick URPS but it could give this indication if the charging voltage is adjusted too high. This indication shows an attempted over-voltage situation exists. The WebBrick URPS will be seen to switch in and out of charge as the battery voltage lags the control from the URPS.
If an alarm condition persists after some corrective action is taken, it will be necessary to check for other faults in the system.

### Fuse Replacement

There are two internal fuses inside the controller, should either of them blow during normal operation, the first thing that will happen is a battery warning will sound if the battery fuse has blown or there will be no output from the WebBrick URPS if the output fuse blows.

Fuse Function | Rating | Colour | Fuse type
Battery | 30A | Green | Farnell 994-3900
Output | 15A | Blue | Farnell 308-341

Table 3

If a fuse blows it will first be necessary to find out why it blew before replacing it. Simply replacing it and re-powering the system may cause damage to the devices it is connected to.

Once the source of the overload has been cured and with the WebBrick URPS powered-down, remove the controller from the DIN rail and flip off the cover by inserting a thin flat blade under the ends of the case and gently easing them out. With the case off, locate the relevant fuse. The fuses can clearly be seen, the 30A battery fuse is to the left of the circuit board and the 15A output fuse is to the right of the circuit board. The ratings are marked on the PCB. Do not replace the fuses with any other rating as this may cause an over-heat situation. The blown fuse can be pulled out of its holder and a new one pressed home.
Care should be exercised when handling the internals of the controller so as not to bend the heatsink mounted component legs.

If the display circuit board becomes dislodged during this operation, simply plug it back in again before replacing the case. To do this make sure press-button is orientated towards the bottom (the signal connector side) and all the 8 pins are aligned with the sockets and push it home.

Replace the cover by lining-up the LEDs and switch with their respective holes and drop the cover back on to the base. Clip the ends of the case over the catches on the base and press the ends in to check they are secured.

### Serial Monitoring, Alarm/Status Interface

The serial interface at pin 2 of the monitoring connector is an RS232 transmit only output which sends the status of the WebBrick URPS approximately every 3 seconds. This data can be sent to a WebBrick Gateway for more sophisticated control and readout. The serial port set-up is 2400,8,N,1.

The data set always consists of 10 Bytes as follows...

Start Byte | PSU1 Volts Hi Byte | PSU1 Volts Lo Byte | PSU2 Volts Hi Byte | PSU2 Volts Lo Byte | Batt Volts Hi Byte | Batt Volts Lo Byte | Output Volts Hi Byte | Output Volts Lo Byte | Alarm/Status Bits
11111111 | 000xxxxx | 000xxxxx | 000xxxxx | 000xxxxx | 000xxxxx | 000xxxxx | 000xxxxx | 000xxxxx | 0xxxxxxx

Table 4

Voltages are expressed as 0 to 15V over 10 bits, split 5 bits to each pair of bytes, high then low. To reassemble the 10 bits of the original data it is necessary to use an algorithm that takes the high 5 bits and shifts them to the right by 3 places within a 2 byte data word. Splitting the data bytes like this allows a simple unequivocal start byte consisting of all 1s to be used.

Using 0 to 1023 to represent 0 to 15V means that each bit count is equivalent to 68.2mV.

The alarm/status Byte is assembled as follows...

MSB Start | Under Voltage Battery | PSU Failure | Battery Connected | Switched Output | Trickle Charge | Discharge Control | Charge Control
Always 0 | 0=OK 1=UV | 0=OK 1=Fail | 0=OK 1=No Batt | 0=ON 1=Off | 0=ON 1=Off | 0=ON 1=Off | 0=ON 1=Off

Table 5

Using a WebBrick URPS to power a WebBrick Gateway Appliance.

The voltage requirements for the WebBrick Gateway appliance are somewhat more critical than the rest of the system i.e. 12V+/- 5%. The WebBrickURPS output voltage can vary between 10V and 13.8V. It is therefore necessary to use a voltage stabiliser the type of which is supplied to run an LCD TV from a caravan supply these typically take any voltage from 10 to 28V and convert it into a tightly regulated 12V supply.

Update 30/04/08, applies to firmware version 4-70x, see back of case

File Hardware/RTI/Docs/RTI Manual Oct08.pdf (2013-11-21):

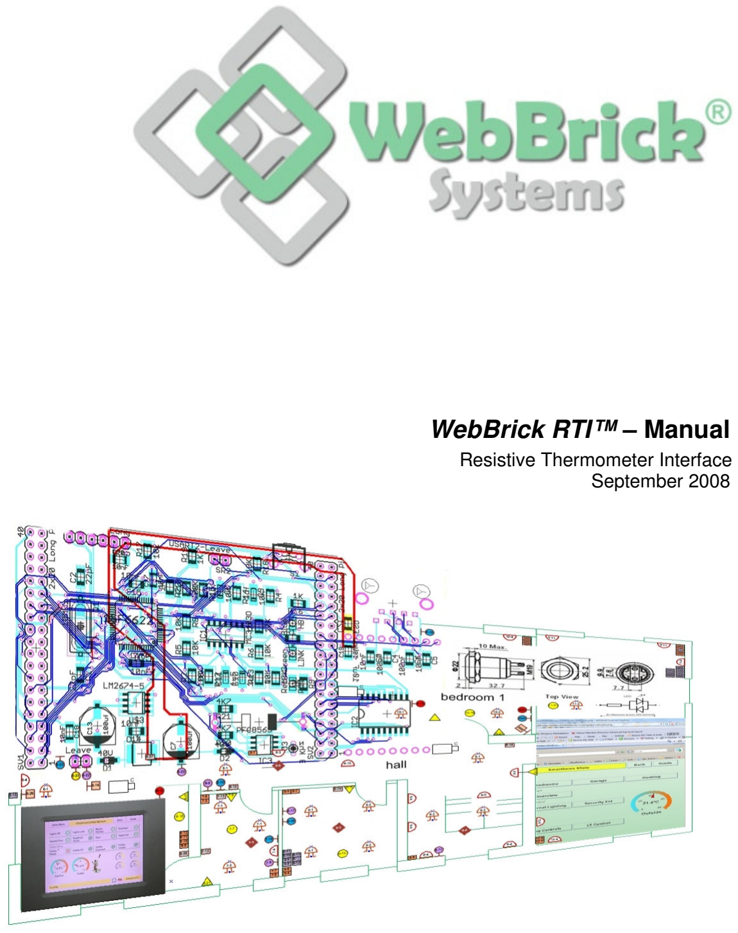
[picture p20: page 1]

### WebBrick RTI™ – Manual

### Resistive Thermometer Interface September 2008

### Features

| Allows A WebBrick Controller to connect to a resistive thermometer
| Reads platinum resistance devices between -50° to 200°C
| Linearizes and offsets the zero to give 0 to 5V signal
| Pulsed sensor excitation to keep sensor self-heating to a minimum
| Low quiescent current <8mA at 12V
| 75mm wide DIN rail housing with rising clamp connectors

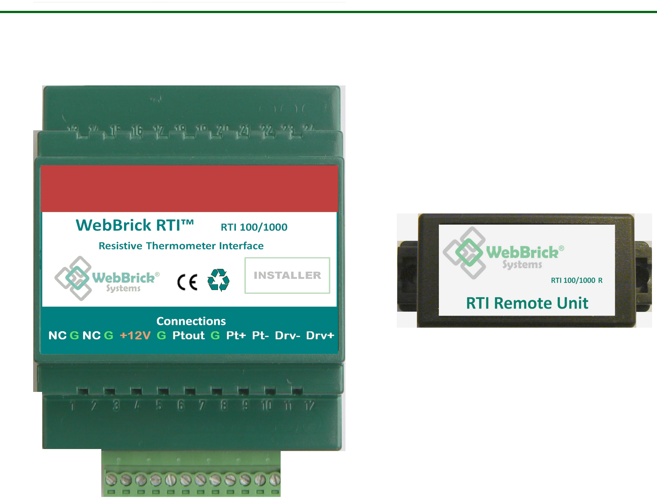
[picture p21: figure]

Fig1. Resistive Thermometer Interface including Remote Unit

### Background

Utilities like solar heating and heat recovery systems may be supplied with sensors built into them, usually a platinum resistance device of either 100 ohms or 1000 ohms characteristic resistance.
The RTI is specially designed to bridge the gap between commercially supplied equipment and the WebBrick automation system. Anywhere where a temperature beyond the normal range for the WebBrick Temperature sensor needs to be sensed, a Pt1000 sensor can be used in combination with the WebBrick RTI.

### General Description

The WebBrick RTI has two parts, the amplifier and the remote unit. The amplifier is usually situated near to the WebBrick it is signalling to and the remote unit is situated as close to the sensor as possible. The amplifier’s range is offset to read temperatures below zero and to linearize the readings from the sensor. The reason for the remote unit is to keep the error due to resistance in long cable runs to a minimum this is particularly important with 100 Ohm sensors. The amplifier unit is usually placed close to the WebBrick that it is signalling to the connections are shown in Fig 2.

### Installation

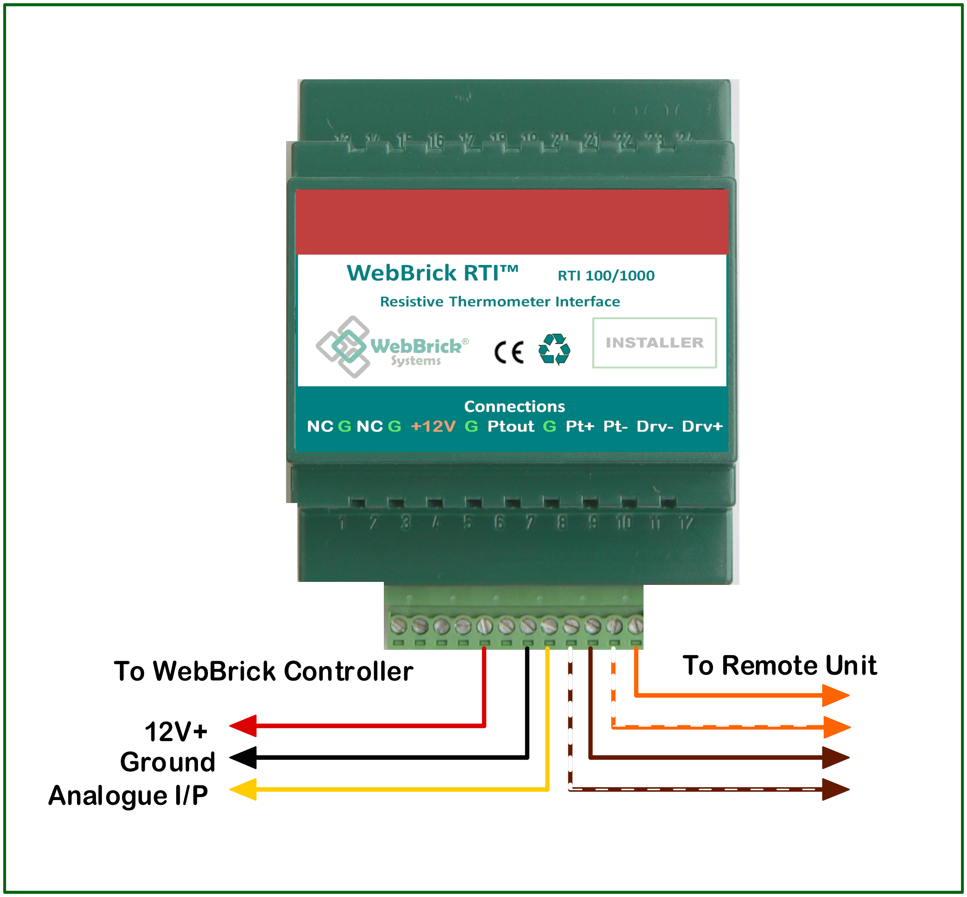
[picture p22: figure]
To WebBrick Controller; To Remote Unit; 12V+ Ground Analogue I/P

Fig 2. Resistive Thermometer Interface amplifier unit, connections

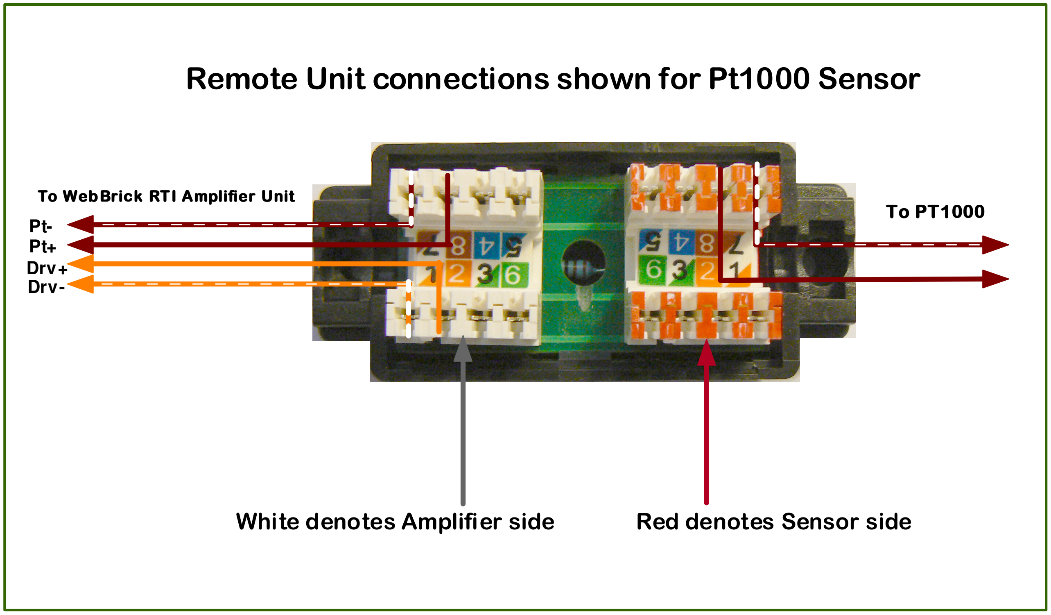
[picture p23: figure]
White denotes Amplifier side; Red denotes Sensor side; Pt- Pt+ Drv+ Drv-; To Web Brick RT I Amplifier Unit

## Remote Unit connections shown for Pt1000 Sensor

Fig 2. Remote Unit, (cover removed)

Fig 2. shows the connections at the remote unit for Pt1000, in the case of operation with Pt100 sensor, the green and green/white connections are used at the amplifier side of the remote unit, connections at the amplifier end are the same. It is important to connect the remote unit the correct way round because the internal circuit is not symmetrical, note red and white pinch-down blocks. The sensor can be connected to any pair of colour and striped punch-downs at the red end.
With the remote unit installed close to the sensor, the length of the cable to amplifier unit can be up to the maximum recommended 100m.

### WebBrick RTI Technical Specification

Part Number RTI100/1000

External connections
- DC 12V
- 4 wire connection to remote sensor
- 0 to 5V output for compatibility with Analogue input for WebBrick Controller
- Ground (4 separate connections)

Operating parameters

- -50° to 200°C measurement range
- 0 to 5 volt output equates to -50°C to 200°C or 0% to 100% analogue input reading.
- Max error +/- 8°C across the range
- Pt100 or Pt1000 sensor
- 100m maximum cable length between amplifier unit and remote unit (Cat5e)
- 8mA maximum current draw at 12V
- 10 to 15V DC Supply
- 100m maximum cable length to remote unit

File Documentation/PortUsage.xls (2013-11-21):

 |  | Usage |  | PIC PIN | Hdr
 | PORT A
 | 0 | Analog 0 | I | 24 | SV1.9
 | 1 | Analog 1 | I | 23 | SV1.10
 | 2 | Analog 2 | I | 22 | SV1.11
 | 3 | Analog 3 | I | 21 | SV1.12
 | 4 |  |  | 28
 | 5 | Mon 0 | I | 27 | SV1.13
 | 6 | XTAL | * | 40
 | 7 | XTAL | * | 39
 | PORT B
 | 0 | Dig In 0 | I | 48 | SV1.1
 | 1 | Dig In 1 | I | 47 | SV1.2
 | 2 | Dig In 2 | I | 46 | SV1.3
 | 3 | Dig In 3 | I | 45 | SV1.4
 | 4 | Dig In 4 | I | 44 | SV1.5
 | 5 | Dig In 5 | I | 43 | SV1.6 | LV ICSP
 | 6 | Dig In 6 | I | 42 | SV1.7 | ICSP
 | 7 | Dig In 7 | I | 37 | SV1.8 | ICSP
 | PORT C
* | 0 |  |  | 30 | SV1.24
 | 1 | PWM2 | O | 29 | SV2.30
 | 2 | PWM1 | O | 33 | SV2.29
* | 3 | SCL1 | * | 34 | SV1.22 | I2C/SPI
* | 4 | SDA1 | * | 35 | SV1.20 | I2C/SPI
* | 5 |  | * | 36 | SV1.18 | SPI
 | 6 | TX1 | O | 31 |  | UART | Siteplayer
 | 7 | RX1 | I | 32 |  | UART | Siteplayer
 | PORT D |  |  |  |  | O/C
 | 0 | Dig Out 0 | O | 58 | SV2.1 | SV2.9
 | 1 | Dig Out 1 | O | 55 | SV2.2 | SV2.10
 | 2 | Dig Out 2 | O | 54 | SV2.3 | SV2.11
 | 3 | Dig Out 3 | O | 53 | SV2.4 | SV2.12
 | 4 | Dig Out 4 | O | 52 | SV2.5 | SV2.13
 | 5 | Dig Out 5 | O | 51 | SV2.6 | SV2.14
 | 6 | Dig Out 6 | O | 50 | SV2.7 | SV2.15
 | 7 | Dig Out 7 | O | 49 | SV2.8 | SV2.16
 | PORT E
 | 0 | Dig Out 8 | O | 2 | SV1.25 | Option 1 Mimic
 | 1 | Dig Out 9 | O | 1 | SV1.26
 | 2 | Dig Out 10 | O | 64 | SV1.27
 | 3 | Dig Out 11 | O | 63 | SV1.28
 | 4 | Dig Out 12 | O | 32 | SV1.29
 | 5 | Dig Out 13 | O | 31 | SV1.30
 | 6 | Dig Out 14 | O | 30 | SV1.31
 | 7 | Dig Out 15 | O | 59 | SV1.32
 | PORT F
 | 0 | Mon 1 | I | 18 | SV1.14
 | 1 | Mon 2 | I | 17 | SV1.15
 | 2 | Mon 3 | I | 16 | SV1.16
 | 3 | OneWire | IO | 15 | SV2.35
* | 4 | 1WireDrive | O | 14
 | 5 | Hbeat | O | 13 | SV2.28
 | 6 | Rotary | I | 12 | SV2.33
 | 7 | Rorary | I | 11 | SV2.34
 | PORT G
 | 0 | PWM 3 | O | 3 | SV2.31
* | 1 | TX2 | O | 4 | SV2.38
* | 2 | RX2 | I | 5 | SV2.37
 | 3 | PWM 4 | O | 6 | SV2.32
 | 4 | Freset | I | 8
 | 5 | MCLR | * | 7

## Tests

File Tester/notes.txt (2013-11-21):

The Temperaure project was a start on a simple temperature sensor tester.
The OSTester is a more generic tester

Notes:

RB7 ICSP PGD
RB6 ICSP PGC
RB5 Serial Tx
RB4 Digital Switch In
RB3 Digital Out
RB2 Serial Rx
RB1 1 Wire temp sensors.
RB0 CCP output, reserve for analogue output

RA7 LED 1
RA6 LED 2
RA5 MCLR - ICSP
RA4 LED 3
RA3 LED 4
RA2 LED 5
RA1 LED 6
RA0 Analogue input.

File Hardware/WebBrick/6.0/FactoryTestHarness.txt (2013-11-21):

Cabling.
========

The factory test harness connects WebBrick  outputs to WebBrick inouts so that most 
of the inputs/outputs can be tested automatically.

As there are a large number of outputs there are two plugs (Plug A & Plug B) that connect 
to the digital inputs, one from the Mimics and one from the digital outputs/open collector outputs.

i) Connect Mimics 1-8 to Digital In 1-8 (Plug A)

ii) Connect O/C output 1-4 to Digital input 1-4 Plug B. Also connect O/C 1-4 to 5V using a 
Pullup resistor of between 1K and 10K.

iii)Connect Digital outputs 5-8 to digital input 5-8 Plug B.

iv) Connect Analogue outputs 1-4 to Analogue input 1-4 using a 1K resistor and also
connect analogue input 1-4 to ground using a 1K resistor. This is to divide the analogue
output by 2 as ii is 0-10V and the input is 0-5V.

v) Connect all relay NO contacts to 5V

vi) Connect all relay NO contacts to 0V

vii) Connect relay C(ommon) contacts to the monitor inputs. 5A to monitor 1, 5B to monitor 2,
 6A to monitor 3 & 6B to monitor 3.

viii) connect 12v supply to top right connector.

To Come:
========
Using the temperature sensors to test the mains triacs. By using small 15W bulbs and clipping a 
temp sensor to each one. Requires 5 temperature sensors so we can also detect bacjground temperature.

Notes:
======
oV and 5V are available on the middle bottom connector, as part fo the 1 wire bus.

Not tested as yet.
Rotary encoder (A&B top right.)

Python Test Code.
=================

Digitals

a) This first of all sets all digital input trigger actions to None and the fade rate to 1 so the
analogue inputs shift faster.

b) Then sets all digital outputs to off and reads the inputs to detect whether we are testing Mimics or 
Open Collector outputs (these switch the ground rail, hence are pulled up to 5V).

c) Then for each output sets output high and verifies that only this input has gone high.

d) Sets all outputs high and for each output sets it low and verifies that only one input low.

Analogues

a) Set all analogues to 0%

b) The test then sets all the outputs not on test to a sequence of levels. And at each level sets the 
output under test to a set of levels. At each point it verifies that all the inputs are at the expected
levels. This verifies that we have no interaction between each level. At present the steps are 20%.

Monitors/Relays.
a) Set all outputs to off

b) Switch each relay and verify all the monitor inputs are as expected.

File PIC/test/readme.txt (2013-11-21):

Files in this fiolder are intended to be used to regression test a webbrick when firmware 
is changed. 

The main TestAll file is run against a webbrick with minimal connections.
The TestFactory is run against a webbick on a factory test rig that cross connects some inputs and has some 
hardware connected. This later test suite is intended to test the hardware for full operation and not to test all
firmware paths.

The test code uses files from the webbrick python API, these are accessed from ../../python/api.

Lawrence.

30 Mar 2007 Tests thaat could be added

Boundary conditions. Attempt to configure out of range index for all types of channel.

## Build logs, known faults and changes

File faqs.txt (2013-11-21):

1) How do I build this
You will need a copy of the Fored Wizc professional RAD tool www.fored.co.uk. There are a number of patches
to the elements within the Wizc codebase. Webbrick firmware was built with V14.01. I cannot provide you with this
but there is a patch file that needs applying against the wizc directory as there where a couple of bugs and some
changes made.

2)

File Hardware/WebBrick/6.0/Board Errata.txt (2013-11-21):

WebBrick 6-64 tasks
-------------------

Checklist
=========

a) Check that VSS, V- and GND are all the same net.

b) Check that all pins on Digital and Analogue buses are connected

c) Check that V+ goes to Quad Op Amp

Tasks
=====

16 May 2006
Issues affecting Revision 3 hardware 

i) Use taller male connector, at least 3mm.
ii)Adjust screw hole positions, slightly too close.
v) Ensure parts list updated before next manufaacture, lower profile replays.

Future enhancements
=================

i) Change RJ45 socket so we can access POE power connections.

HISTORICAL
===========
Pre May 2006

xa) Change to 1 relay

b) Create space for 3mm mains separation

xc) Remember heat sinks for triacs

d) Add holes for light pipes

xe) Change regulated side cap to 100uf

f) Try to lose 0.1" from length of board

IO Board
========

 --- Change to 4 layer ---

xa) 1 wire pull up

?b) provision for mimics (i.e.) DIL switch

xc) ROT pull-ups

xd) change to 3.5mm pitch

xe) 12V *to* WebBrick 6-64

IO Board Remedial
=================

xROT pull-ups are in fact pull down ! -- Needs changing a documentation!

xOptoTriacs are too close together

Use lower profile relays

ABL Heatsinks
=============

john.hoccom@ablcomponents.co.uk

100 PPC50 black anodised @ 1.50

WebBrick 6-64 remedial tasks
============================

a) AVDD and AVSS (decouple)

b) change element to use GND instead of AVSS to solve confusion

c) Decouple at input and programming connector

xd) Decouple SP with 10NF

e) Check what signals go to the IO board -- I2C and second UART.

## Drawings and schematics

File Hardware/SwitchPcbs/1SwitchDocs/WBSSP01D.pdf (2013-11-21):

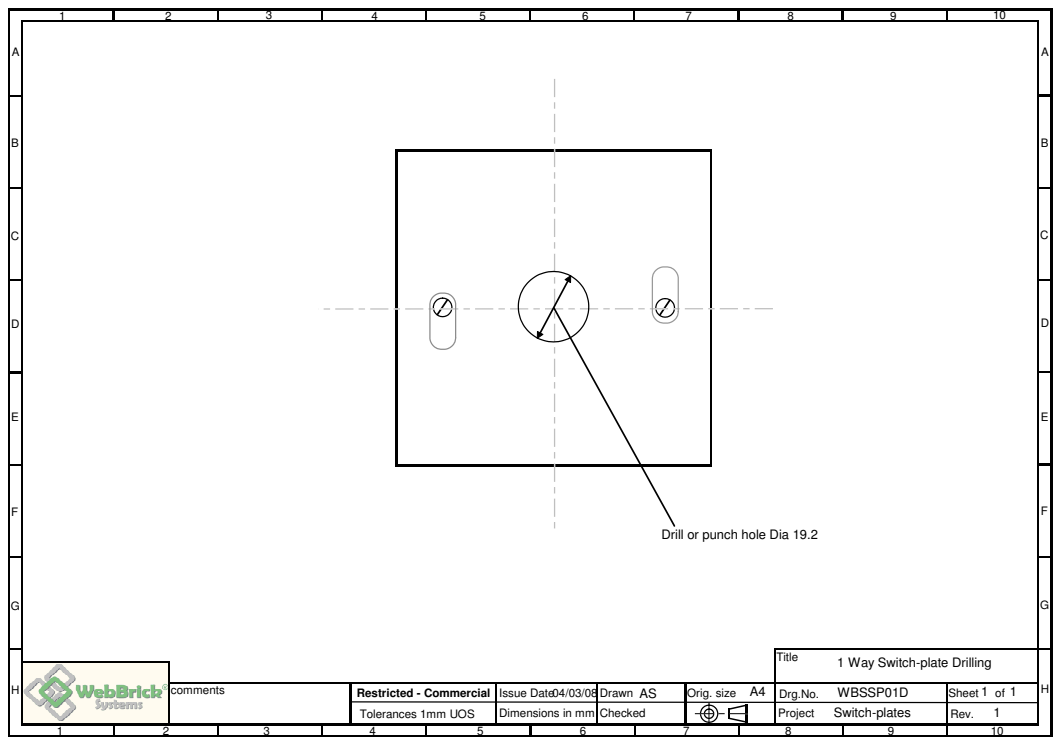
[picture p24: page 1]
Title

Drill or punch hole Dia 19.2

1 Way Switch-plate Drilling

comments | Restricted - Commercial | Issue Date 04/03/08 | Drawn AS | Orig. size A4 | Drg.No. WBSSP01D | Sheet 1 of 1

Tolerances 1mm UOS | Dimensions in mm | Checked | | | | | Project Switch-plates | Rev. 1

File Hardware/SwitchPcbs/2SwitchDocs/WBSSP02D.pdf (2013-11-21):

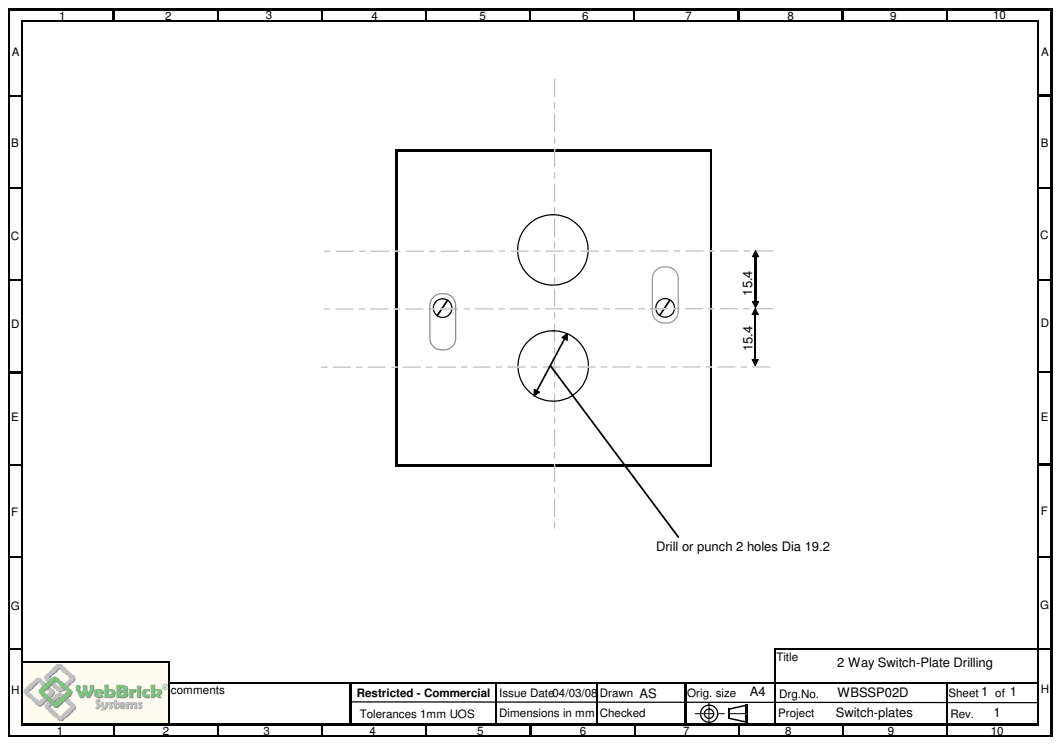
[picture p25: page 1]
Title

Drill or punch 2 holes Dia 19.2

2 Way Switch-Plate Drilling

comments | Restricted - Commercial | Issue Date 04/03/08 | Drawn AS | Orig. size A4 | Drg.No. WBSSP02D | Sheet 1 of 1

Tolerances 1mm UOS | Dimensions in mm | Checked | | | | | Project Switch-plates | Rev. 1

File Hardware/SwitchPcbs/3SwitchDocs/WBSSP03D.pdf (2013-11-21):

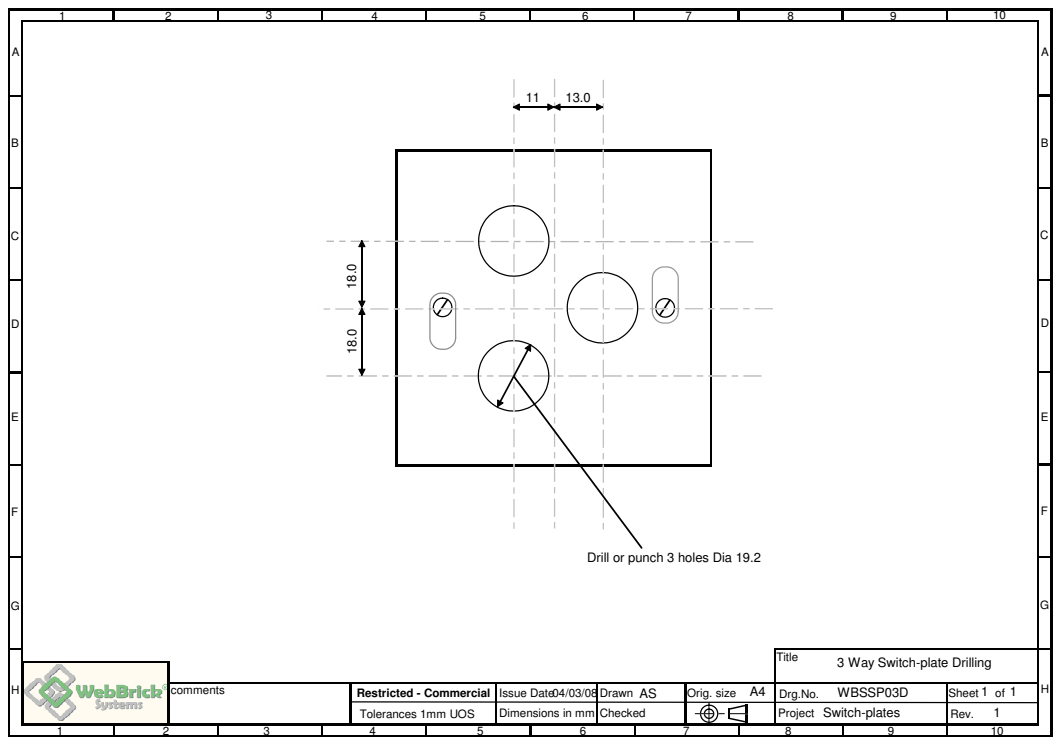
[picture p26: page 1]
Title

Drill or punch 3 holes Dia 19.2

3 Way Switch-plate Drilling

comments | Restricted - Commercial | Issue Date 04/03/08 | Drawn AS | Orig. size A4 | Drg.No. WBSSP03D | Sheet 1 of 1

Tolerances 1mm UOS | Dimensions in mm | Checked | | | | | Project Switch-plates | Rev. 1

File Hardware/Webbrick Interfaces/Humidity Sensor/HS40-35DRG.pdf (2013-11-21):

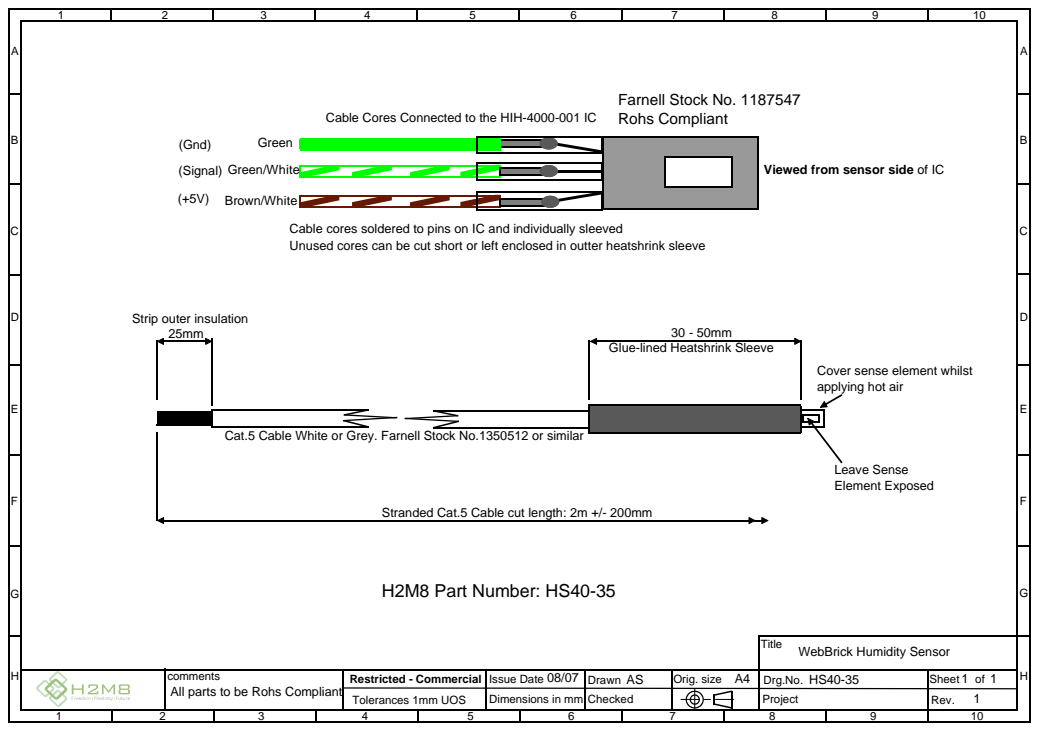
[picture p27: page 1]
Leave Sense Element Exposed; H2M8 Part Number: HS40-35; Brown/White; Green/White; Green; (Signal); (Gnd)

Farnell Stock No. 1187547
Rohs Compliant

Cable Cores Connected to the HIH-4000-001 IC

Viewed from sensor side of IC

Cable cores soldered to pins on IC and individually sleeved
Unused cores can be cut short or left enclosed in outter heatshrink sleeve

Strip outer insulation

Glue-lined Heatshrink Sleeve

Cover sense element whilst
applying hot air

Cat.5 Cable White or Grey. Farnell Stock No.1350512 or similar

Stranded Cat.5 Cable cut length: 2m +/- 200mm

Title WebBrick Humidity Sensor

comments All parts to be Rohs Compliant | Restricted - Commercial | Issue Date 08/07 | Drawn AS | Orig. size A4 | HS40-35 Drg.No. | 1 1 Sheet of

Tolerances 1mm UOS | Dimensions in mm | Checked | | | | | Project | Rev. 1

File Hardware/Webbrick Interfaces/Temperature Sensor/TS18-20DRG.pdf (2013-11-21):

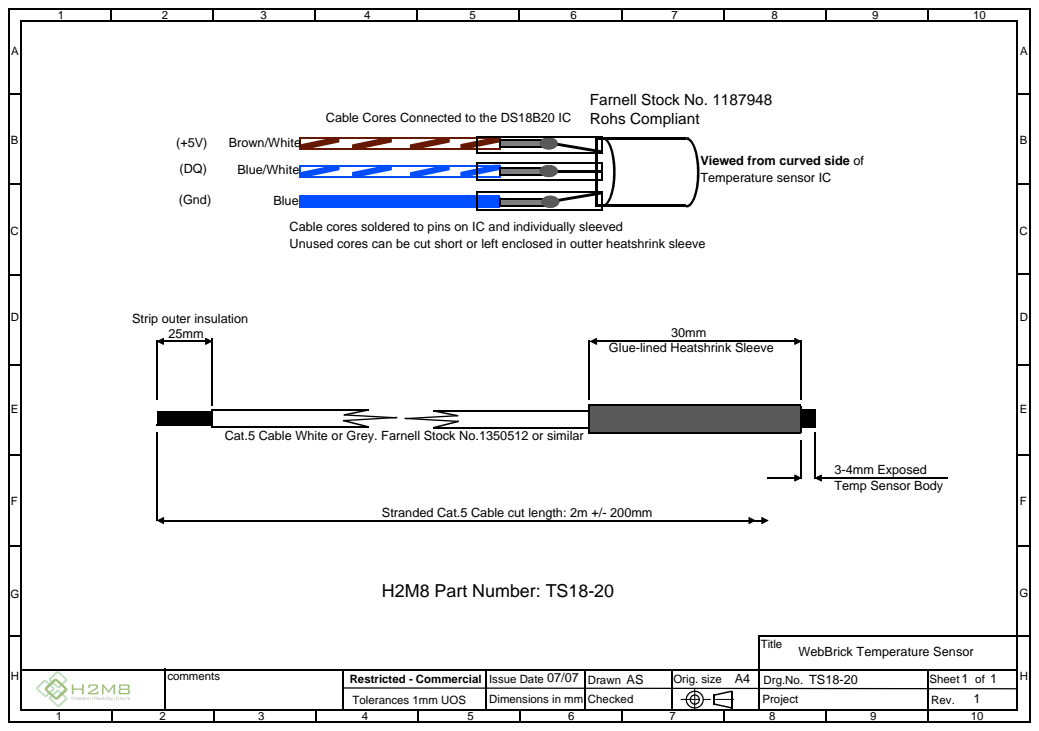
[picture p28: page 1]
H2M8 Part Number: TS18-20; Brown/White; Blue/White; (Gnd)

Farnell Stock No. 1187948
Rohs Compliant

Cable Cores Connected to the DS18B20 IC

Viewed from curved side of
Temperature sensor IC

Blue
Cable cores soldered to pins on IC and individually sleeved
Unused cores can be cut short or left enclosed in outter heatshrink sleeve

Strip outer insulation

Glue-lined Heatshrink Sleeve

Cat.5 Cable White or Grey. Farnell Stock No.1350512 or similar

3-4mm Exposed
Temp Sensor Body

Stranded Cat.5 Cable cut length: 2m +/- 200mm

Title WebBrick Temperature Sensor

comments | Restricted - Commercial | Issue Date 07/07 | Drawn AS | Orig. size A4 | TS18-20 Drg.No. | 1 1 Sheet of

Tolerances 1mm UOS | Dimensions in mm | Checked | | | | | Project | Rev. 1

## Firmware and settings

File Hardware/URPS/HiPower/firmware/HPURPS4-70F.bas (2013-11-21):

Define CONF_WORD = 0x330c

'HP-URPS Controller Firmware
Dim x As Byte
Dim y As Byte
Dim i As Byte
Dim tim As Word
Dim batvolts As Word
Dim psu1volts As Word
Dim psu2volts As Word
Dim opvolts As Word
Dim batov As Bit
Dim batuv As Bit
Dim nobat As Bit
Dim charge As Bit
Dim discharge As Bit
Dim trickle As Bit
Dim top_green As Bit
Dim top_red As Bit
Dim ctr_green As Bit
Dim ctr_red As Bit
Dim bot_green As Bit
Dim bot_red As Bit
Dim leds_blanked As Bit
Dim palarm1 As Bit  'psu alarm
Dim palarm2 As Bit  'psu alarm
Dim balarm As Bit  'Battery Alarm
Dim alarm_on As Bit
Dim al As Bit
Dim alarm_byte As Byte
Dim bov As Bit
Dim out_ctrl As Bit
Dim p1v As Word
Dim p1vl As Byte
Dim p2v As Word
Dim p2vl As Byte
Dim ov As Word
Dim ovl As Byte
Dim bv As Word
Dim bvl As Byte
Dim uv_psuv As Word
Dim opalarm As Bit
Dim opv_ok As Bit
Dim volts As Word
Dim ignore As Bit
Dim ae As Byte

'Voltage Constants x 68.33
Const ov_psu = 963  '14.1
Const uv_psuadj = 950  '13.9
Const uv_psurun = 915  '13.4
Const batt_ov = 965  '14.0V
Const sw_out_off = 806  '11.8V
Const sw_out_on = 854  '12.5V
Const warn_batt = 750  '11.0V
Const uv_batt = 683  '10.0V
Const dead_batt = 341  '5.0V

ADCON0 = %11011000
ADCON1 = %01000000
OSCCON = %01000001  'Internal Osc 1MHz No external signal ***Ensure compiler set to 1MHz
ANSEL = %10001001
ANSELH = %00001000
TMR0 = 0
OPTION_REG = %10001110
Define ADC_CLOCK = 3
Define SEROUT_DELAYUS = 2000
'Define ADC_SAMPLEUS = 250

ASM:        clrwdt

'Define ports
TRISA.0 = 1  'Battery Voltage
TRISA.1 = 1  'ADC Reference input
TRISA.2 = 0  'Switched output control
TRISA.3 = 1  'Push button
TRISA.4 = 1  'PSU1 Voltage
TRISA.5 = 0  'LED1

TRISB.4 = 0  'LED3
TRISB.5 = 1  'Output voltage
TRISB.6 = 0  'LED2
TRISB.7 = 0  'Serial out

TRISC.0 = 0  'LED3
TRISC.1 = 0  'Buzzer control
TRISC.2 = 0  'LED2
TRISC.3 = 1  'PSU2 Voltage
TRISC.4 = 0  'LED1
TRISC.5 = 0  'Under-voltage control
TRISC.6 = 0  'Trickle charge control
TRISC.7 = 0  'Over-voltage switch control

'Initialise ports
PORTA.5 = 0
PORTA.5 = 0
PORTB.4 = 0
PORTB.6 = 0
PORTB.7 = 0
PORTC.0 = 0
PORTC.1 = 0
PORTC.2 = 0
PORTC.4 = 0
PORTC.5 = 0
PORTC.6 = 0
PORTC.7 = 0

'Initialise variables
charge = False
discharge = False
top_green = False
top_red = False
ctr_green = False
ctr_red = False
bot_green = False
bot_red = False
al = False
alarm_on = True
bov = False
trickle = True
out_ctrl = True
tim = 1
balarm = False
palarm1 = False
palarm2 = False
x = 0
y = 0
ignore = False
ae = 0

Gosub led_test
'__________________________________________________________


'**********************************************************
'__________________________________________________________
start:  'START OF MAIN LOOP

Gosub control
ASM:        clrwdt
'flash heart-beat LED every 64 times round loop
If leds_blanked = True And al = False And x = 0 Then
	PORTB.6 = 1
	WaitMs 10
	PORTB.6 = 0
Else
	If leds_blanked = True And al = True And x = 0 Then
		PORTC.2 = 1
		WaitMs 10
		PORTC.2 = 0
	Endif
Endif

'Create Serial data bytes and send them every 64 times around the loop
If x = 0 Then
	p1v = psu1volts * 8
	p1vl = p1v.LB / 8

	p2v = psu2volts * 8
	p2vl = p2v.LB / 8

	bv = batvolts * 8
	bvl = bv.LB / 8

	ov = opvolts * 8
	ovl = ov.LB / 8

'Start byte 0xFF
'all data words shifted so high and low bytes each contain 5 bits both right justified
	Serout PORTB.7, 2400, 0xff, p1v.HB, p1vl, p2v.HB, p2vl, bv.HB, bvl, ov.HB, ovl, alarm_byte

Endif

If x < 63 Then
	x = x + 1
Else
	x = 0
Endif

	Gosub time_on
ASM:        clrwdt

volts = 0
	Adcin 3, psu2volts
	volts = volts + psu2volts
	WaitMs 1
	Adcin 3, psu2volts
	volts = volts + psu2volts
	WaitMs 1
	Adcin 3, psu2volts
	volts = volts + psu2volts
	WaitMs 1
	Adcin 3, psu2volts
	volts = volts + psu2volts
	WaitMs 1
	Adcin 3, psu2volts
	volts = volts + psu2volts
	WaitMs 1
	Adcin 3, psu2volts
	volts = volts + psu2volts
	WaitMs 1
	Adcin 3, psu2volts
	volts = volts + psu2volts
	WaitMs 1
	Adcin 3, psu2volts
	volts = volts + psu2volts
	psu2volts = volts / 8  'Take 8 readings and average them

volts = 0
	Adcin 7, psu1volts
	volts = volts + psu1volts
	WaitMs 1
	Adcin 7, psu1volts
	volts = volts + psu1volts
	WaitMs 1
	Adcin 7, psu1volts
	volts = volts + psu1volts
	WaitMs 1
	Adcin 7, psu1volts
	volts = volts + psu1volts
	WaitMs 1
	Adcin 7, psu1volts
	volts = volts + psu1volts
	WaitMs 1
	Adcin 7, psu1volts
	volts = volts + psu1volts
	WaitMs 1
	Adcin 7, psu1volts
	volts = volts + psu1volts
	WaitMs 1
	Adcin 7, psu1volts
	volts = volts + psu1volts
	psu1volts = volts / 8  'Take 8 readings and average them

	Adcin 2, opvolts

ASM:        clrwdt
'PSU adjustment routine
If PORTA.3 = 0 Then

	Gosub time_on

	uv_psuv = uv_psuadj

	adjustpsus:
volts = 0
	Adcin 3, psu2volts
	volts = volts + psu2volts
	WaitMs 1
	Adcin 3, psu2volts
	volts = volts + psu2volts
	WaitMs 1
	Adcin 3, psu2volts
	volts = volts + psu2volts
	WaitMs 1
	Adcin 3, psu2volts
	volts = volts + psu2volts
	WaitMs 1
	Adcin 3, psu2volts
	volts = volts + psu2volts
	WaitMs 1
	Adcin 3, psu2volts
	volts = volts + psu2volts
	WaitMs 1
	Adcin 3, psu2volts
	volts = volts + psu2volts
	WaitMs 1
	Adcin 3, psu2volts
	volts = volts + psu2volts
	psu2volts = volts / 8  'Take 8 readings and average them

volts = 0
	Adcin 7, psu1volts
	volts = volts + psu1volts
	WaitMs 1
	Adcin 7, psu1volts
	volts = volts + psu1volts
	WaitMs 1
	Adcin 7, psu1volts
	volts = volts + psu1volts
	WaitMs 1
	Adcin 7, psu1volts
	volts = volts + psu1volts
	WaitMs 1
	Adcin 7, psu1volts
	volts = volts + psu1volts
	WaitMs 1
	Adcin 7, psu1volts
	volts = volts + psu1volts
	WaitMs 1
	Adcin 7, psu1volts
	volts = volts + psu1volts
	WaitMs 1
	Adcin 7, psu1volts
	volts = volts + psu1volts
	psu1volts = volts / 8  'Take 8 readings and average them
	If psu1volts > ov_psu Then  'Over Voltage
		top_green = True
		top_red = True
	Endif
	If psu1volts < ov_psu And psu1volts > uv_psuv Then  'Voltage OK
		top_green = True
		top_red = False
	Endif
	If psu1volts < uv_psuv Then  'Under voltage
		top_green = False
		top_red = True
	Endif
	If psu2volts > ov_psu Then  'Over Voltage
		ctr_green = True
		ctr_red = True
	Endif
	If psu2volts < ov_psu And psu2volts > uv_psuv Then  'Voltage OK
		ctr_green = True
		ctr_red = False
	Endif
	If psu2volts < uv_psuv Then  'Under voltage
		ctr_green = False
		ctr_red = True
	Endif
	Gosub display
ASM:        clrwdt
	If PORTA.3 = 0 Then
		Goto adjustpsus
	Else
		uv_psuv = uv_psurun
		WaitMs 50
	Endif
Endif
'------------------------------------------
'Mains PSU monitor  - 1
	If psu1volts > ov_psu Then  'Over Voltage
		top_green = True
		top_red = True
	Endif

	If psu1volts < ov_psu And psu1volts > uv_psuv Then  'Voltage OK
		top_green = True
		top_red = False
	If palarm1 = True Then alarm_on = True
		palarm1 = False
	Endif

	If psu1volts < uv_psuv Then  'Under voltage
		top_green = False
		top_red = True
		palarm1 = True
	Endif
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

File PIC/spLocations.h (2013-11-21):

//
// Define the locations in siteplayer memory to store values
// from the PIC
//
// LPK Added upper area.
//
// We want to move any others we find into here as well
//
#ifndef _SPLOCATIONS_H
#define _SPLOCATIONS_H	1

#include ".\SitePlayer\WB55Lib.h"

//
// Locations within site player and EEPROM data within PIC chip
//
// We use lowe addresses for dyanmic stuff as shorter address when
// sending to siteplayer.
//
#define UDPLoc udpstring
#define LoginStateLoc loginstate
#define OperStateLoc sptod
#define DInLoc digin
#define CmdErrorLoc cmderror
//#define DIn2Loc digin2
#define DOutStsLoc spdigoutstatus
#define MimicStsLoc (spdigoutstatus+1)
#define OneWStsLoc onewsts

// Clock values, not all yet implemented.
#define TimeYearLoc spyear
#define TimeMonthLoc spmonth
#define TimeDateLoc spdate
#define TimeDayLoc spday
#define TimeHourLoc sphour
#define TimeMinuteLoc spminute
#define TimeSecondLoc spsecond

// Base of current temperatures
#define TempValBase sptemp0
#define TempCount 5
#define TempValSize (sptemp1-sptemp0)
#define TempValOs 0
#define TempLowOs (sptemp0low-sptemp0)
#define TempHiOs (sptemp0hi-sptemp0)

// 1 bytes for value
#define AnOutBLoc anout0value
#define AnOutEntryCount 4

// 1 bytes for value
#define AnInValBase anin0value
#define AnInEntryCount 4
#define AnInValSize (anin1value-anin0value)
#define AnInValOs 0
#define AnInValLowOs (spanin0low-anin0value)
#define AnInValHiOs (spanin0hi-anin0value)

#define PersistStart nodename

#define NNameLoc nodename
#define NNameLen (nodenumber-nodename)
#define NNumLoc nodenumber

// If bit 7 is set then invalid data so reset to factory values
#define InfraRedLoc infrared
#define InfraRedAdr(b) (b & 0x1F)
#define InfraRedTx(b) ( (b&0x20) != 0 )
#define InfraRedRx(b) ( (b&0x40) != 0 )
#define SetInfraRedTx(b) (b|0x20)
#define SetInfraRedRx(b) (b|0x40)
#define ClearInfraRedTx(b) (b&0xDF)
#define ClearInfraRedRx(b) (b&0xBF)
#define SetInfraRedAdr(b,adr) ( (b & 0xE0) | adr )

#define RotStepLoc rot0step

#define FadeRateLoc faderate

#define SerialModeLoc serialflags
#define SM_Rs232Data     0x02
#define SM_Rs485Data     0x04
#define SM_Dmx           0x03
#define MakeSerialConfig(m,b)    ( ( m<<4) | b )
#define SerialMode(b)    (b>>4)
#define SerialSpeed(b)   (b&0x0F)

// 
//#define isSerialModeRs485(b) ( (b & SerialModeBit) != 0 )
//#define isSerialModeRs485(b) ( (b & SerialModeBit) != 0 )
//#define isSerialModeRs232(b) ( (b & SerialModeBit) == 0 )

#define MimicFlagsLoc mimicflags
#define MimicVoltsBit 0x80
#define isMimicLowVolts(b) ( (b & MimicVoltsBit) == 0 )
#define isMimicHighVolts(b) ( (b & MimicVoltsBit) != 0 )

// control byte 1
// control byte 2
// control byte 3
// control byte 4
// control byte 5
//
//  Digital Input Command Structure
//
//  FIRST byte
//	Bits 0-3 - Action
//	Bits 4-5 - Dwell Choice
//	Bits 6-7 - UDP or Remote
// 
// Webbrick 6.5 encoding
// bit 7, set to send UDP
// bits 5-6 main group
// command group
//  0(0x20) - Group 1
//  1 (0x40) - 
//  2 (0x60) - 
//  3 (0x00) - Dwell Group
//
// Dwell group
// bits 0-2 Is a dwell number
// bits 3-4 dwell type
//  0 (0x00) - Dwell On, ignored if channel already on
//  1 (0x08) - Dwell Off, always switches off after dwell, NOP if already off
//  2 (0x10) - Dwell Cancel, on for dwell if off, otherwise off now
//  3 (0x18) - Dwell Always, channel on and off after dwell. override existing on
//
// Group 1
// bits 0-4 encode existing simple commands
//
//  SECOND Byte
//	Bit 7  -  0 Digital/Scene/Temp  1 Analogue
//
//      Digital/Scene
//	Bits 6 - 0 Digital, 1 Scene
//	Bits 0-4 - Chn to operate
//
//      Analogue
//	Bits 4-6 - Channel
//	Bits 0-3 - Set Point
//
//  THIRD Byte
//    Associated value 1
//
//  Fourth Byte
//    Associated value, currently using remote Node only, i.e. associated value is a remote bode number when UDP type is R
//
//  Fifth Byte
//    Additional options.
//
// NOTE the same formating is used to encode triggers from thershold values
// and scheduled events.
//
// Note changes to this will result in changes to
//  parse.c
//  lib.js
//  possibly performTrigger in digital.c
//
#define DInBloc dig0cfgb1
#define DInCfgSize (dig1cfgb1-dig0cfgb1)

#define DInEntryCount 12

#define DInBlocEnd ( dig0cfgb1 + ( DInCfgSize * DInEntryCount ) )
#define DInActionOs 0

#define DIN_UDP_NONE  0x00
#define DIN_UDP_SENDUDP  0x80

#define DIN_B1_DWELL_MAKE( act, dwell, udp ) ((unsigned char)( act | dwell | udp ) )
#define DIN_B1_GROUP1_MAKE( act, udp ) ((unsigned char)( act | udp ) )

#define DIN_COMMAND_MASK  0x7F
// update if adding more commands
#define DIN_MAX_COMMAND  DIN_GROUP1_SEND_IR

#define DIN_GROUP_MASK  0x60
#define DIN_GROUP_1  0x00
#define DIN_GROUP_2  0x20
#define DIN_GROUP_3  0x40
#define DIN_GROUP_DWELL  0x60
#define DIN_B1_COMMAND_GROUP(b1)  (b1&DIN_GROUP_MASK)

//#define DIN_B1_ACTION_MASK  0x0F
//#define DIN_B1_ACTION(b1)  ( b1 & DIN_B1_ACTION_MASK )
#define DIN_COMMAND(b1)  (b1 & DIN_COMMAND_MASK)

#define DIN_SUBGROUP_MASK  0x1F

// special handling Dwell combines dwell command and dwell number
#define DIN_DWELL_MASK  (DIN_GROUP_DWELL | 0x18)
#define DIN_B1_DWELL_COMMAND(b1)  (b1&DIN_DWELL_MASK)
#define DIN_B1_DWELL_NR(b1)  (b1 & 0x07)
#define DIN_DWELL_ON  (DIN_GROUP_DWELL | 0x00)
#define DIN_DWELL_OFF  (DIN_GROUP_DWELL | 0x08)
#define DIN_DWELL_CANCEL  (DIN_GROUP_DWELL | 0x10)
#define DIN_DWELL_ALWAYS  (DIN_GROUP_DWELL | 0x18)

#define DIN_B1_GROUP1_COMMAND(b1)  (b1 & DIN_SUBGROUP_MASK)
#define DIN_GROUP1_NONE  (DIN_GROUP_1 | 0x00)
#define DIN_GROUP1_OFF  (DIN_GROUP_1 | 0x01)
#define DIN_GROUP1_ON  (DIN_GROUP_1 | 0x02)
#define DIN_GROUP1_MOMENTARY  (DIN_GROUP_1 | 0x03)
#define DIN_GROUP1_TOGGLE  (DIN_GROUP_1 | 0x04)
#define DIN_GROUP1_NEXT  (DIN_GROUP_1 | 0x07)
#define DIN_GROUP1_PREV  (DIN_GROUP_1 | 0x08)
#define DIN_GROUP1_SET_LOW_THRESHOLD  (DIN_GROUP_1 | 0x09)
#define DIN_GROUP1_SET_HIGH_THRESHOLD  (DIN_GROUP_1 | 0x0A)
#define DIN_GROUP1_ADJ_LOW_THRESHOLD  (DIN_GROUP_1 | 0x0B)
#define DIN_GROUP1_ADJ_HIGH_THRESHOLD  (DIN_GROUP_1 | 0x0C)
// should this be its own group?
#define DIN_GROUP1_SEND_IR  (DIN_GROUP_1 | 0x0D)
#define DIN_GROUP1_UP  (DIN_GROUP_1 | 0x0E)
#define DIN_GROUP1_DOWN  (DIN_GROUP_1 | 0x0F)
#define DIN_GROUP1_SET_DMX  (DIN_GROUP_1 | 0x10)
#define DIN_GROUP1_COUNT  (DIN_GROUP_1 | 0x11)
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
